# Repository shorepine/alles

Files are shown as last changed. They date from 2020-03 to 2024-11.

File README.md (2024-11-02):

# Alles - the mesh synthesizer

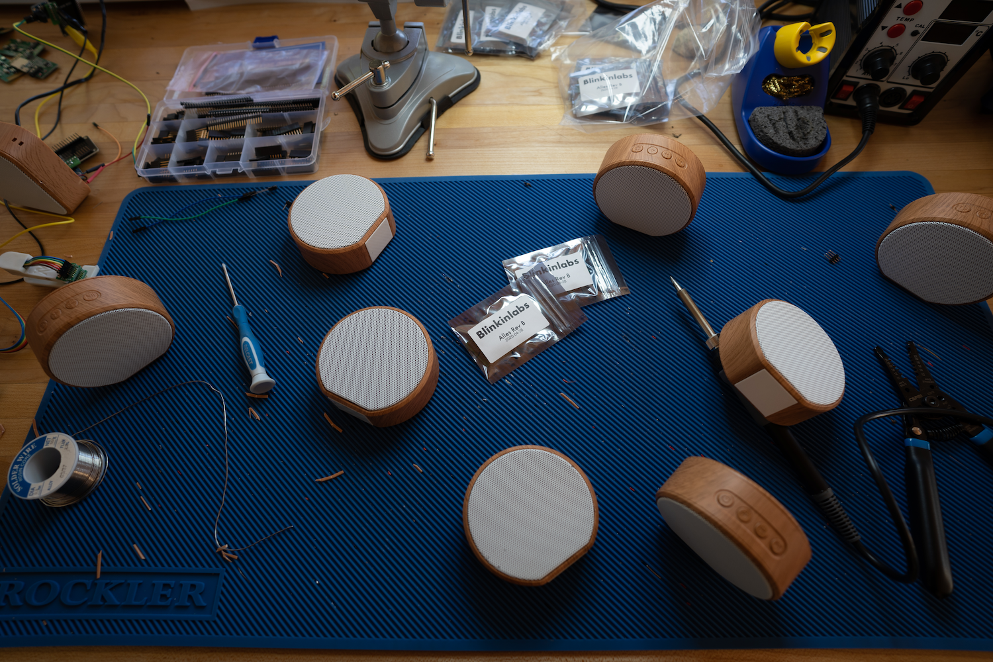
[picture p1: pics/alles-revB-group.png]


 [shore pine sound systems discord **Chat about Alles on our Discord!**](https://discord.gg/TzBFkUb8pG)

**Check out this video!**

The Alles mesh networking synthesizer - a field of sound at your control (https://www.youtube.com/watch?v=8CmcsQXHVEo "The Alles mesh networking synthesizer - a field of sound at your control")

**Alles** is a many-speaker distributed mesh synthesizer that responds over WiFi. Each synth -- there can be hundreds in a mesh -- supports up to 120 additive oscillators, with filters, modulation / LFOs and ADSRs per oscillator. The mesh of speakers can be composed of any combination of our custom hardware speakers or programs running on computers. The software and hardware are open source: you can build it yourself or buy a PCB from us. 

The synthesizers automatically form a mesh and listen to multicast WiFi messages. You can control the mesh from a host computer using any programming language or environments like Max or Pd. 

We intended their first use as distributed / spatial version of an [Alles Machine](https://en.wikipedia.org/wiki/Bell_Labs_Digital_Synthesizer) / [Atari AMY](https://www.atarimax.com/jindroush.atari.org/achamy.html) additive synthesizer where each speaker represents up to 64 partials, all controlled as a group or individually. But you can just treat them as dozens of individual synthesizers and do whatever you want with them. It's pretty fun!

Want to try it today? [Build your own Alles](#diy-alles), or [install the software version](#using-it----software-alles
), and then read our [getting started tutorial!](https://github.com/shorepine/alles/tree/main/getting-started.md)

## Synthesizer specs

Each individual synth is powered by the [AMY synthesizer library](https://github.com/shorepine/amy/blob/main/README.md), you can read more details there. 

## Using it -- hardware Alles

On first boot, each hardware speaker will create a captive wifi network called `alles-synth-X` where X is some ID of the synth. Join it (preferably on a mobile device), and you should get redirected to a captive wifi setup page. If not, go to `http://10.10.0.1` in your browser after joining the network. Once you tell each synth what the wifi SSID and password you want it to join are, it will reboot. You only need to do that once per synth.

## Using it -- software Alles

If you don't want to build or buy an Alles speaker, you can run Alles locally on your computer(s), as many as you want. As long as each copy of the software is running within the same network, they will automatically form in the mesh just like the hardware speakers. And the hardware and software speakers can be used interchangeably.

To build and run `alles` on a computer, simply clone this repository and

```bash
$ cd alles/main
$ make
$ ./alles
$ ./alles -h # shows all the useful commandline parameters, like changing which channel/sound card, or source IP address
```

## Controlling the mesh

**Check out our brand new [Getting Started](https://github.com/shorepine/alles/tree/main/getting-started.md) page for a tutorial!**

You can control every synth on the mesh from a single host, using UDP over WiFi. You can address any synth in the mesh or all of them at once with one message, or use groups. This method can be used in music environments like Max or Pd, or by musicians or developers using languages like Python, or for plug-in developers who want to bridge Alles's full features to DAWs.

Alles's wire protocol is a series of numbers delimited by ascii characters that define all possible parameters of an oscillator. This is a design decision intended to make using Alles from any sort of environment as easy as possible, with no data structure or parsing overhead on the client. It's also readable and compact, far more expressive than MIDI and can be sent over network links, UARTs, or as arguments to functions or commands. 

Alles accepts commands in ASCII, each command separated with a `Z` (you can group multiple messages in one, to avoid network overhead if that's your transport). Like so:

```
v0w4f440.0l0.9Z
```

See [AMY's readme](https://github.com/shorepine/amy/blob/main/README.md) for the full list of synth parameters.

## alles.py 

Alles comes with its own full-featured client, written in Python. Feel free to adapt it or use it in your own clients. It can be seen as documentation, an API as well as a testing suite. You simply `import alles` and can control the entire mesh.

```bash
$ python3
>>> import alles
>>> alles.drums() # plays a drum pattern on all synths
>>> alles.drums(client=2) # just on one 
```

To see more examples, check out our brand new [Getting Started](https://github.com/shorepine/alles/tree/main/getting-started.md) page.

## Addressing individual synthesizers

By default, a message is played by all booted synthesizers. But you can address them individually or in groups using the `client` parameter.

The synthesizers form a mesh that self-identify who is running. They get auto-addressed `client_id`s starting at 0 through 255. The first synth to be booted in the mesh gets `0`, then `1`, and so on. If a synth is shut off or otherwise no longer sends a heartbeat signal to the mesh, the `client_ids` will reform so that they are always contiguous. A synth may take 10-20 seconds to join the mesh and get assigned a `client_id` after booting, but it will immediately receive messages sent to all synths. 

The `client` parameter wraps around given the number of booted synthesizers to make it easy on the composer. If you have 6 booted synths, a `client` of 0 only reaches the first synth, `1` only reaches the 2nd synth, and a client of `7` reaches the 2nd synth (`7 % 6 = 1`). 

Setting `client` to a number greater than 255 allows you to address groups. For example, a `client` of 257 performs the following check on each booted synthesizer: `my_client_id % (client-255) == 0`. This would only address every other synthesizer. A `client` of 259 would address every fourth synthesizer, and so on.

You can read the heartbeat messages on your host if you want to enumerate the synthesizers locally, see `sync` below. 

## Timing & latency

Alles is not designed as a low latency real-time performance instrument, where your actions have an immediate effect on the sound. Changes you make on the host will take a fixed latency -- currently set at 1000ms by default -- to get to every synth. This fixed latency ensures that messages arrive to every synth -- both ESP32 based and those running on computers -- in the mesh in time to play in perfect sync, even though Wi-Fi's transmission latency varies widely. This allows you to have millisecond-accurate timing in your performance across dozens of speakers in a large space.

Your host should send along the `time` parameter of the relative time when you expect the sound to play. I'd suggest using the number of milliseconds since your host started, e.g. in Python:

```python
def millis():
    d = datetime.datetime.now()
    return int((datetime.datetime.utcnow() - datetime.datetime(d.year, d.month, d.day)).total_seconds()*1000)
```

If you're using `alles.py`, we do this for you!

If using Max, use the `cpuclock` object as the `time` parameter.

The first time you send a message with `time` the synth mesh uses it to figure out the delta between its time and your expected time. (If you never send a time parameter, you're at the mercy of WiFi jitter.) Further messages will be millisecond accurate message-to-message, but with the fixed latency. You can adapt `time` per client if you want to account for speed-of-sound delay. 

The `time` parameter is not meant to schedule things far in the future on the clients. If you send a new `time` that is outside 20,000ms from its expected delta, the clock base will re-compute. Your host should be the main "sequencer" and keep track of performance state and future events. 

Latency is adjustable, if you are comfortable with your network you can set it lower, or if using a local (127.0.0.1) connection, or directly sending messages in code, you can set it to 0. 

## Enumerating synths

The `sync` command (see `alles.sync()`) triggers an immediate response back from each on-line synthesizer. The response looks like `_s65201i4c248y2`, where s is the time on the client, i is the index it is responding to, y has battery status (for versions that support that) and c is the client id. This lets you build a map of not only each booted synthesizer, but if you send many messages with different indexes, will also let you figure the round-trip latency for each one along with the reliability. 

## WiFi & reliability for performances

UDP multicast is naturally 'lossy' -- there is no guarantee that a message will be received by a synth. Depending on a lot of factors, but most especially your wireless router and the presence of other devices, that reliability can sometimes go as low as 70%. For performance purposes, I highly suggest using a dedicated wireless router instead of an existing WiFi network. You'll want to be able to turn off many "quality of service" features (these prioritize a randomly chosen synth and will make sync hard to work with), and you'll want to in the best case only have synthesizers as direct WiFi clients. An easy way to do this is to set up a dedicated wireless router but not wire any internet into it. Connect your laptop or host machine to the router over a wired connection (via a USB-ethernet adapter if you need one), but keep your laptop's wifi or other internet network active. In your controlling software, you simply set the source network address to send and receive multicast packets from. `alles_util.py` has setup code for this. This will keep your host machine on its normal network but allow you to control the synths from a second interface.

If you're in a place where you can't control your network, you can mitigate reliability by simply sending messages N times. Sending multiple duplicate messages (with the same `time` parameter) do not have any adverse effect on the synths.

## Clients

Minimal Python example:

```python
import socket
multicast_group = ('232.10.11.12', 9294)
sock = socket.socket(socket.AF_INET, socket.SOCK_DGRAM)

def send(oscillator=0, freq=0, vel=1):
    sock.sendto("v%df%fl%fZ" % (oscillator, freq, vel), multicast_group)

def c_major(octave=2):
    send(oscillator=0,freq=220.5*octave)
    send(oscillator=1,freq=138.5*octave)
    send(oscillator=2,freq=164.5*octave)

```

See [`alles.py`](https://github.com/shorepine/alles/blob/main/alles.py) for a better example. Any language that supports sockets and multicast can work, I encourage pull requests with new clients!

You can also easily use it in Max or Pd:

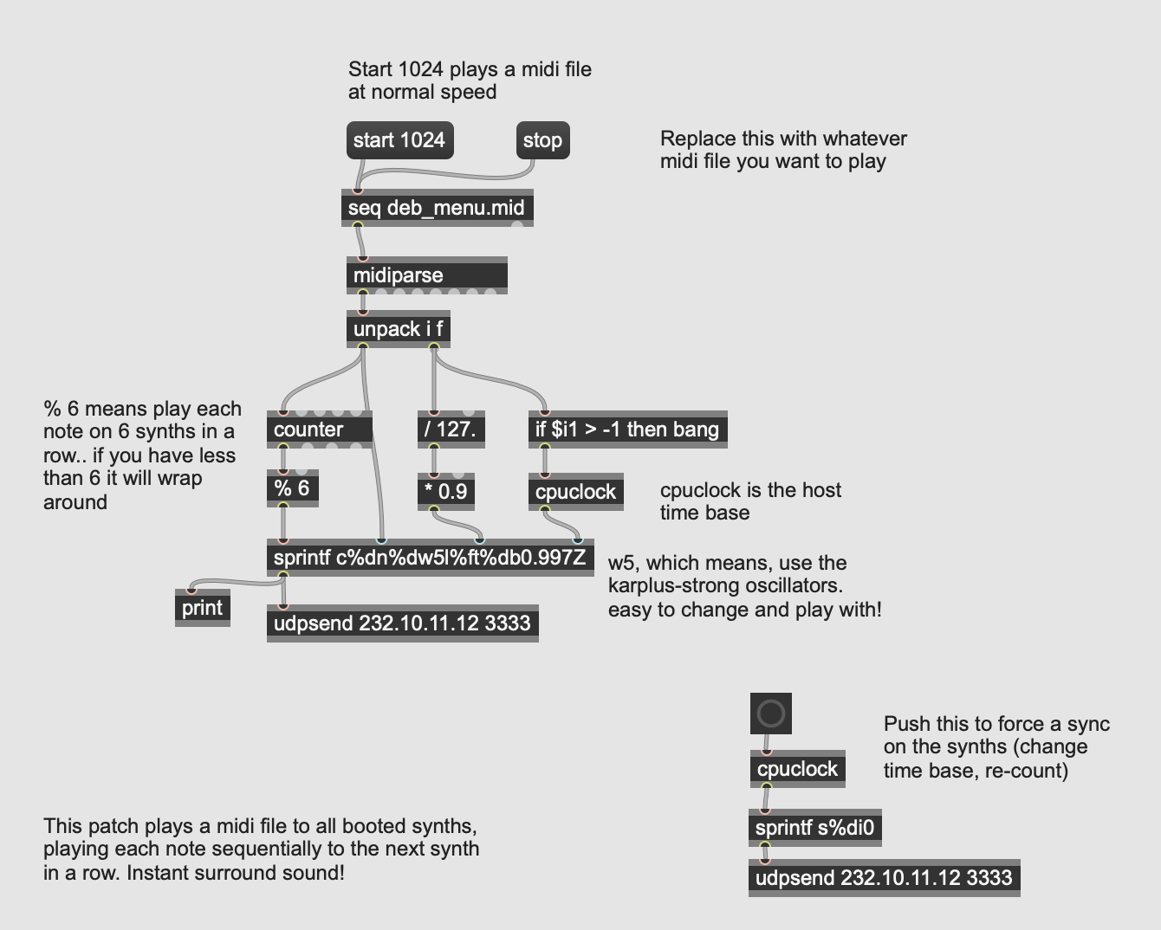
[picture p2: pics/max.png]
Max


# Synthesizer Details

See [AMY's readme](https://github.com/shorepine/amy/blob/main/README.md) for more details on the synthesizer itself.

# Get your own Alles!

**[Read here how to install a PCB into a speaker shell!](speaker-assembly.md)**

If you want the small circular speakers shown on this page and videos, they are easy to get. Here's a link to them on Alibaba: [the round A60s](https://www.alibaba.com/product-detail/A60-Wooden-Grain-Portable-Wireless-Bluetooth_1600291216741.html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) – the [square-shaped A70s](https://www.alibaba.com/product-detail/A70-Wood-Speaker-Grain-Portable-Wireless_1600291333969.html) also work! You then can buy an Alles PCB from us with no terminals for speaker and battery -- the connections for the shell solder directly to the board. It takes me about 3 minutes to assemble the Alles PCB inside the A60 or A70 speaker. To do it this way, you only need a wire stripper, a small screwdriver and a soldering iron. 
 
**IMPORTANT:** Alles is sold on a "best effort" community support basis. We will send you working PCBs with the latest Alles firmware loaded on them. Anything that happens after that is up to the community to help with. Alles requires a little bit of computer and networking know-how to get going. We've made it as easy as possible, we hope, but we know we have more work to do before this is ready for a very wide audience. Please use GitHub issues for anything you're having trouble with and we'll do our best to help you figure it out. 

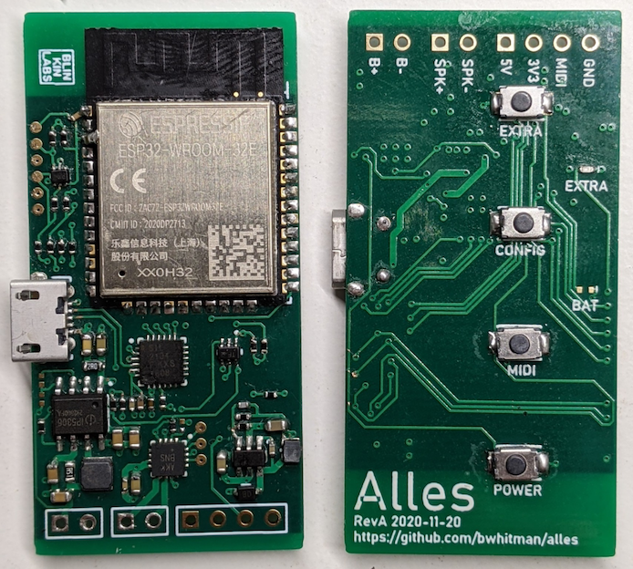
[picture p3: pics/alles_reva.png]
blinkinlabs PCB


## DIY Alles

It's very simple to make one yourself with parts you can get from electronics distributors like Sparkfun, Adafruit or Amazon. 

To make an Alles synth yourself, you need

* [ESP32 dev board (any one will do, but you want pins broken out)](https://www.amazon.com/gp/product/B07Q576VWZ/) (pack of 2, $7.45 each). Try to get a 8MB flash on yours if you want to have over-the-air updating.
* [The Adafruit I2S mono amplifier](https://www.adafruit.com/product/3006) ($5.95)
* [4 ohm speaker, this one is especially nice](https://www.parts-express.com/peerless-by-tymphany-tc6fd00-04-2-full-range-paper-cone-woofer-4-ohm--264-1126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) ($9.77, but you can save a lot of money here going lower-end if you're ok with the sound quality). I also like speakers with prebuilt cases, like [these bookshelf speakers](https://www.amazon.com/Pyle-PCB3BK-100-Watt-Bookshelf-Speakers/dp/B000MCGF1O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).
* A breadboard, custom PCB, or just some hookup wire!

A 5V input (USB battery, USB input, rechargeable batteries direct to power input) powers both boards and speaker at pretty good volumes. A 3.7V LiPo battery will also work, but note the I2S amp will not get as loud (without distorting) if you give it 3.7V. If you want your DIY Alles to be portable, I recommend using a USB battery pack that does not do [low current shutoff](https://www.element14.com/community/groups/test-and-measurement/blog/2018/10/15/on-using-a-usb-battery-for-a-portable-project-power-supply). The draw of the whole unit at loud volumes is around 90mA, and at idle 40mA. 

Wire up your DIY Alles like this (I2S -> ESP)

```
LRC -> GPIO25
BCLK -> GPIO26
DIN -> GPIO27
GAIN -> I2S Vin (i jumper this on the I2S board)
SD -> not connected
GND -> GND
Vin -> Vin / USB / 3.3 (or direct to your 5V power source)
Speaker connectors -> speaker
```

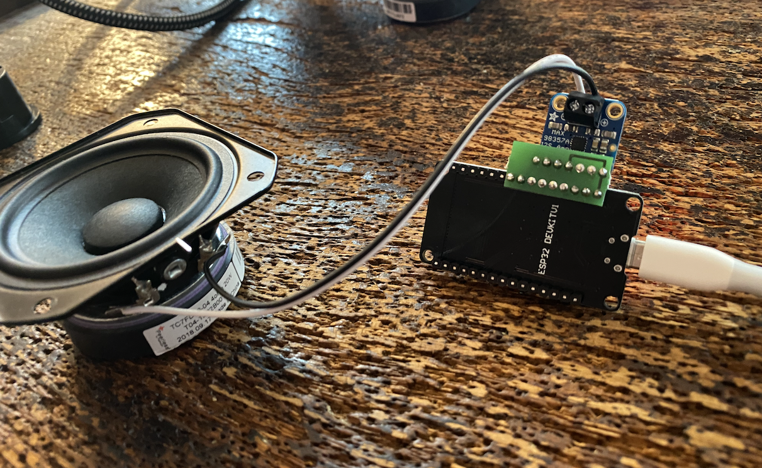
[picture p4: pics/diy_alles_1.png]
DIY Alles 1

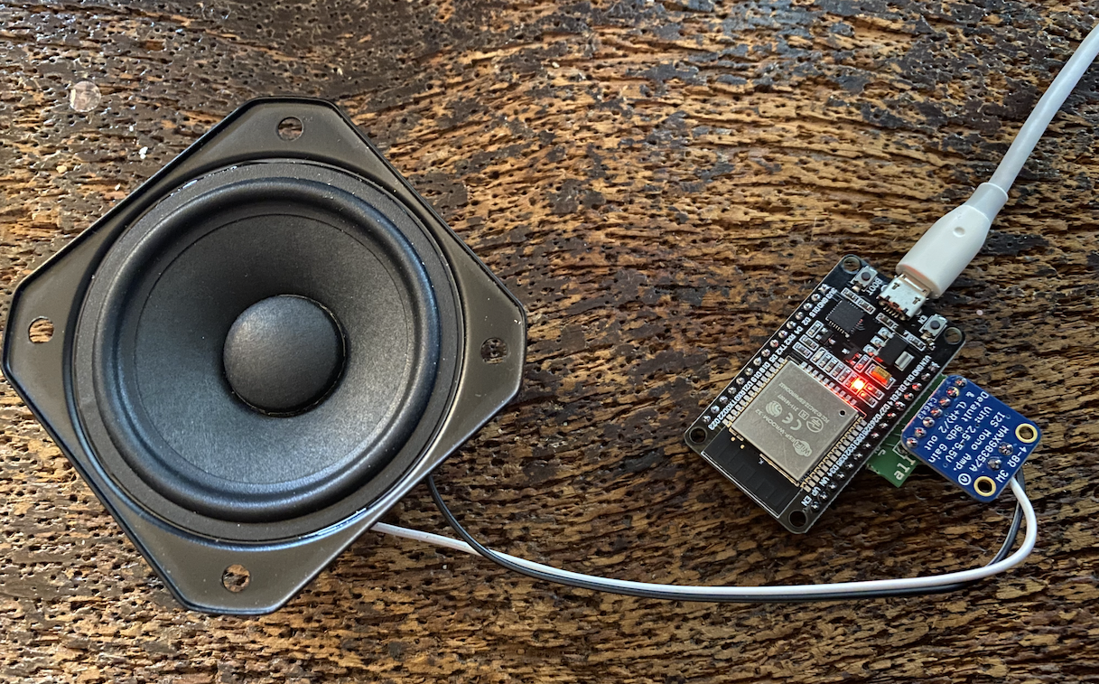
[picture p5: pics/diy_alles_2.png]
DIY Alles 2


### DIY bridge PCB

*You don't need this PCB made to build a DIY Alles!* -- it will work with just hookup wire. But if you're making a lot of DIY Alleses want more stability, I had a tiny little board made to join the boards together, like so:

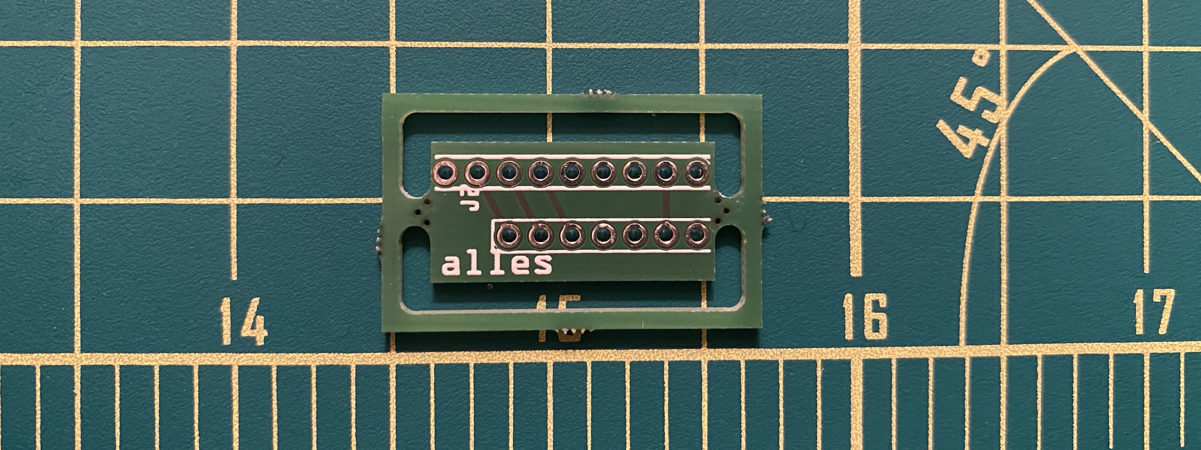
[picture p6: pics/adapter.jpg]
closeup


This assumes you're using the suggested ESP32 dev board with its pin layout. If you use another one, you can probably change the GPIO assignments in `alles.h`. Fritzing file in the `pcbs` folder of this repository, and [it's here on Aisler](https://aisler.net/p/TEBMDZWQ). This is a lot more stable and easier to wire up than snipping small bits of hookup wire, especially for the GAIN connection. 

## Disabling OTA for 4MB boards

If you are using your own dev board and it has less than 8MB of flash (4MB is common), first overwwrite `alles_partitions.csv` with the contents of`alles_4mb_partitions.csv` as well as run `idf.py menuconfig` and change the flash size from 8MB to 4MB (in Serial Flasher Config) -- this will disable the OTA firmware upgrading, but will otherwise work fine. The binary for Alles is almost 4MB total and OTA needs space for two copies to be stored on the flash.

## ESP32 Firmware

Alles is completely open source, and can be a fun platform to adapt beyond its current capabilities. 

You can upgrade the firmware or write your own using the USB connection. [See the guide on flashing a hardware Alles speaker](https://github.com/shorepine/alles/tree/main/alles-flashing.md) (either DIY or one of ours). 

## THANK YOU TO

* Alles would not be possible without the help of [DAn Ellis](https://research.google/people/DanEllis/), who helped me with most of the oscillator stack, a lot of deep dives into our algorithm synth, and many great ideas / fixes on the ESP32 code.
* Douglas Repetto
* [Raph Levien](https://www.levien.com) for his work on [MSFA](https://github.com/google/music-synthesizer-for-android) which gave us a lot of hints for our FM implementation
* mark fell
* [esp32 WiFi Manager](https://github.com/tonyp7/esp32-wifi-manager)
* kyle mcdonald 
* Matt Mets / [Blinkinlabs](https://blinkinlabs.com)

## TODO

* ~~power button~~
* ~~wifi setup should ask for default power saving / latency -- no for now~~
* ~~remove distortion at higher amplitudes for mixed sine waves~~
* ~~FM~~
* ~~should synths self-identify to each other? would make it easier to use in Max~~
* ~~see what you can do about wide swings of UDP latency on the netgear router~~
* ~~envelopes / note on/offs / LFOs~~
* ~~confirm UDP still works from Max/Pd~~
* ~~bandlimit the square/saw/triangle oscillators~~
* ~~karplus-strong~~ 
* ~~wifi hotspot mode for in-field setup~~
* ~~broadcast UDP for multiples~~
* ~~dropped packets~~
* ~~sync and enumerate across multiple devices~~
* ~~addresses / communicate to one or groups, like "play this on half / one-quarter / all"~~
* ~~do what i can about timing / jitter - sync time? timed messages?~~
* ~~case / battery setup~~
* ~~overloading the volume (I think only on FM) crashes~~
* ~~UDP message clicks~~
* desktop USB flasher
* BT / app based config instead of captive portal (later)

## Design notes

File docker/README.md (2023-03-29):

# Docker container for Alles production

These scripts build the Alles firmwware in a container, using a fully isloated
ESP-IDF toolchain.

To build it, you'll need a Linux computer with [Docker](https://docs.docker.com/engine/install/ubuntu/) installed. Any OS capable of running Docker can work to build the image, however a Linux-based system is required to flash devices through the container.

You will aslo need make and git; you can install them on Ubuntu like so:

    sudo apt update
    sudo apt install build-essential git

Once you have these prerequisites, clone the repository, then build the Docker image:

    git clone https://github.com/blinkinlabs/alles.git
    cd alles/docker
    make build-docker

This will take a little while. Once it is done, you can build the firmware in the container:

    make build

Once the firmware is built, flash an attached Alles device:

    make flash

Note: The above assumes that the USB-to-serial converter in the Alles was detected as /dev/ttyUSB0; if it was mounted somewhere else, you can specify the position:

    PORT=/dev/ttyXXXX make flash

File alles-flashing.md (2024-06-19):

# Alles Flashing HOWTO

This page will help you upgrade your own firmware on an Alles hardware speaker.

## Upgrading firmware wirelessly / OTA

**If you have a recent model (you received it after November 2021), or flashed your firmware after November 2021, you can upgrade your firmware over the internet wirelessly, called OTA, "over-the-air."**

After you first set up wifi (and make sure your speaker is on a wifi network that can connect to the internet,) if you turn off, then on the speaker, then press the + button while the "joining wifi" tones are playing (in the few seconds before it plays the turn-on bleep), the speaker will connect to the internet and download the [latest released Alles speaker firmware](https://github.com/shorepine/alles/blob/main/ota/alles.bin) right to the device, then reboot. It takes about a minute, and you'll hear a different (sometimes glitchy sounding -- that's ok --) repeating tone while it works. 

## Upgrading firmware over USB

If you want to write your own Alles firmware, or have a speaker before December 2021 and need to get it to support wireless upgrading, follow these directions:

The back of the hardware speaker has a micro-USB plug you use for charging. It also can be used to upgrade the firmware. Once you upgrade an Alles speaker to a recent version, you can use the wireless / OTA flashing method going forward. 

To do this, you need to set up the following things:

### Set up ESP-IDF

ESP-IDF is the set of open source tools and libraries that work on the CPU powering Alles, the ESP32. You should first install ESP-IDF on your system if you haven't already. 

Download the supported version of ESP-IDF. That is currently 5.2. [You can download it directly here.](https://dl.espressif.com/github_assets/espressif/esp-idf/releases/download/v5.2/esp-idf-v5.2.zip) Unpack it to a folder. I like to keep them in `~/esp/`, as you'll likely want to use different versions eventually. So we'll assume it's in `~/esp/esp-idf-v5.2`.

```
# install ESP-IDF that comes with our repository
~/esp/esp-idf-v5.2/install.sh esp32
source ~/esp/esp-idf-v5.2/export.sh
```

If you have trouble, for more info, or for other platforms, you should follow [the detailed instructions to download and set up `esp-idf`](http://esp-idf.readthedocs.io/en/latest/get-started/). 

### Get the UART drivers

If using macOS, you'll want to also install the [CP210X drivers](https://www.silabs.com/developers/usb-to-uart-bridge-vcp-drivers) if you haven't already. 

### Get the Alles repository

You likely already have this, but if not, [clone this repository](https://github.com/shorepine/alles).

### Get a real micro-USB cable 

The cable you may have received from us for the hardware speaker is charge only. Find a longer micro-USB cable that transmits data and connect it to the computer and speaker. 

### Flash

Then, in the `esp` folder you created during installing the ESP-IDF above (e.g. `cd ~/esp`), run `. ./esp-idf-v5.2/export.sh`. Now, in the same terminal window (export.sh sets some environment variables), cd back into the alles repository folder you downloaded and run `idf.py flash` to build and flash to the board. It will take a couple of minutes and show you progress. The board will reboot into the latest firmware. 

(If the flashing process doesn't work, it's likely not finding your UART location. Type `ls /dev/*usb*` to find something like `/dev/tty.usbserial.XXXXX` or `/dev/cu.usbserialXXXX`.  You'll want to find the tty that appears when you connect the speaker to computer. Copy this location and try flashing again with `idf.py -p /dev/YOUR_SERIAL_TTY flash`.)

### Monitor

If you want to see debugging messages, use `idf.py -p /dev/YOUR_SERIAL_TTY monitor` to reboot the board and see stdout/stderr. Use Ctrl-] to exit the monitor.

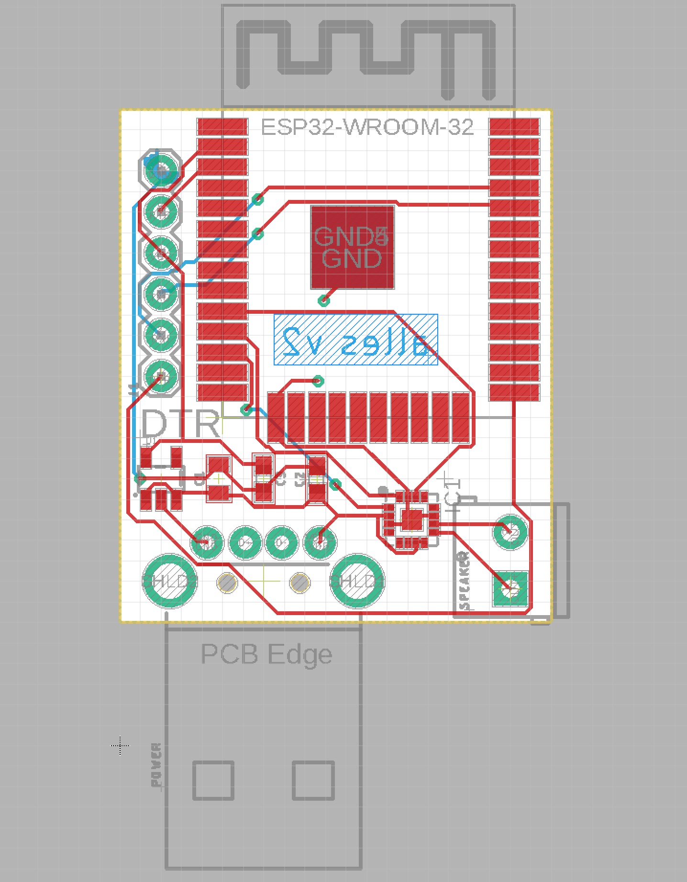
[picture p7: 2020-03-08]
pics/alles-board.jpg

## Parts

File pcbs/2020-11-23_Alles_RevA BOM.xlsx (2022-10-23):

Designator | Comment | Manufacturer | PartNumber | Digi-Key Part Number | LCSC PartNumber | Description | Pins | Quantity | Model:Footprint | Case/Package
C1, C4, C7 | 0.10uF | Murata Electronics North America | GRM152R61A104ME19D | 490-10009-1-ND |  | CAP CER 0.1UF 10V X5R 0402 | 2 | 3 |  | 0402
C2, C6, C8, C18 | 10uF | Murata Electronics North America | GRM188C81A106MA73D, GRM188R61A106KE69D | 490-7197-1-ND, 490-10474-1-ND |  | CAP CER 10UF 10V X6S 0603, CAP CER 10UF 10V X5R 0603 | 2 | 4 |  | 0603
C3 | 1uF | Murata Electronics North America | GRM155R61A105KE15D | 490-3890-1-ND |  | CAP CER 1UF 10V X5R 0402 | 2 | 1 |  | 0402
C5 | 4.7uF | Murata Electronics North America | GRM155R60J475ME47D | 490-5915-1-ND |  | CAP CER 4.7UF 6.3V X5R 0402 | 2 | 1 |  | 0402
C9, C10, C11, C12, C21 | 22uF | Murata Electronics North America | GRM187R61A226ME15D | 490-13243-1-ND |  | CAP CER 22UF 10V X5R 0603 | 2 | 5 |  | 0603
C22 | 33pF | Murata Electronics North America | GRM1555C1E330JA01D | 490-6177-1-ND |  | CAP CER 33PF 25V NP0 0402 | 2 | 1 |  | 0402
D1 | ZHCS400TA | DiodesIncorporated |  |  |  | Schottky Barrier Diode, 40 V, 0.4 A, -55 to 150 degC, 2-Pin SMD, RoHS, Tape and Reel | 2 | 1 | SOD-323, 2-Leads, Body 1.7x1.3mm, Lead Span 2.5mm
DS1 | BL-HUB37A-AV-TRB | BrtLed(佰鸿) | BL-HUB37A-AV-TRB |  | C165980 | LED, 0402, Super Red, 50mcd@20mA, 627~637nm | 2 | 1 | 0402 LED, generic
DS3 | BL-HB337A-AV-TRB | BrtLed(佰鸿) | BL-HB337A-AV-TRB |  | C165977 | LED, 0402, Blue, 20mcd@5mA, 465~470nm | 2 | 1 | 0402 LED, generic
J1 | A01SB741B1-267 | Unknown/Generic | Unknown/Generic |  |  | Micro USB B type 四脚全插牛角 | 11 | 1 | micro usb B type
L2 | 1uH | Sunlord | SWPA3010S1R0NT |  | C57625 | 1uH ±30% 1.4A 85mΩ SMD,3.0x3.0x1.0mm Power Inductors RoHS | 2 | 1 |  | SMD,3.0x3.0x1.0mm
L3 | 6.8uH | Changjiang Microelectronics Tech | FNR201610S6R8MT |  | C167675 | 6.8uH ±20% 520mA 816mΩ SMD,2.0x1.6x1.0mm Power Inductors RoHS | 2 | 1 |  | SMD,2.0x1.6x1.0mm
P1 | Header 2 |  |  |  |  | Header, 2-Pin | 2 | 1 | Connector; Header; 2 Position
P2 | Battery |  |  |  |  | Header, 2-Pin | 2 | 1 | Connector; Header; 2 Position
P3 | Header 4 |  |  |  |  | Header, 4-Pin | 4 | 1 | Connector; Header; 4 Position
Q1 | EMX1DXV6T1G | On Semiconductor | EMX1DXV6T1G |  |  | Dual NPN General Purpose Amplifier Transistors, 6-Pin SOT-563, Pb-Free, Tape and Reel | 6 | 1 | SOT23, 6-Leads, Body 1.6x1.2mm, Pitch 0.5mm
Q2 | NTJD5121NT1G | On Semiconductor |  |  |  | MOSFET 2N-CH 60V 0.295A SOT363 | 6 | 1
R1, R2, R4, R5, R6, R7, R21 | 0.0 | Panasonic Electronic Components | ERJ-2GE0R00X | P0.0JCT-ND |  | RES SMD 0.0OHM JUMPER 1/10W 0402 | 2 | 7 |  | 0402
R3, R11, R13, R15, R22, R23 | 10k | Panasonic Electronic Components | ERJ-2GEJ103X | P10KJCT-ND |  | RES SMD 10K OHM 5% 1/10W 0402 | 2 | 6 |  | 0402
R8 | 1.5k | Panasonic Electronic Components | ERJ-2GEJ152X | P1.5KJCT-ND |  | RES SMD 1.5K OHM 5% 1/10W 0402 | 2 | 1 |  | 0402
R9 | 0.51 | Panasonic Electronic Components | ERJ-3BQFR51V | P17401CT-ND |  | RES SMD 0.51 OHM 1% 1/4W 0603 | 2 | 1 |  | 0603
R10 | 2 | Panasonic Electronic Components | ERJ-3BQJ2R0V | P17414CT-ND |  | RES SMD 2 OHM 5% 1/4W 0603 | 2 | 1 |  | 0603
R12 | 1k | Panasonic Electronic Components | ERJ-2GEJ102X | P1.0KJCT-ND |  | RES SMD 1K OHM 5% 1/10W 0402 | 2 | 1 |  | 0402
R14, R16 | 100k | Panasonic Electronic Components | ERJ-2GEJ104X | P100KJCT-ND |  | RES SMD 100K OHM 5% 1/10W 0402 | 2 | 2 |  | 0402
R17 | 127k | Panasonic Electronic Components | ERJ-2RKF1273X | P127KLCT-ND |  | RES SMD 127K OHM 1% 1/10W 0402 | 2 | 1 |  | 0402
R18 | 23.7k | Panasonic Electronic Components | ERJ-2RKF2372X | P23.7KLCT-ND |  | RES SMD 23.7K OHM 1% 1/10W 0402 | 2 | 1 |  | 0402
R19, R20 | 2.1k | Panasonic Electronic Components | ERJ-2RKF2101X | P2.10KLCT-ND |  | RES SMD 2.1K OHM 1% 1/10W 0402 | 2 | 2 |  | 0402
SW1, SW2, SW3, SW4 | TS-1185 | XKB | TS-1185 |  |  | Tact Switch, 3x4mm, no alignment pin, turtle style | 2 | 4 | 3x4x2mm Tact Switch, no alignment pin
U1 | ESP32-WROOM-32E(4MB) | Espressif Systems | ESP32-WROOM-32E(4MB) |  | C701341 | 32-bit MCU & 2.4 GHz Wi-Fi & Bluetooth/Bluetooth LE | 39 | 1 | ESP32 module, with shorter solder pads
U2 | MAX98357AETE+ |  |  |  |  | IC AMP CLASS D MONO 3.2W 16TQFN | 17 | 1
U3 | BL9352A | Belling | BL9352A |  | C193985 | 45V, 1.6MHz, 600mA Step-Down Converter | 6 | 1 | SOT23, 6-Leads, Body 2.92x2.80mm, Pitch 0.95mm, IPC Medium Density
U4 | IP5306 | INJOINIC | IP5306 |  | C181692 | Fully-Integrated Power Bank System-On-Chip with 2.1A charger, 2.4A discharger | 9 | 1 | SOP, 8-Leads, Body 5.00x3.90mm, Pitch 1.27mm, Thermal Pad 3.10x2.21mm, IPC Medium Density
U15 | CP2104-F03-GM | Silicon Labs | CP2104-F03-GM |  |  | Single-Chip USB to UART Bridge, 4 Dig I/O Pins, Internal Oscillator, 1024 Bytes EEPROM, -40 to 85 degC, 24-pin QFN | 25 | 1 | QFN, 24-Leads, Body 4x4mm, Pitch 0.5mm, Thermal Pad 2.68x2.68mm, IPC Low Density

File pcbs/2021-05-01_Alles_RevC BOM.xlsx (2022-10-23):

Designator | Comment | Manufacturer | PartNumber | Digi-Key Part Number | LCSC PartNumber | Description | Pins | Quantity | Model:Footprint | Case/Package
C1, C10, C12, C14 | 4.7uF | Murata Electronics North America | GRM188R61A475KE15D | 490-10477-1-ND |  | CAP CER 4.7UF 10V X5R 0603 | 2 | 4 |  | 0603
C2, C6, C13 | 10uF | Murata Electronics North America | GRM188R61A106KE69D, GRM188R60J106ME84D | 490-10474-1-ND, 490-7316-1-ND |  | CAP CER 10UF 10V X5R 0603, CAP CER 10UF 6.3V X5R 0603 | 2 | 3 |  | 0603
C3 | 1uF | Murata Electronics North America | GRM155R61A105KE15D | 490-3890-1-ND |  | CAP CER 1UF 10V X5R 0402 | 2 | 1 |  | 0402
C4, C7, C9, C11, C15 | 0.10uF | Murata Electronics North America | GRM152R61A104ME19D, GRM155R61C104KA88J | 490-10009-1-ND, 490-6310-1-ND |  | CAP CER 0.1UF 10V X5R 0402, CAP CER 0.1UF 16V X5R 0402 | 2 | 5 |  | 0402
C5 | 4.7uF | Murata Electronics North America | GRM185R61A475KE11D | 490-11988-1-ND |  | CAP CER 4.7UF 10V X5R 0603 | 2 | 1 |  | 0603
C8, C16 | 22uF | Murata Electronics North America | GRM187R61A226ME15D | 490-13243-1-ND |  | CAP CER 22UF 10V X5R 0603 | 2 | 2 |  | 0603
D1 | MBR0520LT1G |  |  |  |  | DIODE SCHOTTKY 20V 500MA SOD123 | 2 | 1 |  | SOD-123-2
J1 | A01SB741B1-267 | Unknown/Generic | Unknown/Generic |  |  | Micro USB B type 四脚全插牛角 | 11 | 1 | micro usb B type
L2, L3 | 1uH | Changjiang Microelectronics Tech | FNR201610S1R0MT |  | C167670 | 1uH ±20% 1.45A 114mΩ SMD,2.0x1.6x1.0mm Power Inductors RoHS | 2 | 2 |  | SMD,2.0x1.6x1.0mm
P1 | Header 2 |  |  |  |  | Header, 2-Pin | 2 | 1 | Connector; Header; 2 Position
P2 | Battery |  |  |  |  | Header, 2-Pin | 2 | 1 | Connector; Header; 2 Position
P3 | Header 4 |  |  |  |  | Header, 4-Pin | 4 | 1 | Connector; Header; 4 Position
Q1 | EMX1DXV6T1G | On Semiconductor | EMX1DXV6T1G |  |  | Dual NPN General Purpose Amplifier Transistors, 6-Pin SOT-563, Pb-Free, Tape and Reel | 6 | 1 | SOT23, 6-Leads, Body 1.6x1.2mm, Pitch 0.5mm
Q2 | DMC3400SDW-7 | Diodes Inc. |  |  |  | MOSFET N/P-CH 30V SOT363 | 6 | 1
Q3 | DMP3099L-13 |  |  |  |  | MOSFET P-CH 30V 3.8A SOT23 | 3 | 1 |  | TO-236-3
R1, R4, R14, R16, R18, R19, R20, R25 | 100k | Panasonic Electronic Components | ERJ-2GEJ104X | P100KJCT-ND |  | RES SMD 100K OHM 5% 1/10W 0402 | 2 | 8 |  | 0402
R2 | 0.0 | Panasonic Electronic Components | ERJ-2GE0R00X | P0.0JCT-ND |  | RES SMD 0.0OHM JUMPER 1/10W 0402 | 2 | 1 |  | 0402
R3, R5, R11, R13, R15, R21, R22 | 10k | Panasonic Electronic Components | ERJ-2GEJ103X | P10KJCT-ND |  | RES SMD 10K OHM 5% 1/10W 0402 | 2 | 7 |  | 0402
R8 | 1M | Panasonic Electronic Components | ERJ-2GEJ105X | P1.0MJCT-ND |  | RES SMD 1M OHM 5% 1/10W 0402 | 2 | 1 |  | 0402
R26 | 2k | Panasonic Electronic Components | ERJ-2GEJ202X | P2.0KJCT-ND |  | RES SMD 2K OHM 5% 1/10W 0402 | 2 | 1 |  | 0402
R27 | 100 | Panasonic Electronic Components | ERJ-2RKF1000X | P100LCT-ND |  | RES SMD 100 OHM 1% 1/10W 0402 | 2 | 1 |  | 0402
SW1, SW2, SW3, SW4 | TS-1185 | XKB | TS-1185 |  |  | Tact Switch, 3x4mm, no alignment pin, turtle style | 2 | 4 | 3x4x2mm Tact Switch, no alignment pin
U1 | ESP32-WROOM-32E(4MB) | Espressif Systems | ESP32-WROOM-32E(4MB) |  | C701341 | 32-bit MCU & 2.4 GHz Wi-Fi & Bluetooth/Bluetooth LE | 39 | 1 | ESP32 module, with shorter solder pads
U2 | MAX98357AETE+ |  |  |  |  | IC AMP CLASS D MONO 3.2W 16TQFN | 17 | 1
U3 | ADP2108AUJZ-3.3-R7 |  | ADP2108AUJZ-3.3-R7 |  | C143875 | Compact, 600 mA, 3 MHz, Step-Down DC-to-DC Converter, 3.3V | 5 | 1 | SOT23, 5-Leads, Body 2.90x2.80mm, Pitch 0.95mm, IPC Medium Density
U4 | MIC2875-5.0YMT-T5 | Microchip | MIC2875-5.0YMT-T5 |  |  | 4.8A ISW, Synchronous Boost Regulator with Bi-Directional Load Disconnect | 9 | 1
U5 | MCP73832T-2ACI/OT |  |  |  |  | IC LI-ION/LI-POLY CTRLR SOT23-5 | 5 | 1 |  | SOT-23
U6 | XB5307H | XySemi | XB5307H |  | C154942 | Single-cell Li-ion/Li-polymer rechargeable battery pack protection chip w2.90V cutorff | 6 | 1 | SOT23, 6-Leads, Body 2.92x2.80mm, Pitch 0.95mm, IPC Medium Density
U15 | CP2104-F03-GM | Silicon Labs | CP2104-F03-GM |  |  | Single-Chip USB to UART Bridge, 4 Dig I/O Pins, Internal Oscillator, 1024 Bytes EEPROM, -40 to 85 degC, 24-pin QFN | 25 | 1 | QFN, 24-Leads, Body 4x4mm, Pitch 0.5mm, Thermal Pad 2.68x2.68mm, IPC Low Density

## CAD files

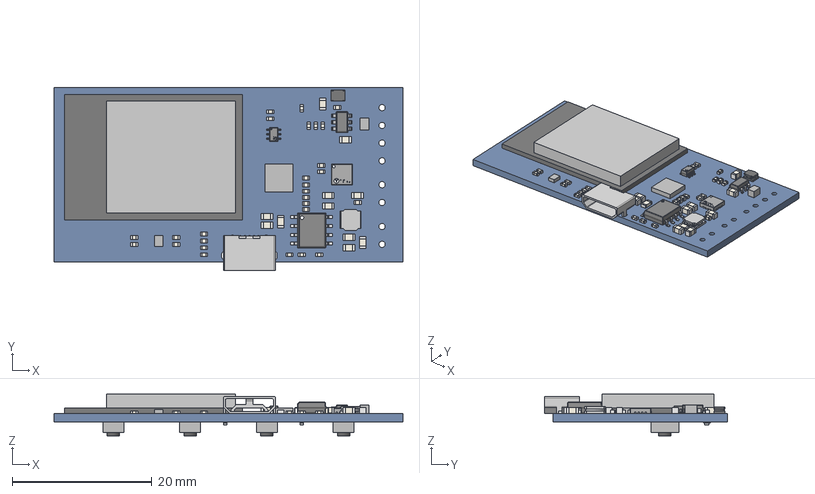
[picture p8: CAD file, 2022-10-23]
pcbs/2020-11-23_Alles_RevA.step
50.0 x 26.3 x 6.00 mm
Extruded x 131
pins
logo
Open_CASCADE_STEP_translator_6.8_3.1.1
Leader x 14
SWPA3010S
FNR201610S_(estimate)_v2
Open_CASCADE_STEP_translator_6.8_2.1
Open_CASCADE_STEP_translator_6.8_2.2.1
A01SB741B1-267_v1
circle
logo002

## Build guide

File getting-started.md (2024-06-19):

# Alles Speaker RevB getting started notes

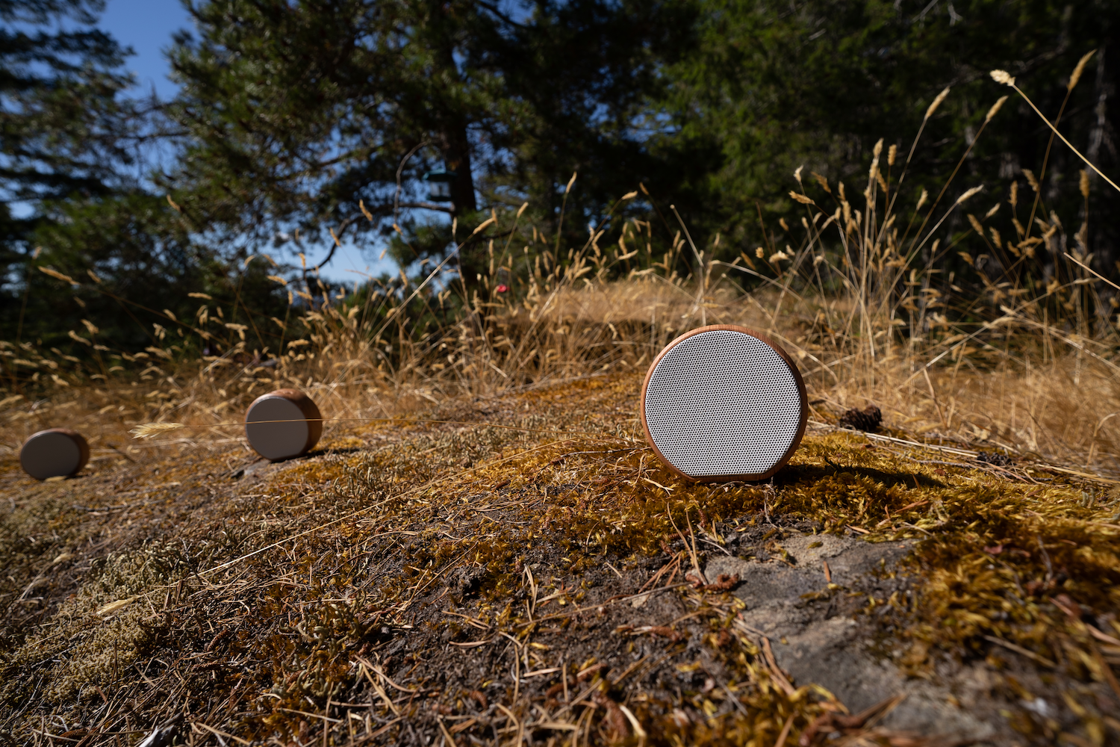
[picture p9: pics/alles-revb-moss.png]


Hello! You're the lucky owner of at least one Alles speaker. This guide will help you get started.

## The Speaker

### Wait, I don't have a speaker yet

That's ok! You can run a software speaker too. Skip down to the section [Setup](#setup) and then do [Alles on your computer](#alles-on-your-computer) to run a software version of the speaker. You can then keep following this guide no problem.

### Back to the hardware speaker 

[Read here on how to get your Alles PCB into a speaker shell!](speaker-assembly.md)

Each Alles speaker has four buttons up top and a USB micro receptacle on back. 

Before getting going, let's make sure the speaker is charged or charging. Simply plug the included USB cable between the speaker and any USB charge point, like a phone charger. (If you hook it into a computer, the speaker will show up as a USB device for debugging and upgrades, but you don't have to worry about that for now -- all control happens wirelessly.) The battery will last "a few hours" making constant music and longer with sparse or silence. It shouldn't take more than an hour or so to charge. If the power button does not make any noise, it's probably a dead battery.

The row of buttons up top, facing the speaker, are power, volume + and -, and WiFi setup (the play/pause). Volume can be set with those buttons or using `alles.volume()` from your compositions. Using `alles.volume()` will override whatever you set with the buttons.

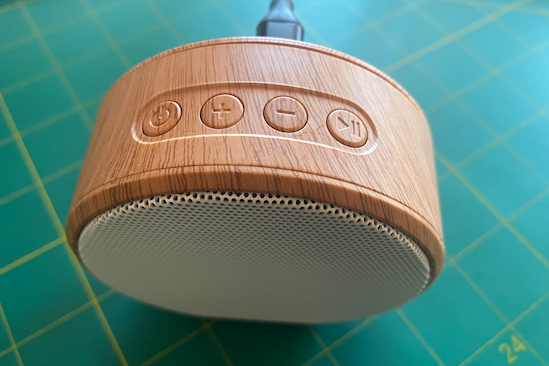
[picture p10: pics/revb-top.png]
Picture of speaker


The power button turns the speaker off and on. When you turn it on, it will re-join the network and mesh. 

The WiFi button will forget the WiFi details, if any were stored, and put the device into WiFi setup mode. This is the default if no WiFi has yet been set. 

## Join a WiFi network

If this is your first time using the speaker, you'll need to tell it which WiFi network to join. You can easily change this later, but once you set it, you don't need to set it again. 

Press the power button. You'll start to hear a "chime noise" repeating. This is the "searching for WiFi" sound, and will play until it finds a WiFi point, or the power button is hit again, or if two minutes goes by, at which point it'll shut off again. 

If you've already set a WiFi network, after about a few seconds the chime noise will end and you'll hear a "bleep" tone and then silence. That means the WiFi network has been joined and everything is ready to go.

If you haven't set WiFi yet, now open your nearest mobile phone or any WiFi device with a browser. Go to join a new WiFi network on your device and you'll see a network listed called `alles-synth-XXXXXX` where `XXXXXX` is a unique string per speaker (useful when you have many speakers!). Join that network. On most devices (iPhones, Androids especially) after a few seconds, a browser window will appear with a login page. This is like when you join a hotel's network or other captive portal. If the page never appears, try going to `http://10.10.0.1` in your browser after joiining the network.

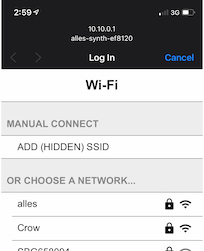
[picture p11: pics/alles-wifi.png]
Alles WiFi settings


Wait a few seconds for the login page to populate with all the nearby WiFi stations it finds. After you see the one you want the speaker to join, tap it and carefully enter its password. This should be the same network as the computer you're going to control Alles from. After a few moments, the speaker should stop chiming, indicating it has succesfully joined the network and saved the details to its internal storage. 

If this doesn't seem to work, try again by hitting the WiFi button (play/pause) and the process will repeat again. 

## Upgrade the firmware

It's helpful to make sure your Alles speaker has the latest firmware. If you have a recent speaker, you can do this wirelesly. If you have an older one, it's slightly more complicated but only takes a few minutes of setup (and you can do it wirelessly going forward.) [See the guide on upgrading a hardware Alles speaker](https://github.com/shorepine/alles/tree/main/alles-flashing.md)

## Control Alles

You send the mesh (group of speakers) explicit messages that define the state of oscillators. You can control anything you can imagine, with high precision and millisecond accuracy. You can control up to 64 oscillators on each of any number of speakers in a mesh. You do this from either a programming language like Python (what we use) or an environment like Max/MSP (or Max for Ableton Live). Python is built-in on Macs and pretty easy to use once you get the hang of it. And then you can write small programs to make interesting sounds! For this tutorial, we'll use Python. But there's also a Max patch you can download that shows you how to access all the same parameters as we're changing in Python. So it's up to you!

So let's start python. Open your terminal, on a Mac, that's Terminal.app, on Windows I suggest using WSL, and on Linux whatever you've installed. [Clone this repository](https://github.com/shorepine/alles/) if you haven't already. (`git clone https://github.com/shorepine/alles.git`) Also make sure to update the submodules, so `cd alles; git submodule update --init --recursive`. Make sure you are in the directory containing the repository. And type `python3`. If on Mac, if you've never done this sort of thing before, you may have to accept a small download of tools from Apple the first time you run Python. Let that finish. Then you'll see a prompt like `>>>`. 

Start by importing the Python module needed to control the mesh: `import alles`

### Simple examples

`alles.drums()` should play a test pattern out of all the currently turned-on speakers. They should all be in sync and playing the same thing.

Try to set the volume of the speaker with `alles.volume(2)` -- that can be up to 10 or so.  The default is 1. You can also use the + and - buttons on the speaker, but anything you set with `alles.volume()` will override the buttons. 

When you want the speakers to be quiet, or if things are acting funny, use `alles.reset()`. That resets all speakers to defaults. Sometimes lots of experiments will get your oscillators in a weird state and `alles.reset()` is your escape hatch. You can also do `alles.reset(osc=5)` to do just one oscillator for example.

Let's set a simple sine wave first

```python
alles.send(osc=0, wave=alles.SINE, freq=220, amp=1)
```

What we're doing here should be pretty straightforward. I'm telling oscillator 0 to be a sine wave at 220Hz and amplitude 1. You can also try `alles.PULSE`, or `alles.SAW_DOWN`, etc. 

**Why can't you hear anything yet?** It's because you haven't triggered the note on for this oscillator. We accept a parameter called `vel` (velocity) that can turn a note on or off (`vel=0`.) So now that we've set up the oscillator, we just turn it on by `alles.send(osc=0, vel=1)`. Note the oscillator remembers all its state and setup. To turn off the note, just do `alles.send(osc=0, vel=0)`. 

You can also make oscillators louder with `amp` or `vel` over 1. 

Make sure to try `alles.reset()` to stop everything too.

You can also always use `note`, (MIDI note value) instead of `freq`.

```python
alles.send(osc=0, wave=alles.SINE, note=57, vel=1)
```

Now let's make a lot of sine waves! 

```python
import time
alles.reset()
for i in range(16):
    alles.send(osc=i, wave=alles.SINE, freq=110+(i*80), vel=((16-i)/32.0))
    time.sleep(0.5) # Sleep for 0.5 seconds
```

Neat! You can see how simple / powerful it is to have control over lots of oscillators. You have up to 64. Let's make it more interesting. A classic analog tone is the filtered saw wave. Let's make one.

```python
alles.send(osc=0,wave=alles.SAW_DOWN,filter_freq=2500, resonance=5, filter_type=alles.FILTER_LPF)
alles.send(osc=0, vel=1, note=40)
```

Sounds nice. But we want that filter freq to go down over time, to make that classic filter sweep tone. Let's use a breakpoint! A breakpoint is a simple list of (time, value) - you can have up to 8 of those pairs, and up to 3 different sets to control different things. They're just like ADSRs, but more powerful. You can control amplitude, frequency, duty cycle, feedback, filter frequence, or resonance with a breakpoint. It gets triggered when the note does. So let's make a breakpoint that turns the filter frequency down from its start at 2500 to 1250 after 100 milliseconds. And when the note goes off, taper the frequency to 0 after 25 millseconds. 

```python
alles.send(osc=0,wave=alles.SAW_DOWN,filter_freq=2500, resonance=5, filter_type=alles.FILTER_LPF)
alles.send(osc=0, bp0="100,0.5,25,0", bp0_target=alles.TARGET_FILTER_FREQ)
alles.send(osc=0, vel=1, note=40)
```

Great. You can add multiple targets together, for example, if you want a breakpoint to control both filter frequency and resonance, use `bp0_target=alles.TARGET_FILTER_FREQ+alles.TARGET_RESONANCE`. Give it a go!

We also have LFOs, which are implemented as one oscillator modulating another. You set the lower-frequency oscillator up, then have it control a parameter of another audible oscillator. Let's make the classic 8-bit duty cycle pulse wave modulation, a favorite: 

```python
alles.send(osc=1, wave=alles.SAW_DOWN, freq=0.5, amp=0.75)
alles.send(osc=0, wave=alles.PULSE, duty=0.5, freq=220, mod_source=1, mod_target=alles.TARGET_DUTY)
alles.send(osc=0, vel=0.5)
```

You see we first set up the modulation oscillator (a saw wave at 0.5Hz, with amplitude 0.75-- this indicates the "depth" of the LFO). Then we set up the oscillator to be modulated, a pulse wave with mod source of oscillator 1 and mod target of duty cycle. The initial duty cycle will start at 0.5 and be multiplied by the state of oscillator 1 every tick, to make that classic thick saw line from the C64 et al. The modulation will re-trigger every note on. Just like breakpoints, you can modulate duty cycle, amplitude, frequency, filter frequency, resonance or feedback! And if you want to modulate more than one thing, like frequency and duty, just add them together:

```python
alles.send(osc=1, wave=alles.TRIANGLE, freq=5, amp=0.25)
alles.send(osc=0, wave=alles.PULSE, duty=0.5, freq=110, mod_source=1, mod_target=alles.TARGET_DUTY+alles.TARGET_FREQ)
alles.send(osc=0, vel=0.5)
```

There's a lot more parameters and things to play with. Check out the [Alles README](https://github.com/shorepine/alles/blob/main/README.md) for the full list, or look at alles.message in Python:

```python
# alles.message():
(osc=0, wave=-1, patch=-1, note=-1, vel=-1, amp=-1, freq=-1, duty=-1, feedback=-1, timestamp=None, reset=-1, phase=-1, \
        client=-1, retries=1, volume=-1, filter_freq = -1, resonance = -1, bp0="", bp1="", bp2="", bp0_target=-1, bp1_target=-1, bp2_target=-1, mod_target=-1, \
        debug=-1, mod_source=-1, eq_l = -1, eq_m = -1, eq_h = -1, filter_type= -1, algorithm=-1, ratio = -1, algo_source=None)
```

`alles.py` has some helpful presets, if you want to use them, or add to them. To make that filter bass, just do `alles.preset(1, osc=0)` and then `alles.send(osc=0, vel=1, note=40)` to hear it. Here's another one:

```python
alles.preset(0, osc=2) # will set a simple sine wave tone on oscillator 2
alles.send(osc=2, note=50, vel=1.5) # will play the note at velocity 1.5
alles.send(osc=2, vel=0) # will send a "note off" -- you'll hear the note release
alles.send(osc=2, freq=220.5, vel=1.5) # same but specifying the frequency
alles.reset()
```

### Multiple speakers

Do you have multiple Alleses? I hope so, that's where all the real fun is. Whether they are physical hardware speakers or the Alles desktop program running on your computer, all the speakers on the same network are able to be controlled in one big mesh. They learn about how many they are, know how to stay in sync, and get a number we call `client` associated with them after a few seconds of being on. Generally the first speaker you turn on will have a `client` of 0, and the next 1, and so on. If you turn off a speaker, the rest will eventually fill in that gap and re-order themselves. 

When you are sending messages to Alles, if you don't specify `client`, all speakers receive the same message and play them at the exact same time. But it's more interesting to have different speakers play different types of sounds in sync. That example above, where we played 16 sine waves, is a good example. Let's adapt that to play a different sine wave on each speaker.

A quick way to know how many speakers are currently live in the mesh is to run `alles.sync()`. After a few seconds, you'll see a list spit out like

```json
{0: {'reliability': 1.0, 'avg_rtt': 124.0, 'ipv4': 1, 'battery': ('charged', 4)},
 2: {'reliability': 1.0, 'avg_rtt': 67.3, 'ipv4': 5, 'battery': ('charged', 4)},
 1: {'reliability': 1.0, 'avg_rtt': 293.5, 'ipv4': 3, 'battery': ('charged', 4)}}
```

This shows you the battery status and other timing details of each one. You can use `len(alles.sync())` to get a quick count for your compositions. Like so:

```python
import time
alles.reset()
speakers = len(alles.sync())
for i in range(16):
    alles.send(osc=i, wave=alles.SINE, freq=110+(i*80), vel=((16-i)/32.0), client=i % speakers)
    time.sleep(0.5) # Sleep for 0.5 seconds
```

I've added the `client` parameter to the message, and asked it to play each sine wave on client ID `i` (0-16) mod (remainder / `%`) `speakers`, which for me is 3. That just means sine wave 0 is played on speaker 0, sine wave 1 on speaker 1, wave 2 on 2, wave 3 on 0 again, wave 4 on 1, and so on in a round robin. Try it out!

There's some other helpful tricks in `client`. If you give `client` a number greater than 255, you can address groups of speakers. This is helfpul if you have a lot, and you want to send a message to half of the speakers, or every third speaker. 257 will be every 2nd speaker, 258 every third speaker, and so on. 

### Additive synthesis 

Those deep into synth lore already know why Alles is called that: we initially built it to be a multi-channel version of the "[Alles Machine](https://en.wikipedia.org/wiki/Bell_Labs_Digital_Synthesizer)", a Bell Labs synth from the 70s/80s invented by Hal Alles. It was built as a bank of oscillators and envelopes with filters, just like ours. Except we can program oscillators to go anywhere in space and have a lot more of them. 

Additive synthesis is simply adding together oscillators to make more complex tones. You can modulate the breakpoints of these oscillators over time, for example, changing their pitch or time without artifacts, as the synthesis is simply playing sine waves back at certain amplitudes and frequencies (and phases.) It's well suited to certain types of instruments. 

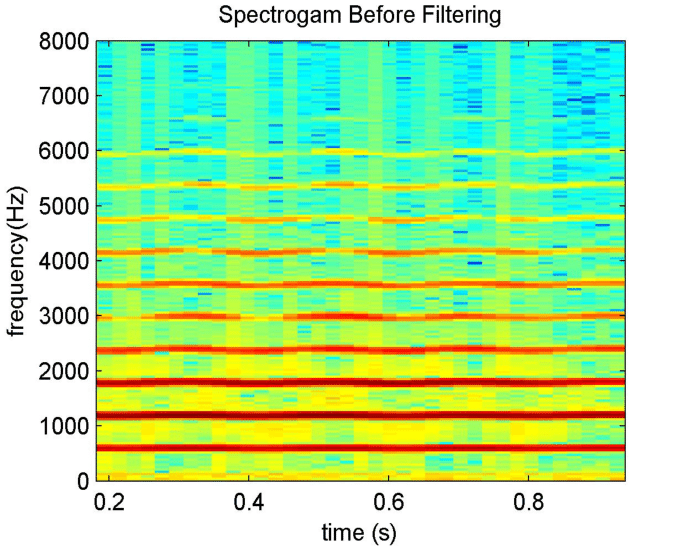
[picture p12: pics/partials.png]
Partials


We have analyzed the partials of a group of instruments and stored them as presets baked into the speaker. Each of these patches are comprised of multiple sine wave oscillators, changing over time. The `PARTIALS` type has the presets:

```python
alles.send(osc=0,vel=1,note=50,wave=alles.PARTIALS,patch=5) # a nice organ tone
alles.send(osc=0,vel=1,note=55,wave=alles.PARTIALS,patch=5) # change the frequency
alles.send(osc=0,vel=1,note=50,wave=alles.PARTIALS,patch=6,ratio=0.2) # ratio slows down the partial playback
```

There are 17 presets stored in each speaker, so `patch` can be between 0 and 16. 

Our partial breakpoint analyzer also emits "noise-excited bandwidth enhancement", which means it tries to emulate tones that are hard to generate with sine waves alone by modulating the amplitude of a sine wave with a filtered noise signal. You can try that out on the patches by adding `feedback`, like so:

```python
alles.send(osc=0,vel=1,note=50,wave=alles.PARTIALS,patch=6,feedback=0) # no bandwidth
alles.send(osc=0,vel=1,note=50,wave=alles.PARTIALS,patch=6,feedback=0.5) # more bandwidth
```

Below, in the advanced section, you'll learn how to analyze your own audio and play partials back from your host, to multiple speakers. Endless possibilities!

### Fun with frequency modulation

As well as doing partial additive synthesis, Alles is also great at doing frequency modulation of sine waves. We call it `ALGO`. This is a type of synthesis you've heard quite a bit of, and is fun to play with. You can experiment most easily by trying one of the 201 presets we've baked into Alles. Give it a go like

```python
alles.send(wave=alles.ALGO,osc=0,patch=0,note=50,vel=1)
alles.send(wave=alles.ALGO,osc=0,patch=1,note=50,vel=1)
```

The `patch` lets you set which preset. It can be from 0 to 200. Another fun parameter is `ratio`, which for ALGO patch types indicates how slow / fast to play the patch's envelopes. Really cool to slow them down!

```python
alles.send(wave=alles.ALGO,osc=0,note=40,vel=1,ratio=0.5,patch=8) # half speed
alles.send(wave=alles.ALGO,osc=0,note=40,vel=1,ratio=0.05,patch=8)  # reaaall sloooow
alles.send(wave=alles.ALGO,osc=0,note=30,vel=1,ratio=0.1,patch=19) # love this one
```

Let's make the classic FM bell tone ourselves, without a preset. We'll just be using two operators (two sine waves), one modulating the other. 

```python
alles.reset()
alles.send(wave=alles.SINE,ratio=0.2,amp=0.1,osc=0,bp0_target=alles.TARGET_AMP,bp0="1000,0,0,0")
alles.send(wave=alles.SINE,ratio=1,amp=1,osc=1)
alles.send(wave=alles.ALGO,algorithm=0,algo_source="-1,-1,-1,-1,1,0",osc=2)
```

Let's unpack that last line: we're setting up a ALGO "oscillator" that controls up to 6 other oscillators. We only need two, so we set the `algo_source` to mostly -1s (not used) and have oscillator 1 modulate oscillator 0. You can have the operators work with each other in all sorts of crazy ways. For this simple example, we just use the DX7 algorithm #1 (but we count from 0, so it's algorithm 0). And we'll use only operators 2 and 1. Therefore our `algo_source` lists the oscillators involved, counting backwards from 6. We're saying only have operators 2 and 1, and have oscillator 1 modulate oscillator 0. 

What's going on with `ratio`? And `amp`? Ratio, for FM synthesis operators, means the ratio of the frequency for that operator and the base note. So oscillator 0 will be played a 20% of the base note, and oscillator 1 will be the frequency of the base note. And for `amp`, that's something called "beta" in FM synthesis, which describes the strength of the modulation. Note we are having beta go down over 1,000 milliseconds using a breakpoint. That's key to the "bell ringing out" effect. 

Ok, we've set up the oscillators. Now, let's hear it!

```python
alles.send(osc=2, note=60, vel=3)
```

You should hear a bell-like tone. Nice. Another classic two operator tone is to instead modulate the higher tone with the lower one, to make a filter sweep. Let's do it over 5 seconds.

```python
alles.reset()
alles.send(osc=0,ratio=0.2,amp=0.5,bp0_target=alles.TARGET_AMP,bp0="0,0,5000,1,0,0")
alles.send(osc=1,ratio=1)
alles.send(osc=2,algorithm=0,wave=alles.ALGO,algo_source="-1,-1,-1,-1,0,1")
```

Just a refresher on breakpoints; here we are saying to set the beta parameter (amplitude of the modulating tone) to 0.5 but have it start at 0 at time 0, then be at 1.0x of 0.5 (so, 0.5) at time 5000ms. At the release of the note, set beta immediately to 0. We can play it with

```python
alles.send(osc=2,vel=2,note=50)
```

Nice. You can see there's limitless ways to make interesting evolving noises. 

### Karplus-Strong

Karplus-strong (KS) is a simple technique for synthesizing string instruments. You can play one at a time per speaker. You just need to remember to set the `feedback` parameter to something useful.

```python
alles.reset()
alles.send(osc=0,wave=alles.KS,note=60,vel=1,feedback=0.996)
```

### PCM Samples

Alles comes with a set of 67 drum-like and instrument PCM samples to use as well, as they are normally hard to render with additive or FM synthesis. You can use the type `PCM` and patch numbers 0-66 to explore them. Their native pitch is used if you don't give a frequency or note parameter, but you can change that.

```python
alles.send(osc=0, wave=alles.PCM, vel=1, patch=10) # cowbell
alles.send(osc=0, wave=alles.PCM, vel=1, patch=10, note=70) # higher cowbell! 
```

You can turn on sample looping, helpful for instruments, using `feedback`:

```python
alles.send(wave=alles.PCM,vel=1,patch=21,feedback=0) # clean guitar string, no looping
alles.send(wave=alles.PCM,vel=1,patch=21,feedback=1) # loops forever until note off
alles.send(vel=0) # note off
alles.send(wave=alles.PCM,vel=1,patch=35,feedback=1) # nice violin
```

### What's next

Make sure you read the main [Alles README](https://github.com/shorepine/alles/blob/main/README.md) for more details!!

## Advanced section

There's some real neat tricks Alles can do if you are adventurous. They require some computer setup, but it's not that complicated. We've tested this on recent Mac computers and Linux. Once you've completed the setup, you can build your own software Alles speaker and also generate your own partials from any audio and play them acros the mesh. Very fun!

### Setup

If you've never done this sort of thing before, I recommend first installing Homebrew on your computer. It's safe and quick to get some necessary dev tools set up. Check if you have it already by typing `brew` in the Terminal. If not, copy and paste this line:

```bash
/bin/bash -c "$(curl -fsSL https://raw.githubusercontent.com/Homebrew/install/HEAD/install.sh)"
```

After that, make sure you're in the root of the Alles repository (like `cd Downloads/alles-main/`) and install the things you need. (If you've done this stuff before, you need Python 3, swig and ffmpeg, and the Python modules pydub and numpy.)

```bash
brew install python3 swig ffmpeg
python3.9 -m pip install pydub numpy --user
tar xvf loris-1.8.tar
cd loris-1.8
CPPFLAGS=`python3-config --includes` PYTHON=`which python3.9` ./configure --with-python
make
sudo make install
cd ..
```

### Make your own partial playback synthesizer

As part of that setup you installed Loris, which is one of the better sine wave decomposition tools. (There's some others, if you get into this I recommend the great [`simpl`](https://github.com/johnglover/simpl) project to A/B test Loris against MQ or SMS.) Loris analyzes PCM audio into sets of partials (think of it as a sine wave over time in a spectrogram), each with a series of breakpoints, each specifying time, frequency, amplitude, bandwidth and phase. The PARTIALS presets you played with above are based on Loris analysis of instrument samples. But you can make your own analyses and control Alles using them. 

```python
import partials
(m,s) = partials.sequence("sleepwalk.mp3")
109 partials and 1029 breakpoints, max oscs used at once was 8

partials.play(s, amp_ratio=2, bw_ratio=0)
```

https://user-images.githubusercontent.com/76612/131150119-6fa69e3c-3244-476b-a209-1bd5760bc979.mp4

You can see, given any audio file, you can hear a sine wave decomposition version of it across Alles. This particular sound emitted 109 partials, with a total of 1029 breakpoints among them to play back to the mesh. Of those 109 partials, only 8 are active at once. `partials.sequence()` performs voice stealing to ensure we use as few oscillators as necessary to play back a set. 

There's a lot of parameters you can (and should!) play with in Loris. `partials.sequence`  and `partials.play`takes the following with their defaults:

```python
def sequence(filename, # any audio filename
                max_len_s = 10, # analyze first N seconds
                amp_floor=-30, # only accept partials at this amplitude in dB, lower #s == more partials
                hop_time=0.04, # time between analysis windows, impacts distance between breakpoints
                max_oscs=alles.OSCS, # max Alles oscs to take up, can be > 64 if using multiple speakers
                freq_res = 10, # freq resolution of analyzer, higher # -- less partials & breakpoints 
                freq_drift=20, # max difference in Hz within a single partial
                analysis_window = 100 # analysis window size 
                ) # returns (metadata, sequence)

def play(sequence, # from partials.sequence
                osc_offset=0, # start at this oscillator #
                sustain_ms = -1, # if the instrument should sustain, here's where (in ms)
                sustain_len_ms = 0, # how long to sustain for
                time_ratio = 1, # playback speed -- 0.5 , half speed
                pitch_ratio = 1, # frequency scale, 0.5 , half freq
                amp_ratio = 1, # amplitude scale,
                bw_ratio = 1, # bandwidth / noise scale
                round_robin=True # play back one partial per speaker in a round robin
                )
```

Hopefully you can experiment with this setup and make some great music. 

### Alles on your computer

The speakers are great for live performance and installing throughout a forest, but in your studio you may want something hooked into your setup to record or route to different effects. The way to do this is to boot up an Alles speaker (or many!) on your computer directly. If your computer is on the same network as your speakers, the programs will act just like all the other speakers in the mesh, and should stay in sync. 

All you have to do is compile the program called `alles` and run it locally. It's the same code as gets booted on the speaker, just running on your computer instead. If you've followed the setup instructions, just

```bash
cd main
make
./alles
Multicast IF is 192.168.1.85. Client tag (not ID) is 1. Listening on 232.10.11.12:9294
Using device ID 2, device Studio 1824c, channel -1  (all)
```

Now any message sent to the mesh will also play out your default audio output. 

Alles on the desktop has some optional startup parameters to help you run them on different networks and set the output to different sound cards. For example, I can have one Alles speaker running on each output of my 18-output USB audio interface! 

```bash
./alles -h
usage: alles
    [-i multicast interface ip address, default, autodetect]
    [-d sound device id, use -l to list, default, autodetect]
    [-c sound channel, default -1 for all channels on device]
    [-o offset for client ID, use for multiple copies of this program on the same host, default is 0]
    [-l list all sound devices and exit]
    [-h show this help and exit]
```

If you want to run multiple Alleses on one machine, you can set the IP address and "client offset" like so:

```bash
./alles -i 192.168.1.85 -o 100 -c 0
# in a new tab in Terminal.app
./alles -i 192.168.1.85 -o 101 -c 1
# ... and so on
```

You'll want to set client offset to a number that won't conflict with other devices on your network; here, my assumed client offset is 85 (the last # of the IP address), but I'm adding 100 to it for the first speaker, and 101 to it for the second, and so on. That ensures that another device on my network won't steal it. In practice you'll have a private network (use the -i parameter to set the source IP for it) so this is less of a concern, but something to keep in mind when composing at home.

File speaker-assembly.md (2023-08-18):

# Alles A60/A70 Speaker Assembly
The Alles PCB can be fitted into the enclosure of an off-the-shelf Bluetooth speaker - either the [round A60](https://www.alibaba.com/product-detail/A60-Wooden-Grain-Portable-Wireless-Bluetooth_1600291216741.html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) or the [square A70](https://www.alibaba.com/product-detail/A70-Wood-Speaker-Grain-Portable-Wireless_1600291333969.html). The Alles PCB replaces the original circuit board and keeps the speaker, battery, and buttons. Once installed, the USB port of the Alles PCB remains accessible and can be used to charge the battery. The speaker's buttons control the power, volume and WiFi mode (via the Play/Pause button). The result is a fully contained, battery-powered and rechargeable Alles speaker!  

## Suggested Tools

* A60/A70 Speaker (A60 used here)
* Alles PCB (Rev E used here)
* Soldering iron
* Flush cutters
* Fine flat-headed screwdriver, or a fine pointed tool that can fit in the speaker grill holes (0.8mm diameter screwdriver used here) 
* Small Phillips screwdriver (shaft no wider than 3.5mm diameter, and at least 22mm long)
* Wire strippers
* Helping hands
* Solder fume extractor

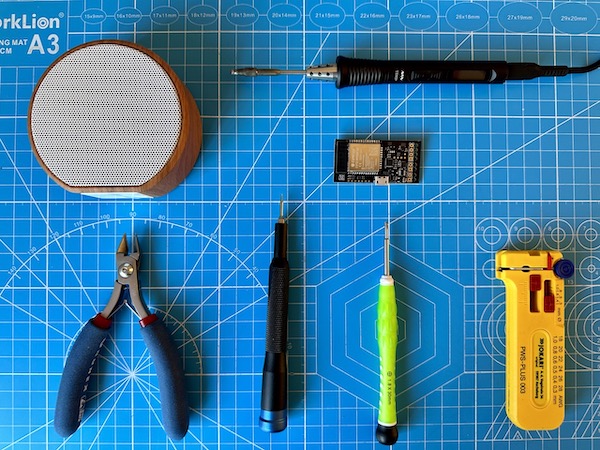
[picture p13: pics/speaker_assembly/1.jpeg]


## Remove speaker grill
The metal grill is held in place by friction only. Use the small pointed tool to gradually work the edges of the grill loose, away from the plastic enclosure. Work your way around the speaker lifting the perimeter gradually to avoid bending the mesh out of shape. Under the grille is a paper filter - set this aside too. 

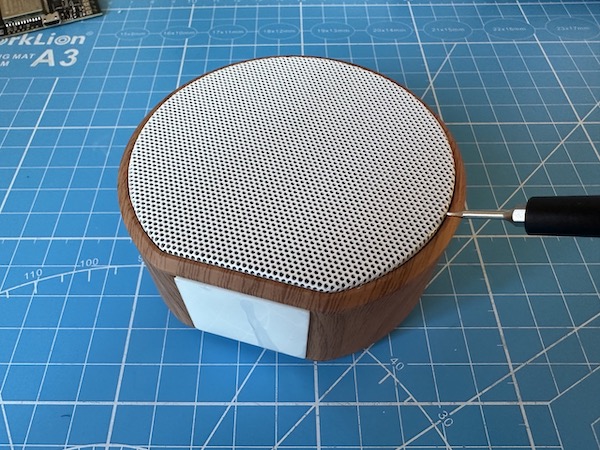
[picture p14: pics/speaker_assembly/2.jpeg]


## Unscrew enclosure
Use the small Phillips screwdriver to remove the 4 screws that hold the back and front of the enclosure together. The screws are set fairly deep inside narrow mounting holes, needing a thin (<3.5mm diameter) and long (>20mm) screwdriver. Screwdriver sets with interchangeable tips are unlikely to work.

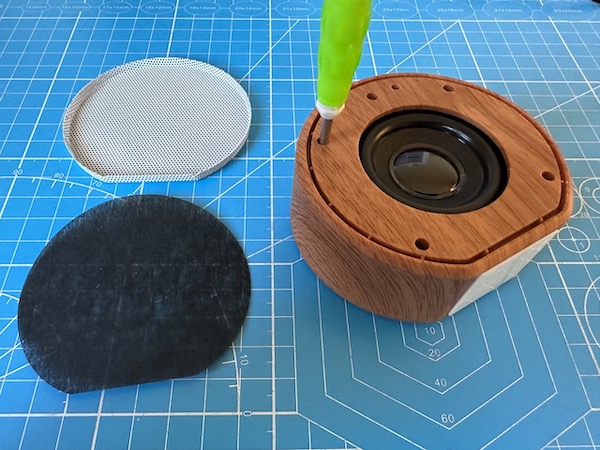
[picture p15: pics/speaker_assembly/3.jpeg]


## Remove circuit board

Lift out circuit board and cut it free of the speaker and battery cables. Cut the cables close to where they are soldered to the PCB.

#### CAUTION: LIPO BATTERIES ARE DANGEROUS

When cutting the battery cables, cut them one a time to avoid shorting them with the wire cutter. Always make sure that there is no chance that red and black terminals can short at any time as this could permanently damage the battery and could even result in the battery catching fire.  

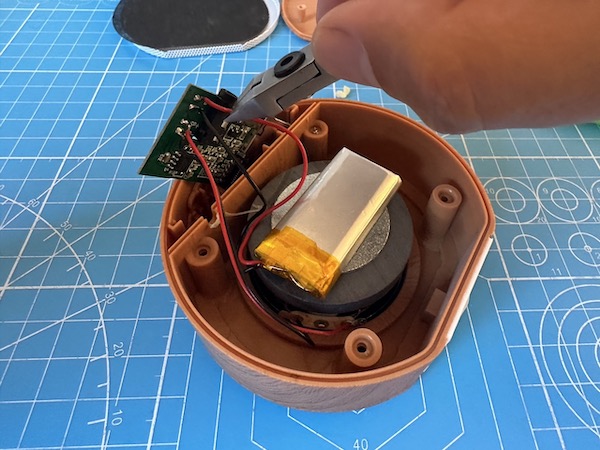
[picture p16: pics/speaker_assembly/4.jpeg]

 
## Cut plastic ribs 

Use the flush cutters to trim the two ribs that supported the original PCB, which would interfere with the location of the ESP32 module in the Alles PCB. 

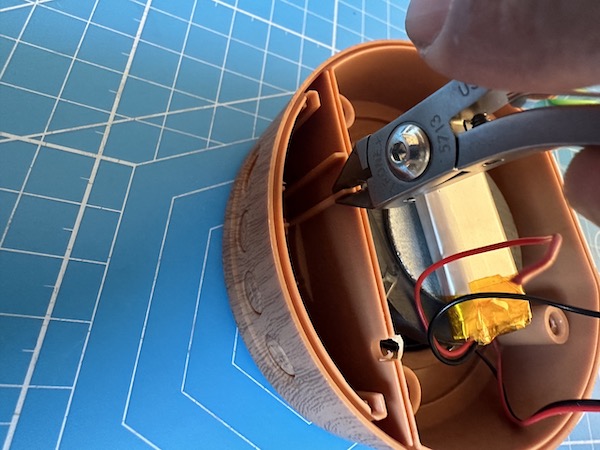
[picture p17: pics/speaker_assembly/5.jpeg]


## Trim and tin wires

Strip, trim and tin with solder the battery and speaker wires. Leave about 2mm of tinned conductor exposed. Again, use caution when working on the battery wires - do one at a time, and make sure the other is safely isolated during the process so that they never come into contact and short the battery terminals.

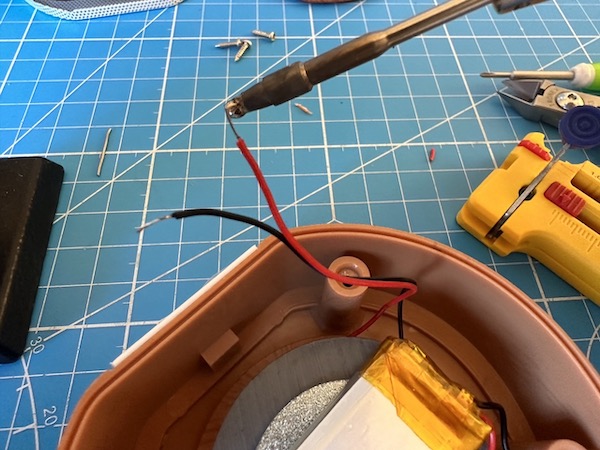
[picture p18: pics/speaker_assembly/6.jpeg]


## Solder wires onto Alles PCB

Solder all four wires from the component-side of the Alles PCB. Make sure that the wire insulator is flush against the PCB solder point so that wires can safefly twist without risk of shorting.

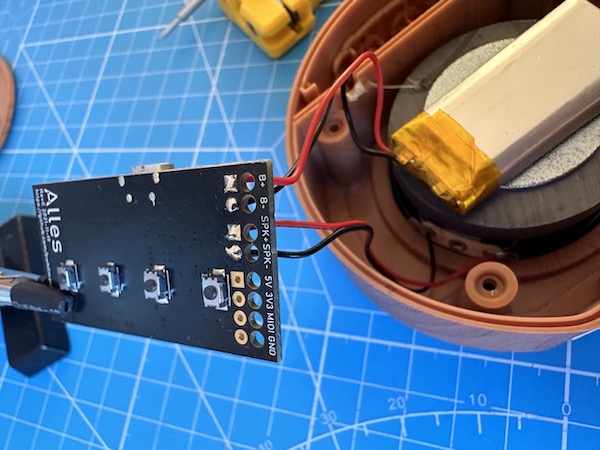
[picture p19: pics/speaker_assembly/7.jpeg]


## Fit the Alles PCB into the enclosure

The Alles PCB should slide between two rails that hold the circuit board in place. The ReV E PCB used here is 0.3mm thicker than the speaker's original circuit board so getting it into the rails can be a tight fit. 

First, make sure that the plastic buttons are correctly in place by pushing their plungers from inside the enclosure. When the PCB is in place these plungers will contact the tact switches on the circuit board.

Align the PCB edges with the channels and firmly and gradually press the PCB into the grooves. Try to press down both sides simultaneous and avoid putting pressure on the USB connector.

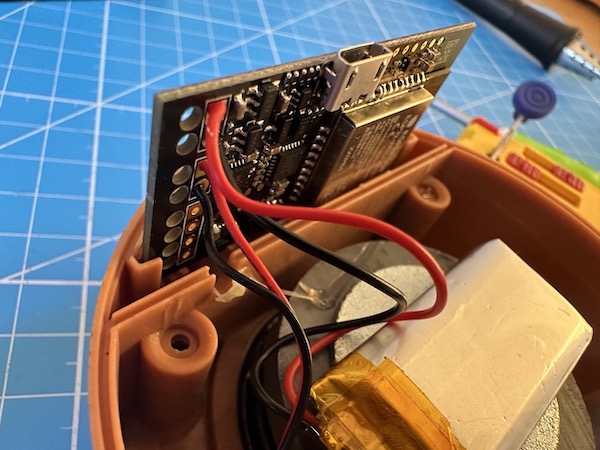
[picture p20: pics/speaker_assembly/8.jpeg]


The PCB is fully in place when it is flush with the edge of the enclosure and the cables sit inside the slot. 

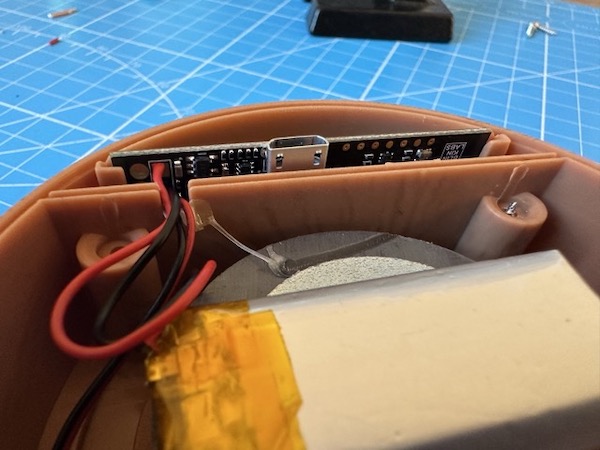
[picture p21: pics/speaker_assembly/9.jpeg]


## Test fit and aligment

Test the fit and aligment by putting the back cover in place. The edges should sit flush with the edge of the enclosure, and the USB connector should be aligned with the opening on the cover. 

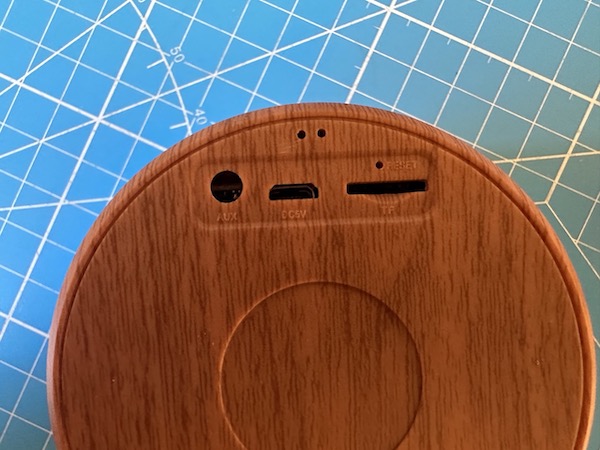
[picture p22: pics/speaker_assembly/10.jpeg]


## Reassemble the speaker

Screw the enclosure together, replace the paper filter, and press the metal grill back into place. 

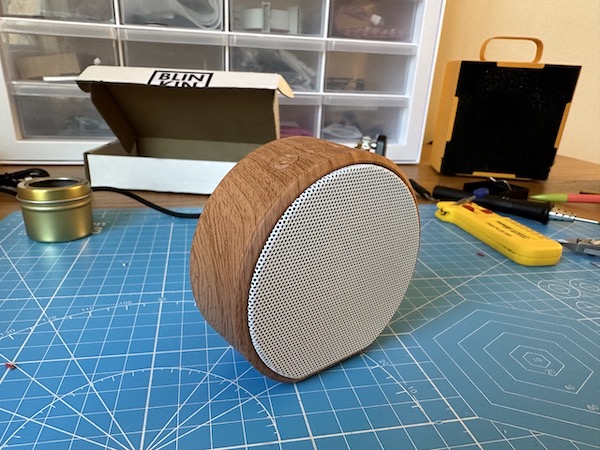
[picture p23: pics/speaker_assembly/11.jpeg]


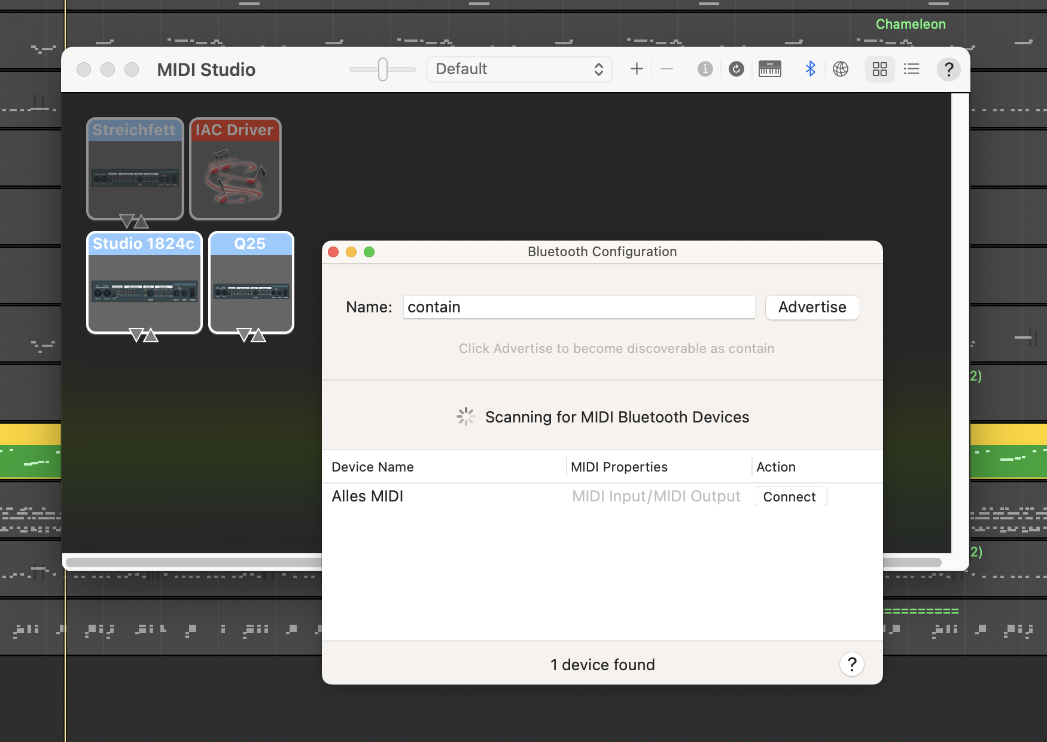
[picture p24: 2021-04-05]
pics/alles_midi_setup.png

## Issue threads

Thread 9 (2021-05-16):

Single synth wired setup

smutax, 2021-05-16:
Hi there. Great project! I wonder, would it not be possible for a single synth connected through wired midi to still produce sound? For testing purposes or just for a single synth setup. Or maybe even consider wired setup where few synths connected into a kind of cluster. Many thanks.

bwhitman, 2021-05-16:
A single synth 'immediate mode' over wired MIDI is certainly possible. If you don't need BTLE for MIDI, you can keep the oscillators on. and if you don't need the mesh, you could turn off wifi too and set latency to 0. Would require firmware changes and more work on the MIDI mode to expose more of the features.

As far as a wired cluster, that's a bit out of scope for us, but a lot of this code would be helpful to build something like that! You could also just use a multi-MIDI out hub and directly connect as many synths as you want.

smutax, 2021-05-16:
> A single synth 'immediate mode' over wired MIDI is certainly possible. If you don't need BTLE for MIDI, you can keep the oscillators on. and if you don't need the mesh, you could turn off wifi too and set latency to 0. Would require firmware changes and more work on the MIDI mode to expose more of the features.
>
Thank for the quick reply. I don't suppose you could consider the above a feature request? Another thing, there is an idea of generating new FM patches on-device so to speak. Would be interesting to hear what you think about such thing, https://github.com/Nintorac/NeuralDX7, see the mention of "live.py" in there. It basically takes 8 midi cc controls from your "midi controller to control the latent variables of the model and update the parameters of your FM Synthesizer in real time." All the very best

bwhitman, 2024-08-28:
Just in case you haven't seen https://github.com/shorepine/amy , this does that!

smutax, 2024-08-29:
> Just in case you haven't seen https://github.com/shorepine/amy , this does that!

Thanks Brian. I'll have a look. All the best.

Closed 2024-08-28.

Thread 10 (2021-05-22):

Clipping involves too many flops: Replace with lookup table

dpwe, 2021-05-22:
The "soft clipping" logic in alles.c includes a substantial number of floating-point ops per sample when the sample values are within 10% of the clip rail.

This could have nasty consequences if the clip logic causes the processing to underrun when it deploys.

A more efficient solution is to replace the x - (x^3)/3 calculation with a lookup table, and have the whole thing be done in the int16 domain.  We'd only need 1.5 * 0.1 * 32768 = ~5k 16 bit entries in the table, and the cost per sample would be one table lookup, rather than what looks like at least 5 floating-point ops.

something like:

#define INT16_MAX 32767
#define LIN_MAX 29491  // int(round(0.9 * 32768))
#define NONLIN_RANGE 4915  // size of nonlinearity lookup table = round(1.5 * (INT16_MAX - LINMAX))
#define NONLIN_MAX (LIN_MAX + NONLIN_RANGE)  // 34406, too big for signed int16

s = sgn(floatval);
uint16 uintval = (int)(s * floatval * INT16_MAX);  // s*floatval will be nonnegative; using a uint gives us factor-of-2 headroom
if (uintval > LIN_MAX) {
  if (uintval > NONLIN_MAX) {
    uintval = INT16_MAX;
  } else {
    uintval = clipping_lookup_table[uintval - LIN_MAX];
}
int16 final_sample = s * uintval;

and clipping_lookup_table is initialized to:

uint16 clipping_lookup_table[NONLIN_RANGE];  // largest value will be 32767, but call it uint because it's going into uintval
for (int x = 0; x < NONLIN_RANGE;++x) {
  float x_dash = ((float)x) / NONLIN_RANGE;
  clipping_lookup_table[x] = LIN_MAX + int(floor(NONLIN_RANGE * (x_dash - x_dash * x_dash * x_dash / 3.0)));
}

but of course you'd precalculate that into a const float[] header file.

Closed 2021-05-23.

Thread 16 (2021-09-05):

error when importing libamy

kasparsj, 2021-09-05:
Hi...
after running:
`sudo python3 setup.py  install`
and following the "Using amy.py's local mode" I'm getting this error:
```
>>> import amy, alles
Using 192.168.1.141 as local IP for multicast IF
>>> amy.live() # starts an audio callback thread to play audio in real time
Traceback (most recent call last):
  File "<stdin>", line 1, in <module>
  File "/home/kasparsj/Work/alles/amy.py", line 148, in live
    import libamy
ImportError: /usr/local/lib/python3.6/dist-packages/libamy.cpython-36m-x86_64-linux-gnu.so: undefined symbol: raw_file
```

bwhitman, 2021-09-05:
Ah, apologies. Alles/AMY is fast moving and we re-factored the "live" bit. Instead of rendering audio in Python interpreter, start a desktop alles instance instead, which will play the audio via multicast to Python. See `getting-started.md`. I'll fix up this documentation asap.

bwhitman, 2021-09-05:
Fixed up the READMEs and etc to reflect this new reality. Thanks for the report

kasparsj, 2021-09-06:
Thanks man :))

Closed 2021-09-05.

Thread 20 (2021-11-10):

eq no longer working

drepetto, 2021-11-10:
import alles
>>> alles.eq_test()
Traceback (most recent call last):
  File "<stdin>", line 1, in <module>
  File "/Users/douglas/Downloads/alles-main/alles.py", line 208, in eq_test
    eset()
NameError: name 'eset' is not defined

bwhitman, 2021-11-11:
fixed in 4dea5d3

drepetto, 2021-11-12:
Not sure what's happening, but now this runs, but just makes occasional clicking noises while printing:
>>> alles.reset()
>>> alles.eq_test()
eq_l = 0dB eq_m = 0dB eq_h = 0dB
eq_l = 15dB eq_m = 0dB eq_h = 0dB
eq_l = 0dB eq_m = 0dB eq_h = 15dB
eq_l = 0dB eq_m = 15dB eq_h = 0dB
eq_l = -15dB eq_m = -15dB eq_h = 15dB

bwhitman, 2021-11-12:
Yeah, we have a regression on eq . investigating...

bwhitman, 2021-11-12:
dang, dumb error. fixed in firmware, you'll have to update the speaker if you want it

Closed 2021-11-12.

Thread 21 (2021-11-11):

battery power not reporting properly

bwhitman, 2021-11-11:
discovered by @drepetto

swap `wall_voltage` with `battery_voltage` and test

bwhitman, 2021-12-04:
fixed this!

Closed 2021-12-04.

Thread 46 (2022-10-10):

powerdown bleep should schedule a reset first

bwhitman, 2022-10-10:
if you send a bass drum preset and then power down the power down debleep sounds funny (and great)

Closed 2024-11-02.

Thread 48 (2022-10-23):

Get working on 5.x ESP-IDF

bwhitman, 2022-10-23:
- [x] mdns is now a separate component
- [x] use new i2s component
- [x] multicast ip_info etc all different
- [x] esp32_wifi_manager needs an update
- [x] printf type
- [x] OTA failing

bwhitman, 2023-06-23:
- use new i2s component

bwhitman, 2023-06-23:
See PR #58

bwhitman, 2023-06-23:
```I (3894) main: I have a connection and my IP is 192.168.50.170!
E (5364) HTTP_CLIENT: Allocation failed
E (5364) esp_https_ota: Failed to initialise HTTP connection
Problem with upgrade -1 ESP_FAIL
```

bwhitman, 2023-06-26:
done!

Closed 2023-06-26.

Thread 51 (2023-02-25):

Boot loop

coreyker, 2023-02-25:
I just bought a couple esp32 dev boards off of amazon to try this out. I was able to build the software and flash the board. All seemed ok, but I don't see any new wifi networks. My board has 4mb of flash, so I overwrote `alles_partitions.csv` with `alles_4mb_partitions.csv`. The generated `alles.bin` file is 4mb.

I tried the serial monitor and it seems to be stuck in a boot loop. This is the output from the serial monitor (which seems to be complaining about the flash size):

ELF file SHA256: 61892cde1dad644f

Rebooting...
ets Jul 29 2019 12:21:46

rst:0xc (SW_CPU_RESET),boot:0x13 (SPI_FAST_FLASH_BOOT)
configsip: 0, SPIWP:0xee
clk_drv:0x00,q_drv:0x00,d_drv:0x00,cs0_drv:0x00,hd_drv:0x00,wp_drv:0x00
mode:DIO, clock div:2
load:0x3fff0030,len:6680
load:0x40078000,len:14944
load:0x40080400,len:3816
0x40080400: _init at ??:?

entry 0x40080698
I (27) boot: ESP-IDF v4.4.4-148-g4c2afac355 2nd stage bootloader
I (27) boot: compile time 11:53:35
I (27) boot: chip revision: v3.0
I (32) boot_comm: chip revision: 3, min. bootloader chip revision: 0
I (39) boot.esp32: SPI Speed      : 40MHz
I (43) boot.esp32: SPI Mode       : DIO
I (48) boot.esp32: SPI Flash Size : 8MB
I (52) boot: Enabling RNG early entropy source...
I (58) boot: Partition Table:
I (61) boot: ## Label            Usage          Type ST Offset   Length
I (69) boot:  0 nvs              WiFi data        01 02 00009000 00006000
I (76) boot:  1 phy_init         RF data          01 01 0000f000 00001000
I (84) boot:  2 factory          factory app      00 00 00010000 003ee000
I (91) boot: End of partition table
I (95) boot_comm: chip revision: 3, min. application chip revision: 0
I (102) esp_image: segment 0: paddr=00010020 vaddr=3f400020 size=316a5ch (3238492) map
I (1283) esp_image: segment 1: paddr=00326a84 vaddr=3ff80063 size=00008h (     8) load
I (1283) esp_image: segment 2: paddr=00326a94 vaddr=3ffb0000 size=03284h ( 12932) load
I (1294) esp_image: segment 3: paddr=00329d20 vaddr=40080000 size=062f8h ( 25336) load
I (1308) esp_image: segment 4: paddr=00330020 vaddr=400d0020 size=a1640h (661056) map
I (1547) esp_image: segment 5: paddr=003d1668 vaddr=400862f8 size=0f8a8h ( 63656) load
I (1574) esp_image: segment 6: paddr=003e0f18 vaddr=400c0000 size=00064h (   100) load
I (1584) boot: Loaded app from partition at offset 0x10000
I (1585) boot: Disabling RNG early entropy source...
I (1596) cpu_start: Pro cpu up.
I (1597) cpu_start: Starting app cpu, entry point is 0x4008134c
0x4008134c: call_start_cpu1 at /Users/corey/Development/esp/esp-idf/components/esp_system/port/cpu_start.c:148

I (1583) cpu_start: App cpu up.
I (1613) cpu_start: Pro cpu start user code
I (1613) cpu_start: cpu freq: 240000000
I (1613) cpu_start: Application information:
I (1618) cpu_start: Project name:     alles
I (1623) cpu_start: App version:      v0.2-alpha-18-g045edf3-dirty
I (1630) cpu_start: Compile time:     Feb 25 2023 11:53:33
I (1636) cpu_start: ELF file SHA256:  61892cde1dad644f...
I (1642) cpu_start: ESP-IDF:          v4.4.4-148-g4c2afac355
I (1649) heap_init: Initializing. RAM available for dynamic allocation:
I (1656) heap_init: At 3FFAE6E0 len 00001920 (6 KiB): DRAM
I (1662) heap_init: At 3FFBAA20 len 000255E0 (149 KiB): DRAM
I (1668) heap_init: At 3FFE0440 len 00003AE0 (14 KiB): D/IRAM
I (1675) heap_init: At 3FFE4350 len 0001BCB0 (111 KiB): D/IRAM
I (1681) heap_init: At 40095BA0 len 0000A460 (41 KiB): IRAM
I (1689) spi_flash: detected chip: winbond
I (1692) spi_flash: flash io: dio
E (1696) spi_flash: Detected size(4096k) smaller than the size in the binary image header(8192k). Probe failed.

assert failed: do_core_init startup.c:326 (flash_ret == ESP_OK)

Backtrace: 0x40081d22:0x3ffe3aa0 0x40089955:0x3ffe3ac0 0x4009064a:0x3ffe3ae0 0x400d322f:0x3ffe3c00 0x4008166d:0x3ffe3c40 0x40079494:0x3ffe3c80 |<-CORRUPTED
0x40081d22: panic_abort at /Users/corey/Development/esp/esp-idf/components/esp_system/panic.c:408

0x40089955: esp_system_abort at /Users/corey/Development/esp/esp-idf/components/esp_system/esp_system.c:137

0x4009064a: __assert_func at /Users/corey/Development/esp/esp-idf/components/newlib/assert.c:85

0x400d322f: do_core_init at /Users/corey/Development/esp/esp-idf/components/esp_system/startup.c:326
 (inlined by) start_cpu0_default at /Users/corey/Development/esp/esp-idf/components/esp_system/startup.c:433

0x4008166d: call_start_cpu0 at /Users/corey/Development/esp/esp-idf/components/esp_system/port/cpu_start.c:632

coreyker, 2023-02-25:
So, just to follow-up on this: I ran `idf.py menuconfig` and changed the default flash size from 8MB to 4MB, saved, built, and re-flashed. Seems to be working now (at least it boots and creates a wifi network).

bwhitman, 2023-02-25:
Ah that's great to hear! I will add the change to 4MB in menuconfig to the instructions.

Closed 2023-02-25.

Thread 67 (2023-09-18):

Later alles commits not loading RAM properly on revB+ boards

bwhitman, 2023-09-18:
Getting memory alloc errors for some reason. Need to investigate. The commit without AMY as a submodule works fine, so if you're seeing

```
Guru Meditation Error: Core  0 panic'ed (LoadStoreError). Exception was unhandled.

Core  0 register dump:
PC      : 0x400d958e  PS      : 0x00060e30  A0      : 0x800daed9  A1      : 0x3ffbce80
0x400d958e: oscs_init at /Users/bwhitman/outside/alles/amy/src/amy.c:406
```

Do this

```
gh repo clone bwhitman/alles
cd alles
git checkout e481edc
```

bwhitman, 2023-09-18:
fun, `MALLOC_CAP_INTERNAL` is not the same as `MALLOC_CAP_DEFAULT`. All fixed

Closed 2023-09-18.

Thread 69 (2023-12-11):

Volume difference on FXP Alles

bwhitman, 2023-12-11:
The new fixed point AMY doesn't seem to be as loud on the Alles esp32 speakers as it used to. And setting volume to usually ok amounts (3-5) now clips during alles.drums()

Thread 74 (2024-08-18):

Help, please!

phesterman, 2024-08-18:
I've made my own DIY Alles (with ESP-32 wired to the I2S amp according to the instructions given here), got the esp-idf installed, successfully built and uploaded the alles software to the ESP-32, the speaker chimes (bloops an octave), and the ESP-32 is connecting to my home network (at least when I 'import alles' in Python it shows that it's connected).  But that's it...the speaker keeps blooping, 'alles.drums()' doesn't do anything, and 'alles.sync()' gives an error ("'millis' is not defined").  I've started over, substituting for the various components, but end up in the same place.  I'd appreciate any help or troubleshooting advice.

Thanks,

Peter

bwhitman, 2024-08-18:
The speaker keeping blooping means it must be resetting itself often. Can you connect to the serial terminal and show us the output ?  `alles.sync()` not working is a bug on our end, we can fix it!

phesterman, 2024-08-19:
Thanks for your quick reply!

I'm afraid I don't really know what I'm doing with the ESP-32 serial terminal.  It's generating way more output than I can manage.  Is there a way to redirect the output to a text file (I'm using Terminal in macOS)?  Otherwise, I've managed to take a few screenshots, if that would be of any help.

bwhitman, 2024-08-19:
Screenshots are fine! Or if you can copy all the text and paste it in here that’s fine too.

phesterman, 2024-08-19:
OK, I hope you can make sense of these....there's some overlap.
[Screenshots.pdf](https://github.com/user-attachments/files/16654495/Screenshots.pdf)

bwhitman, 2024-08-19:
That helps a lot! Are you pushing the PWR button a lot? Your logs show something is rebooting the Alles many times by the PWR button being toggled. On the Alles boards you can buy that's a GPIO - 34 -- that sets that. If you don't have that pin wired up maybe something else is constantly toggling that pin?  You may want to comment out all the button handling code if your Alles doesn't have those. That would mean commenting out lines 34 through 64 in `buttons.c`.

bwhitman, 2024-08-19:
I see the reboots but unfortunately there's not a clear indication of why it's not working for you. I'll take a look asap on my esp32 dev board to ensure it still works there. Can you let me know which dev board you are using ?

phesterman, 2024-08-19:
I'm using the one you linked to in the instructions.
<https://www.amazon.com/dp/B07Q576VWZ?ref=ppx_yo2ov_dt_b_fed_asin_title&th=1>
I also followed the instructions you gave because it's a 4mB rather than an 8mB version of the ESP32 dev board.

phesterman, 2024-08-19:
I also wanted to ask you about one of the I2S connections.  In the written instructions I2S gain is connected to ESP32 VIN (this is how I currently have it wired), but I noticed in one of your close-up photos, I2S gain was connected to GND instead.  I looked at another ESP32->I2S project I did in the past, and it was also gain->GND.  So, I thought I should double-check that.

bwhitman, 2024-08-19:
If you're using the recommended MAX98357A board, the GAIN pin can be connected to either VIN or GND, it's an overall volume control. It'll be up to you what sounds better for you and your speaker. It may sound distorted for higher volumes. See more here: https://learn.adafruit.com/adafruit-max98357-i2s-class-d-mono-amp/pinouts#gain-2693327

bwhitman, 2024-08-19:
I found my old MELIFE esp32 board (the one we recommend) and wired it up to the I2S adapter like we describe, and did the `idf.py menuconfig` to set the firmware size to 4MB and copied over the `alles_4mb_partitions.csv` and did `idf.py flash` from the latest `main` branch here, and everything works great for me. No reboots.

I think there's either an issue with your dev board, or the wiring you have to your i2s board. Please double check that, maybe with a multimeter, and maybe try another dev board? I've heard stories of these cheaper devboards not being soldered properly and this may be causing your issue.

For reference, here is the boot log from my MELIFE board and current `main` alles code:

```
(base) bwhitman@curious alles % idf.py monitor
Executing action: monitor
Serial port /dev/cu.usbserial-0001
Connecting....
Detecting chip type... Unsupported detection protocol, switching and trying again...
Connecting....
Detecting chip type... ESP32
Running idf_monitor in directory /Users/bwhitman/outside/alles
Executing "/Users/bwhitman/.espressif/python_env/idf5.2_py3.11_env/bin/python /Users/bwhitman/esp/esp-idf-v5.2/tools/idf_monitor.py -p /dev/cu.usbserial-0001 -b 115200 --toolchain-prefix xtensa-esp32-elf- --target esp32 --revision 0 /Users/bwhitman/outside/alles/build/alles.elf -m '/Users/bwhitman/.espressif/python_env/idf5.2_py3.11_env/bin/python' '/Users/bwhitman/esp/esp-idf-v5.2/tools/idf.py'"...
--- esp-idf-monitor 1.4.0 on /dev/cu.usbserial-0001 115200 ---
--- Quit: Ctrl+] | Menu: Ctrl+T | Help: Ctrl+T followed by Ctrl+H ---
ets Jun  8 2016 00:22:57

rst:0x1 (POWERON_RESET),boot:0x13 (SPI_FAST_FLASH_BOOT)
configsip: 0, SPIWP:0xee
clk_drv:0x00,q_drv:0x00,d_drv:0x00,cs0_drv:0x00,hd_drv:0x00,wp_drv:0x00
mode:DIO, clock div:3
load:0x3fff0030,len:7172
load:0x40078000,len:15532
load:0x40080400,len:4
0x40080400: _init at ??:?
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
bwhitman, 2024-08-20:
Nice! That does look a lot better. I'm still very nervous why the `buttons.c` stuff crashes for you.

UDP broadcast not working could be related, or its own thing. Try going through your router's settings to ensure UDP multicast is not disabled somewhere. Try also using `netcat` to write an AMY message directly to the IP address your Alles has booted with: `nc -u 192.168.1.215 9294` and typing `v0f440l1Z` and enter

phesterman, 2024-08-20:
I went all through my AT&T router's settings and AT&T's broadband faq/help site and couldn't find any reference to UDP or multicast, so who knows?  However, using netcat as you indicated above I was able to get a tone!  BTW I'm happy to try adding buttons if that could help and you'll give me some guidance.  Also, I have a Tulip, if that would be of any help in debugging.  And, finally, thanks for spending so much time on this!

phesterman, 2024-08-20:
I wanted to try the AMY example code at the link you gave.  Is the Melife ESP32 a p4, or do I have to specify it in some other way?  I just used esp32 without the p4 and the build failed.

On Aug 19, 2024, at 8:51 PM, Brian Whitman ***@***.***> wrote:

I'm seeing the backtrace in buttons.c. I have no idea why, but given that you're not using any buttons, try commenting out the line that starts the buttons management? In alles_esp32.c comment out line 420: check_init(&buttons_init, "buttons");?

Other than that I am out of ideas. It's a weird error and I can't replicate it here. Maybe try re-installing ESP-IDF, and test that simpler programs work fine on your board. Also try the AMY example code (without the WiFi) https://github.com/shorepine/amy_dual_core_esp32

—
Reply to this email directly, view it on GitHub<https://github.com/shorepine/alles/issues/74#issuecomment-2297812135>, or unsubscribe<https://github.com/notifications/unsubscribe-auth/ABQ7QLHI2C5FFXCP33KM2XLZSKOJXAVCNFSM6AAAAABMWWDA7SVHI2DSMVQWIX3LMV43OSLTON2WKQ3PNVWWK3TUHMZDEOJXHAYTEMJTGU>.
You are receiving this because you authored the thread.Message ID: ***@***.***>

phesterman, 2024-08-22:
So, does the fact that the netcat test worked suggest a solution?  I've read that multicast is related to Bonjour, and Bonjour works on my wireless network.

phesterman, 2024-08-28:
OK, I set up a wireless network on an old Apple Airport Express, and finally got things working!  Thanks again for the help.

alles.sync() still doesn't work, by the way.

bwhitman, 2024-08-28:
That's great. I'll make an issue about alles.sync().

Closed 2024-08-28.

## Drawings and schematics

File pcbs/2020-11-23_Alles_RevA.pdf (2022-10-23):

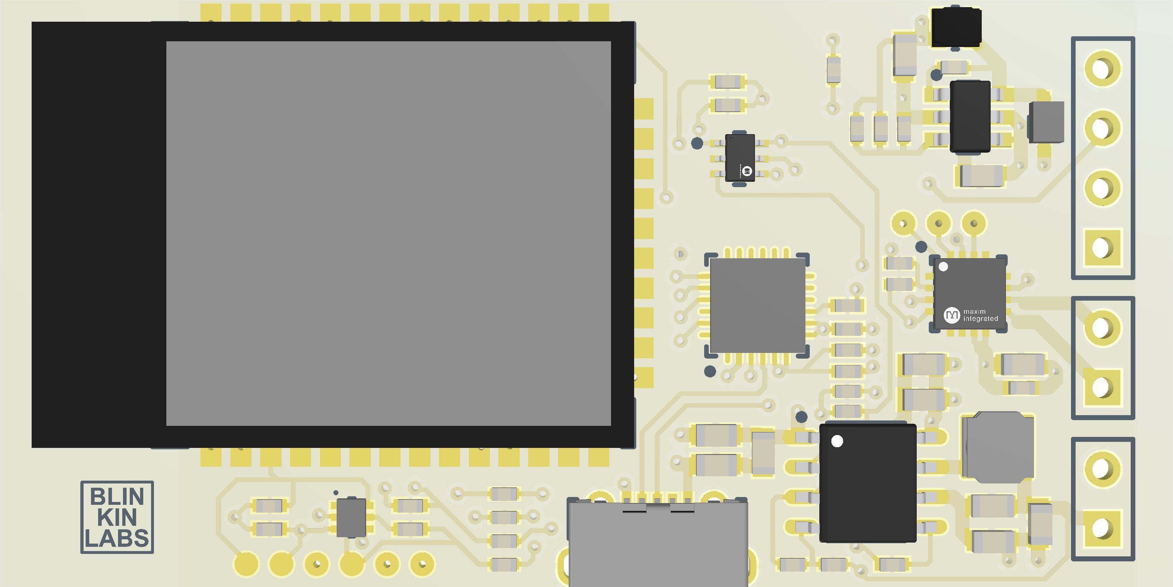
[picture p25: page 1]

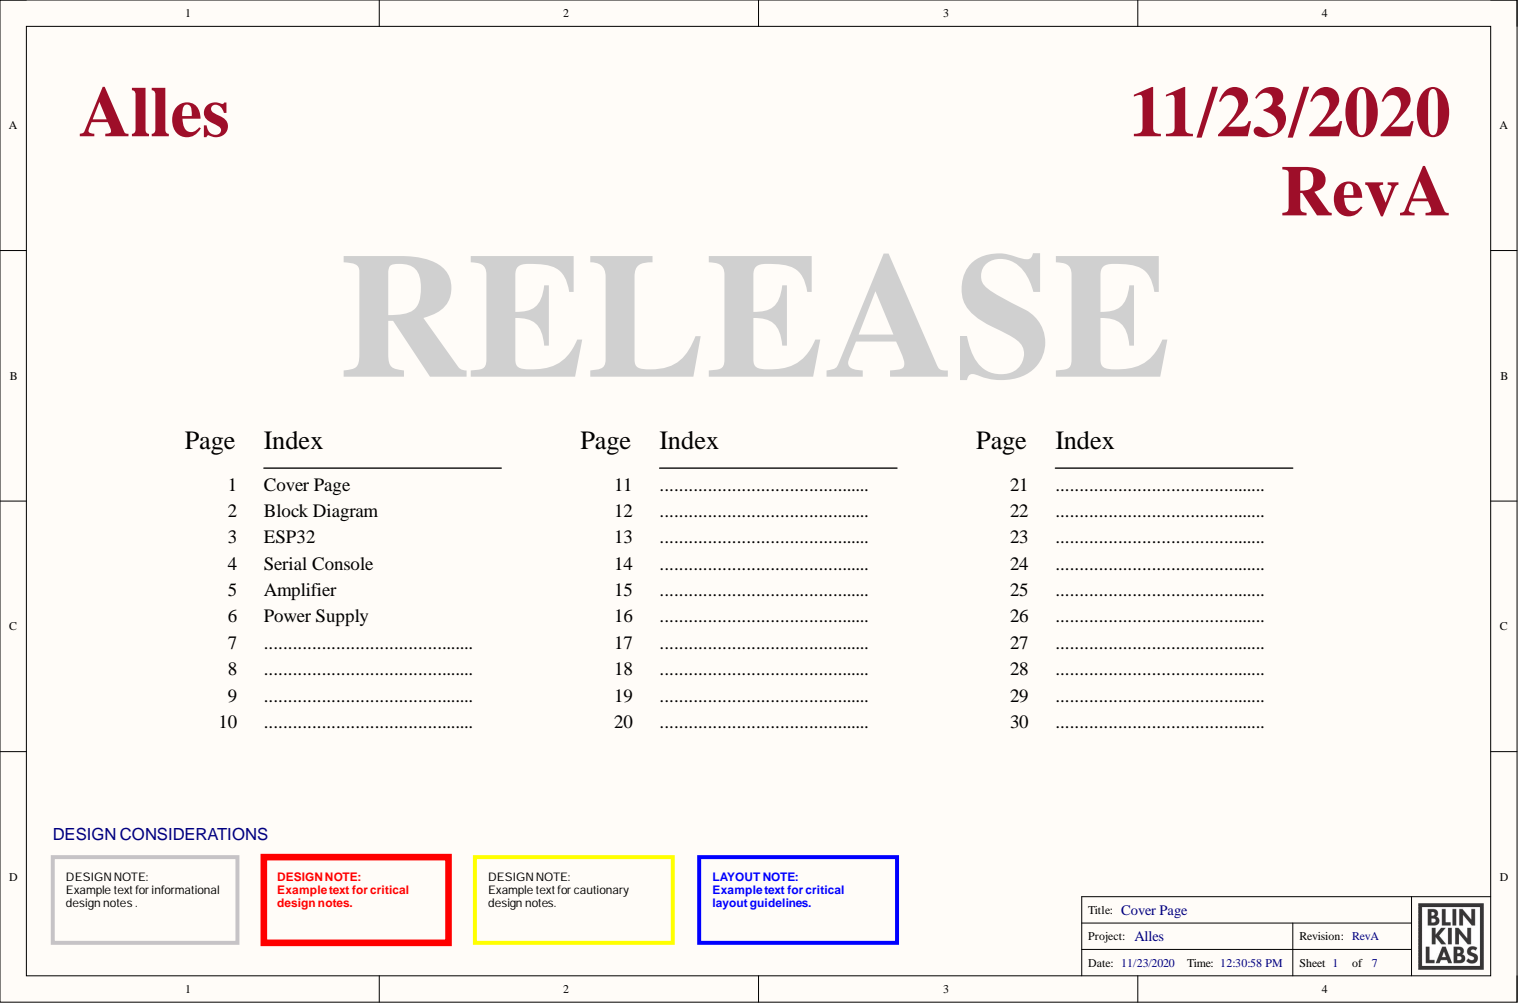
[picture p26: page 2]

DESIGN NOTE:
Example text for informational
design notes .

Example text for critical
design notes.

Example text for cautionary

LAYOUT NOTE:
layout guidelines.

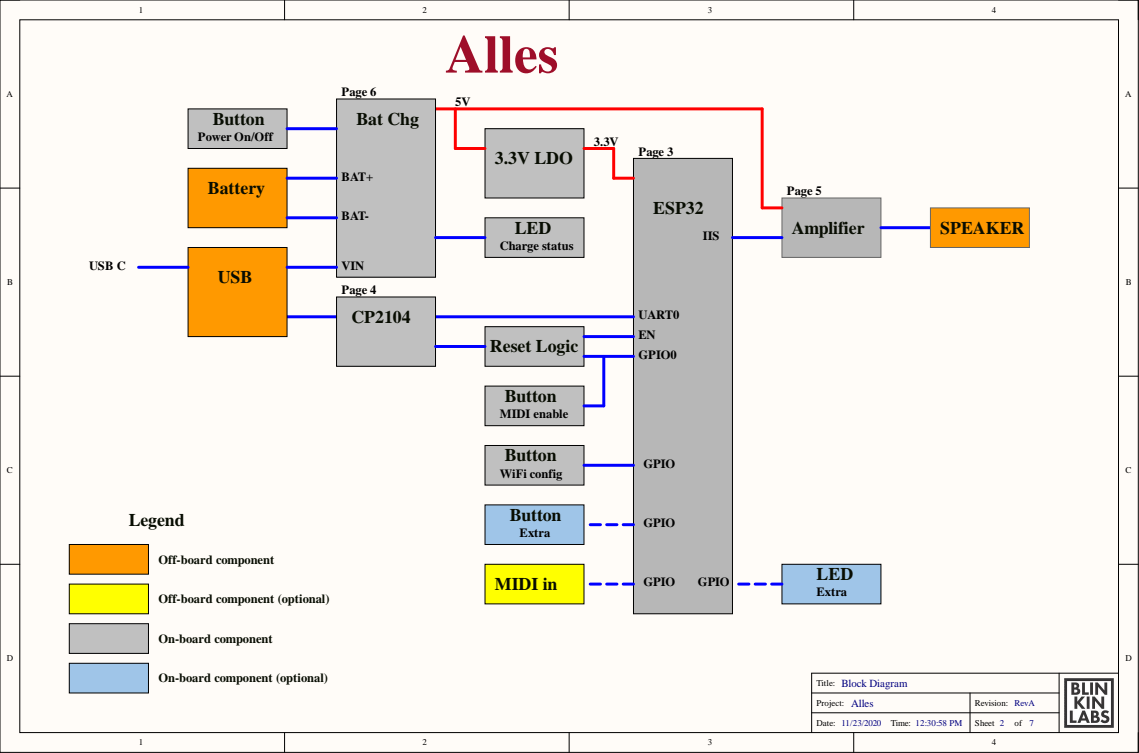
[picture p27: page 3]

Off-board component (optional)

On-board component (optional)

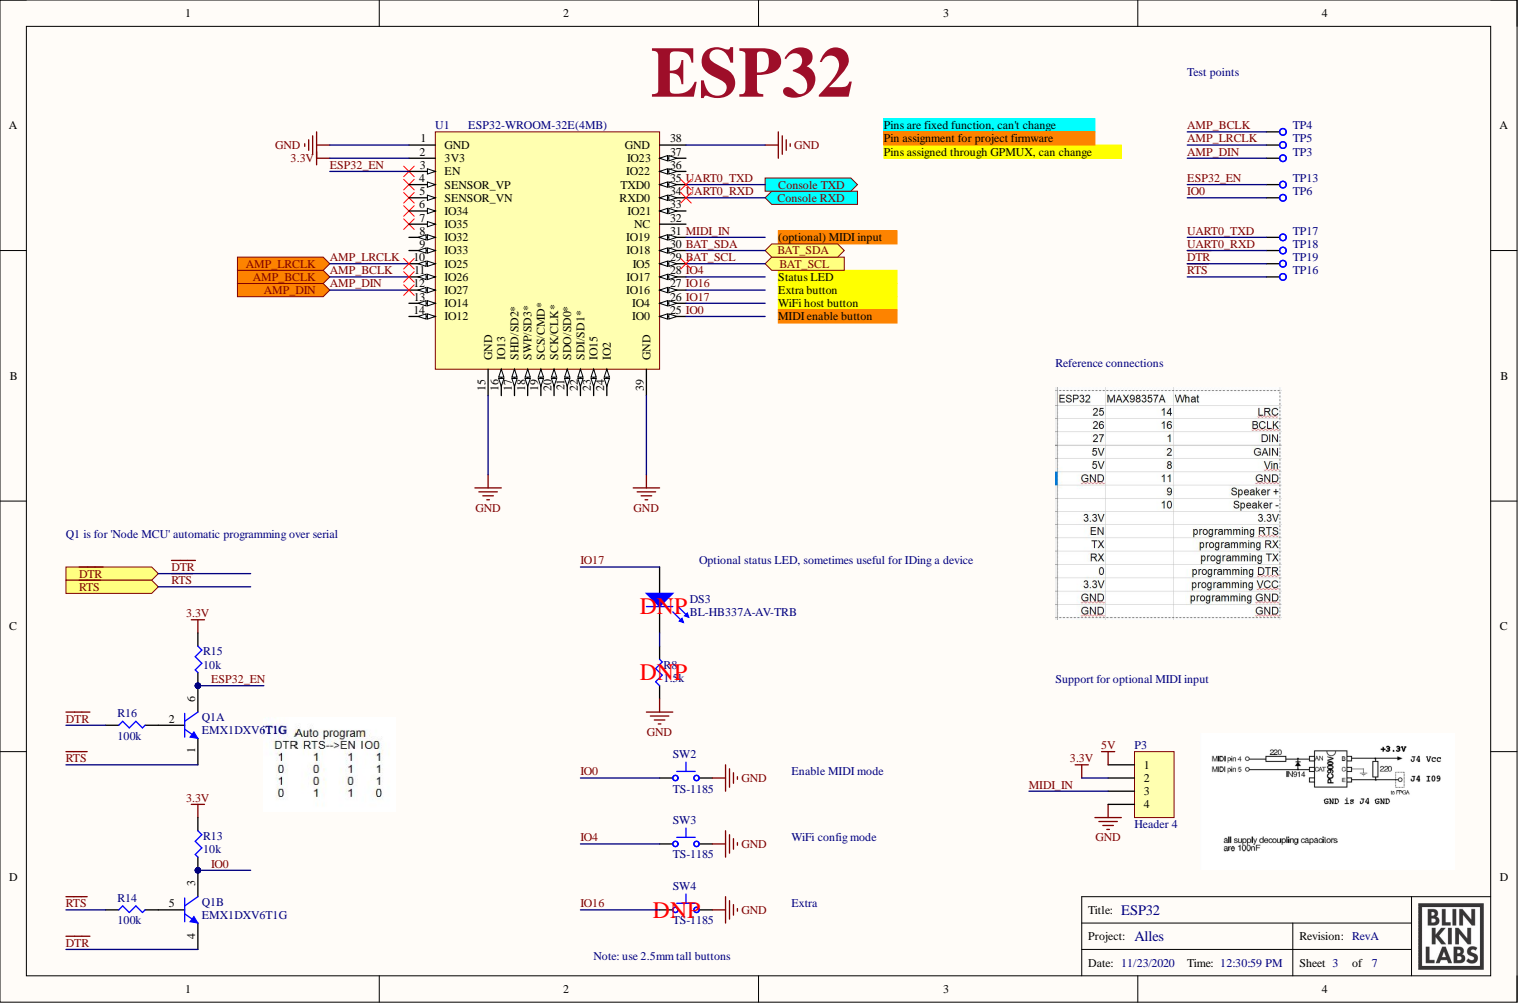
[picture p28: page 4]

Pins are fixed function, can't change
Pin assignment for project firmware
Pins assigned through GPMUX, can change

Q1 is for 'Node MCU' automatic programming over serial

Optional status LED, sometimes useful for IDing a device

DS3 DNP BL-HB337A-AV-TRB

Support for optional MIDI input

Note: use 2.5mm tall buttons

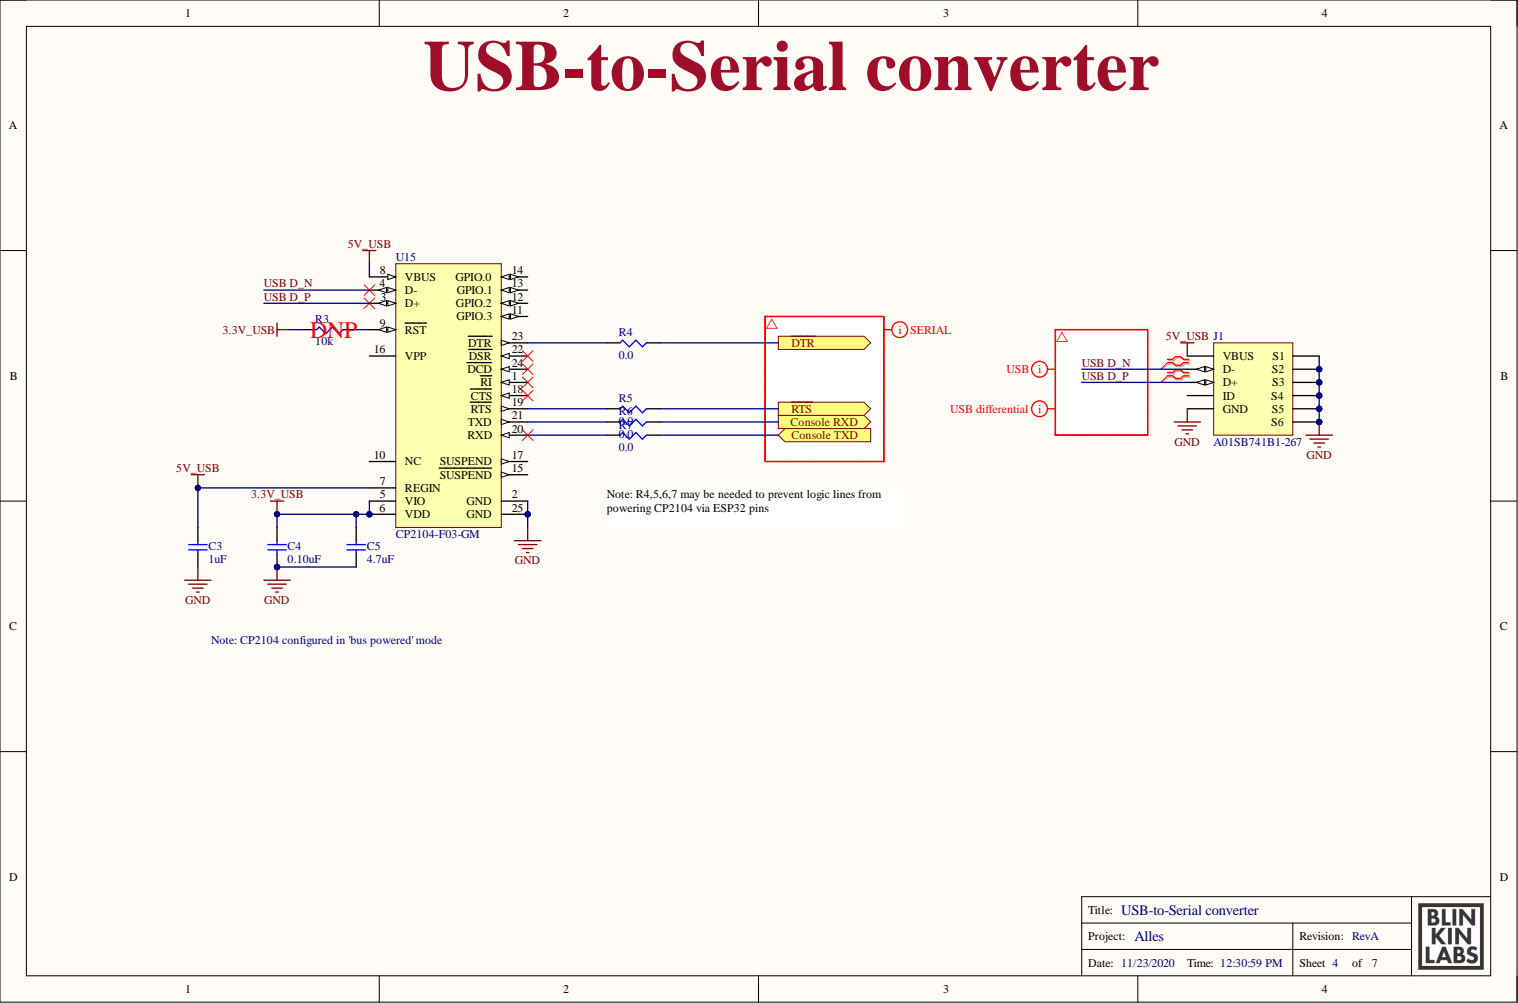
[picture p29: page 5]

USB-to-Serial converter

te: R4,5,6,7 may be needed t
weri

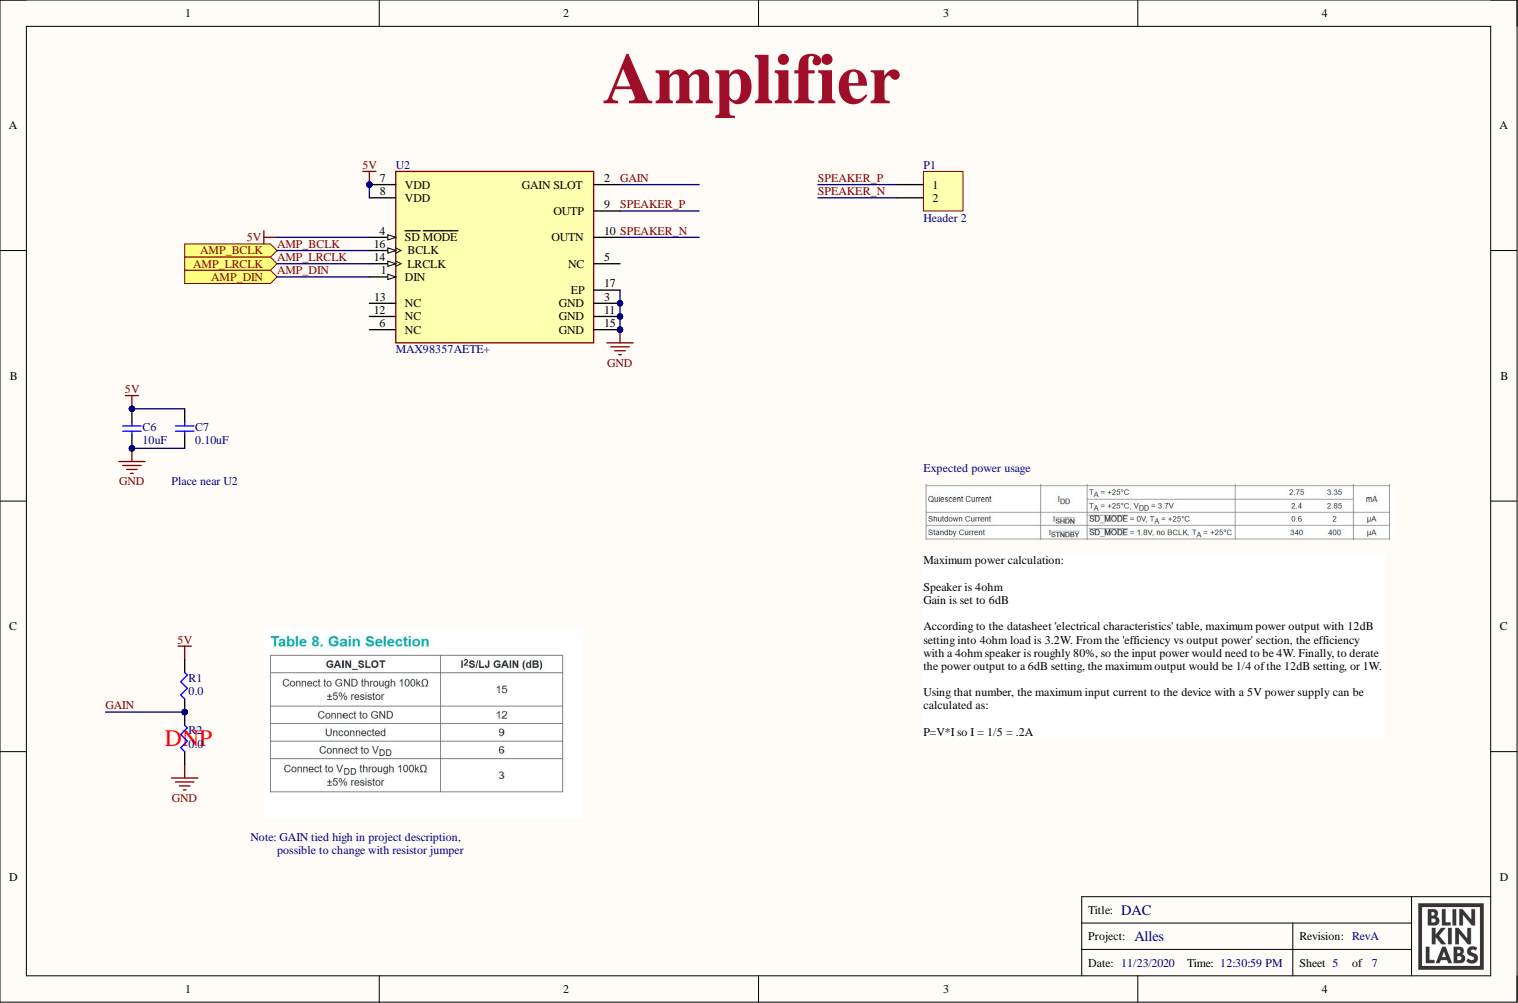
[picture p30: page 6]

Speaker is 4ohm
Gain is set to 6dB

According to the datasheet 'electrical characteristics' table, maximum power output with 12dB
setting into 4ohm load is 3.2W. From the 'efficiency vs output power' section, the efficiency
with a 4ohm speaker is roughly 80%, so the input power would need to be 4W. Finally, to derate
the power output to a 6dB setting, the maximum output would be 1/4 of the 12dB setting, or 1W.

Using that number, the maximum input current to the device with a 5V power supply can be
calculated as:

Note: GAIN tied high in project description,
possible to change with resistor jumper

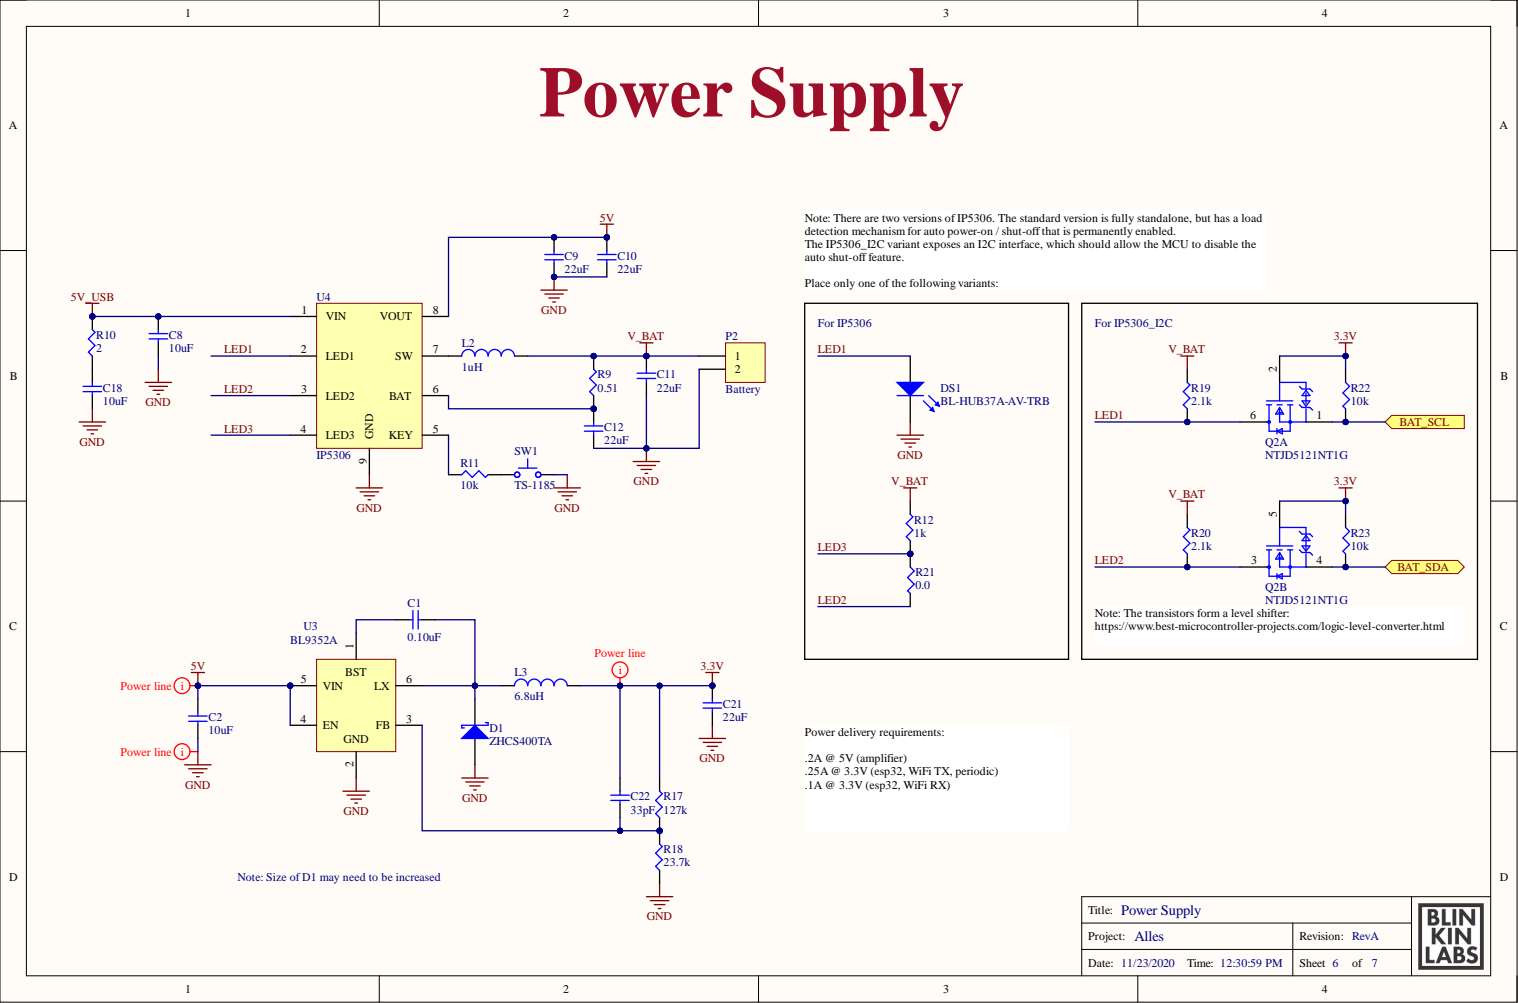
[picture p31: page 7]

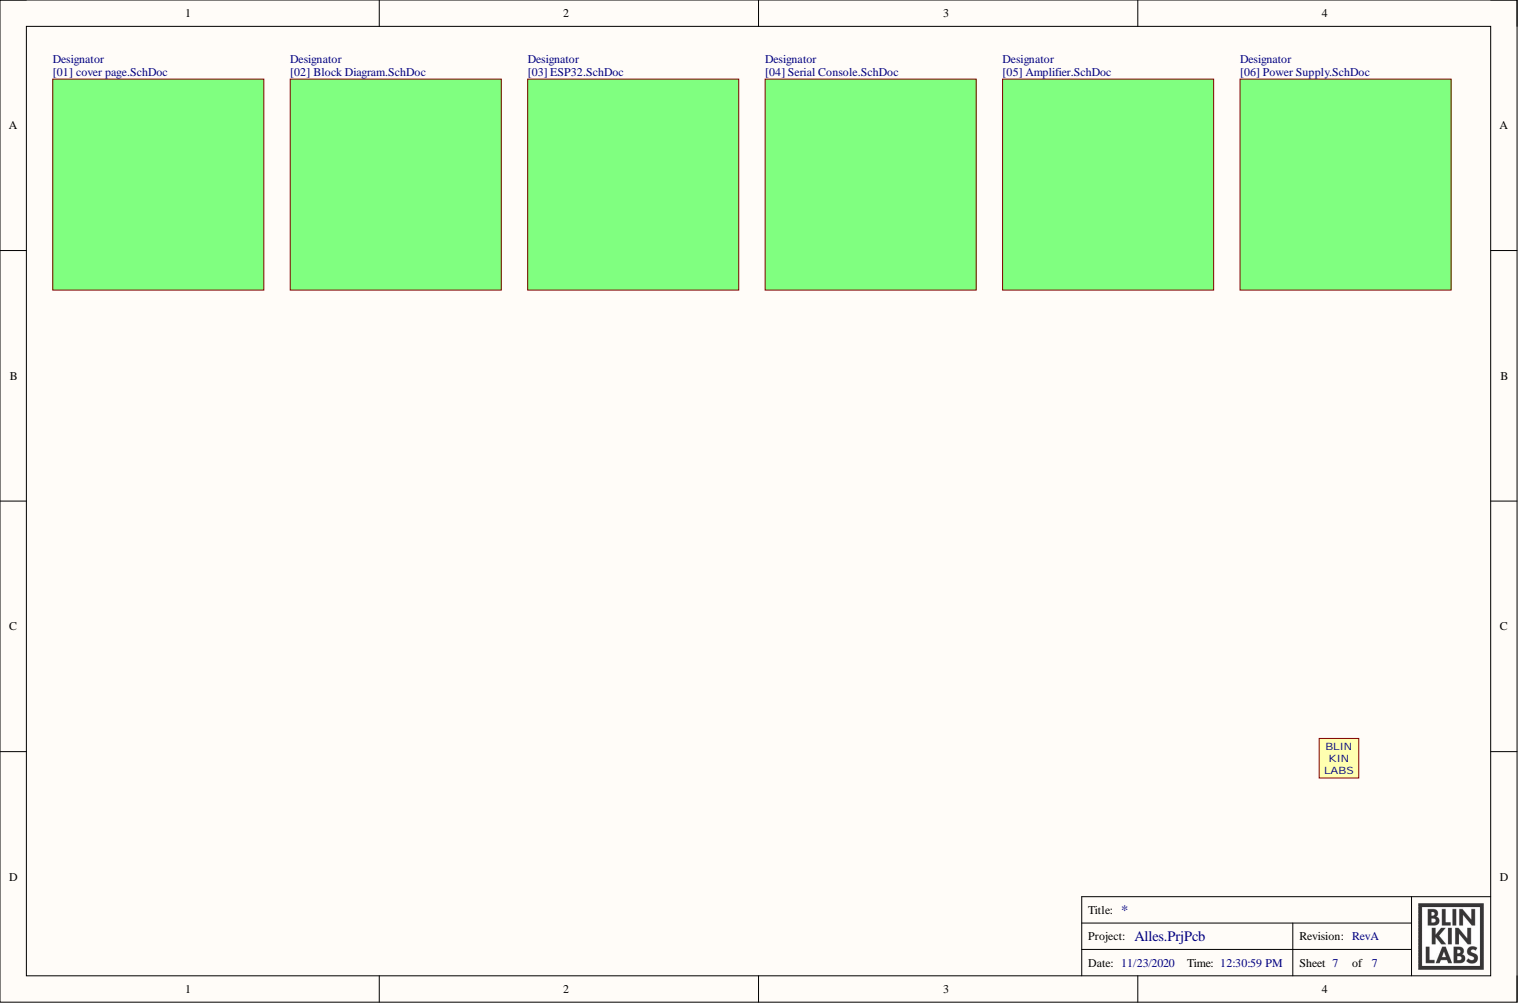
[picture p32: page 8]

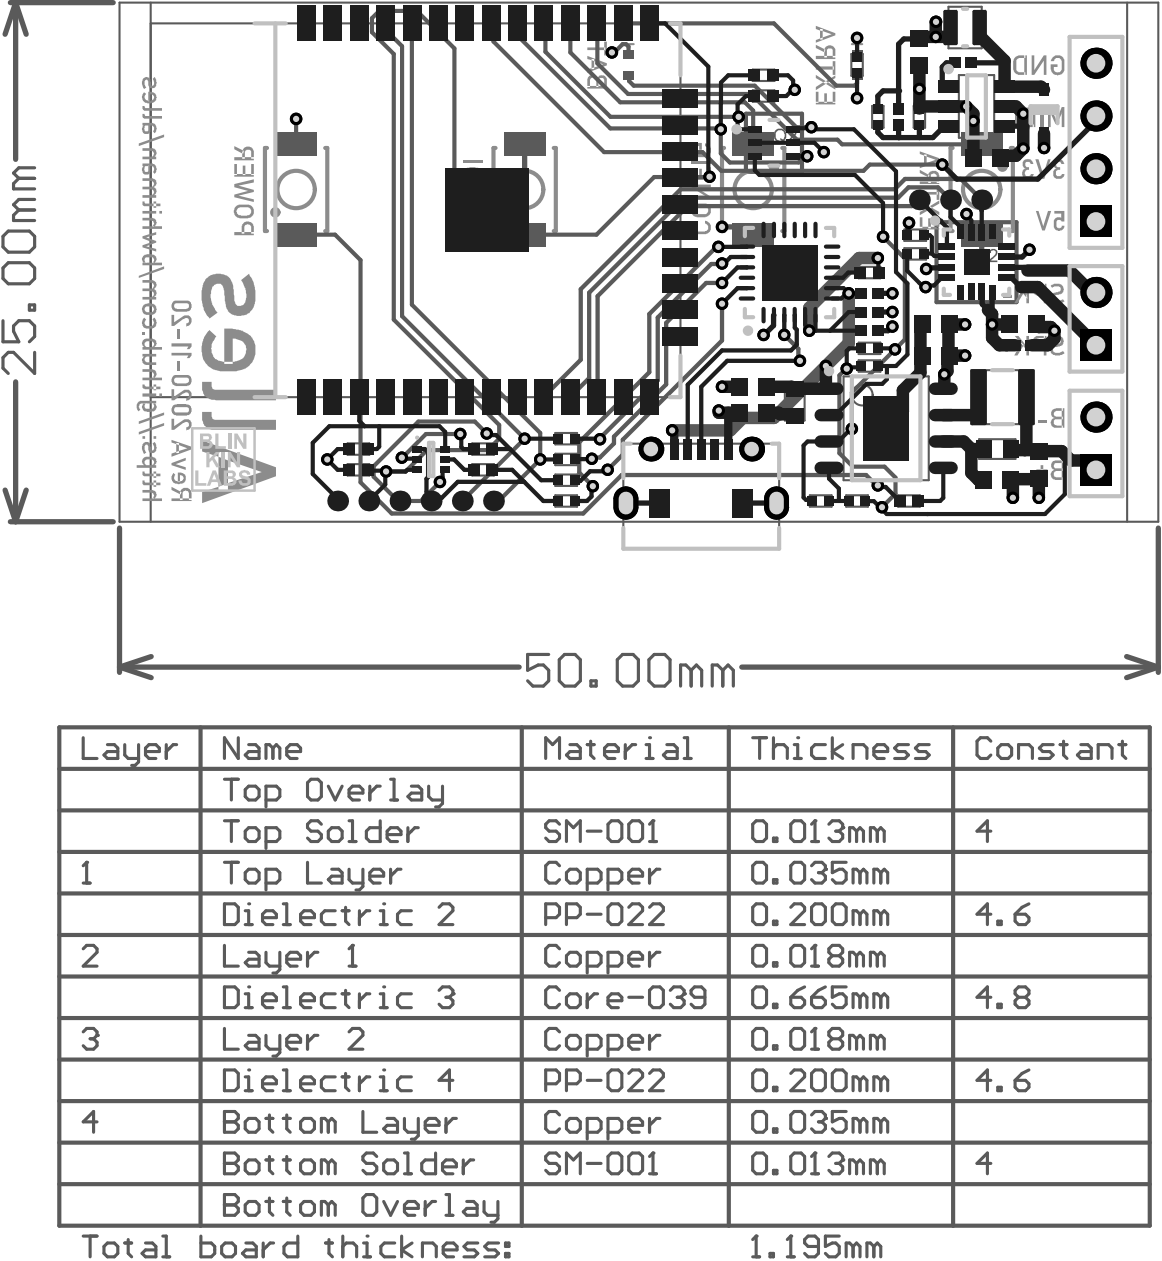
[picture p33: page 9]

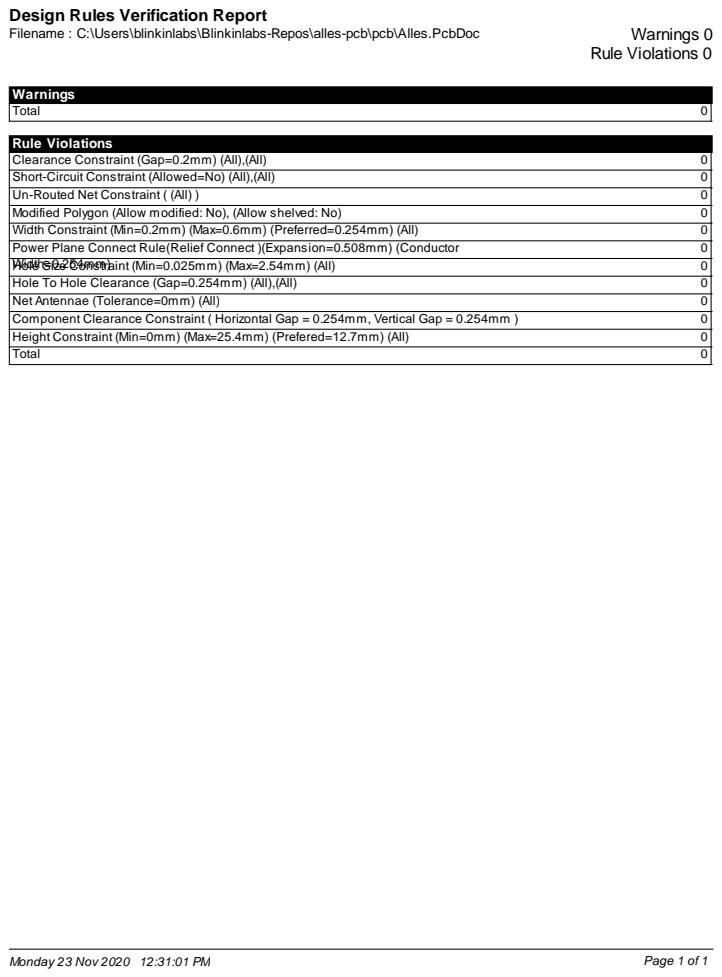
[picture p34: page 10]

Design Rules Verification Report

Rule Violations
Power Plane Connect Rule(Relief Connect )(Expansion=0.508mm) (Conductor
Width=0.254mm)

# Electrical Rules Check Report

Class | Document | Message Successful Compile for Alles.PrjPcb
Monday 23 Nov 2020 12:31:02 PM | Page 1 of 1

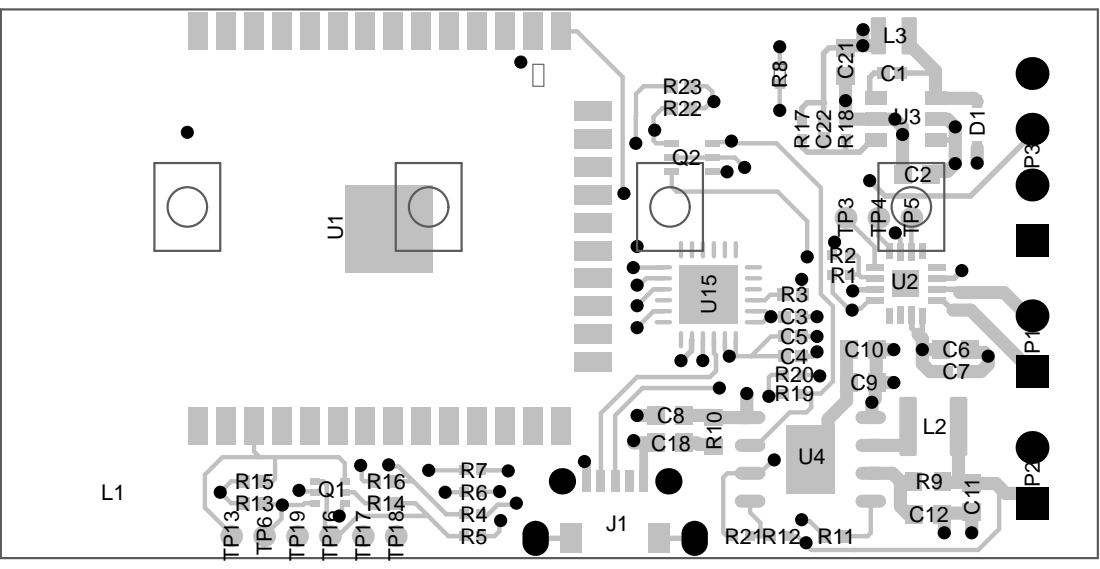
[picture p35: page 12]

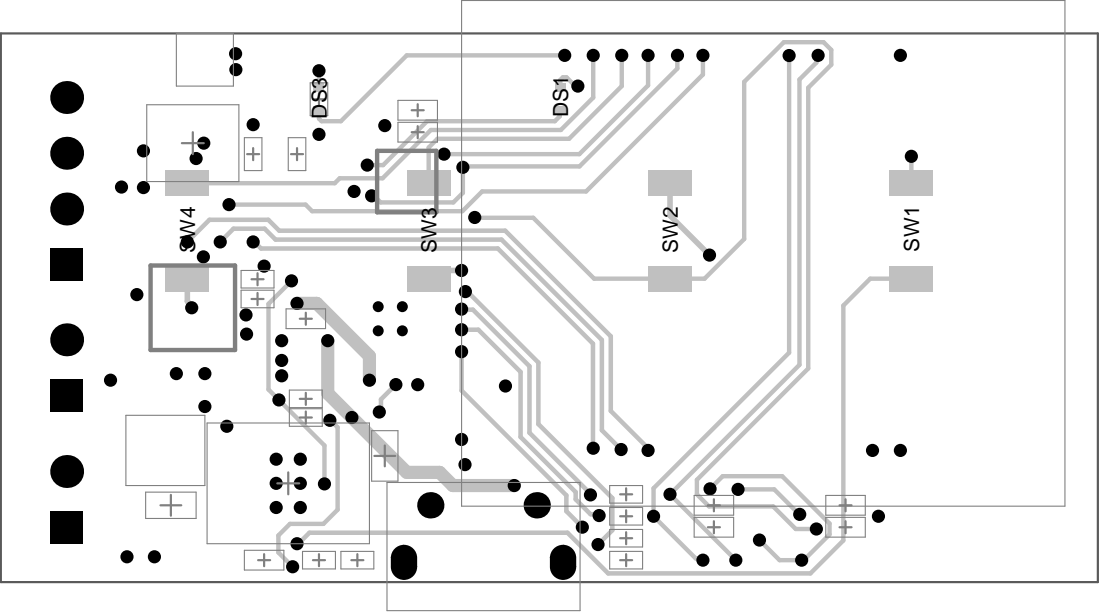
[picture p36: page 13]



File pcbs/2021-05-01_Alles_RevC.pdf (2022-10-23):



DESIGN NOTE:
Example text for informational
design notes .

Example text for critical
design notes.

Example text for cautionary

LAYOUT NOTE:
layout guidelines.


Off-board component (optional)



USB-to-Serial converter


Speaker is 4ohm
Gain is set to 6dB

According to the datasheet 'electrical characteristics' table, maximum power output with 12dB
setting into 4ohm load is 3.2W. From the 'efficiency vs output power' section, the efficiency
with a 4ohm speaker is roughly 80%, so the input power would need to be 4W. Finally, to derate
the power output to a 6dB setting, the maximum output would be 1/4 of the 12dB setting, or 1W.

Using that number, the maximum input current to the device with a 5V power supply can be
calculated as:

Note: GAIN tied high in project description,
possible to change with resistor jumper


Battery sense (enable only when measuring battery)

* Vcharge: 4.2V
* max charge current: 500mA @2K reference
* STAT is active pull down

Power draw in hibernation mode:
* ADP2108 has 18uA quiecenct current
* low load efficiency = 88%, esp takes 10uA in deep sleep/hibernate
* Total <50uA @battery (verified in RevB)

See Microchip App note AN1149

5V boost (enable when speaker active)




Design Rules Verification Report

Rule Violations
Power Plane Connect Rule(Relief Connect )(Expansion=0.508mm) (Conductor
Width=0.254mm)

# Electrical Rules Check Report

Class | | Document | Message
Warning | | [03] ESP32.SchDoc | 5V_EN contains IO Pin and Output Port objects (Pin U1-33, Port 5V_EN).
Warning | | [03] ESP32.SchDoc | BAT_SENSE_EN contains IO Pin and Output Port objects (Pin U1-8, Port
BAT_SENSE_EN). Warning | [03] ESP32.SchDoc | CHARGE_STAT contains IO Pin and Input Port objects (Pin U1-9, Port
| | | CHARGE_STAT).
Warning | | [04] Serial Console.SchDoc | Component U15 CP2104-F03-GM at 2400mil,5600mil: Component
| | | revision
Wa | is Out of Date. rning | [06] Power Supply.SchDoc | Floating Power Object 3.3Vat (8600mil,2200mil)
Warning | | [06] Power Supply.SchDoc | Floating Power Object 5Vat (8600mil,2400mil)
Warning | | [06] Power Supply.SchDoc | Floating Power Object 5V_USB at (8600mil,2800mil)
Warning | | [06] Power Supply.SchDoc | Floating Power Object GND at (8600mil,1800mil)
Warning | | [06] Power Supply.SchDoc | Floating Power Object V_BAT at (8600mil,2000mil)
Warning | | [06] Power Supply.SchDoc | Floating Power Object V_SWITCH at (8600mil,2600mil)
Saturday 1 May 2021 8:49:26 PM | Page 1 of 1


Layer | Name | Material | Thickness | Constant

Top Overlay
Top Solder | SM-001 | 0.013mm | 4

1 | Top Layer | Copper | 0.035mm

Dielectric 2 | PP-022 | 0.200mm | 4.6

2 | Layer 1 | Copper | 0.018mm

Dielectric 3 | Core-039 | 0.665mm | 4.8

3 | Layer 2 | Copper | 0.018mm

Dielectric 4 | PP-022 | 0.200mm | 4.6

4 | Bottom Layer | Copper | 0.035mm

Bottom Solder | SM-001 | 0.013mm
Bottom Overlay




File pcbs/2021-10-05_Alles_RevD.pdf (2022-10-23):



DESIGN NOTE:
Example text for informational
design notes .

Example text for critical
design notes.

Example text for cautionary

LAYOUT NOTE:
layout guidelines.


Off-board component (optional)


Pins are fixed function, can't change
Pin assignment for project firmware
Pins assigned through GPMUX, can change

Set high to enable 5V power supply

Set high to eable battery voltage measurement
(requires internal pullup) high when battery charged

Support for optional MIDI input

(must be on RTC GPIO pin)

Note: use 2.5mm tall buttons


USB-to-Serial converter

Note: CP2102 needs resistor divider on USB_VBUS
Note: CP2102 recommends 1k pullup on reset

Note: CP2102 configured in 'bus powered' mode

Title:


Speaker is 4ohm
Gain is set to 6dB

According to the datasheet 'electrical characteristics' table, maximum power output with 12dB
setting into 4ohm load is 3.2W. From the 'efficiency vs output power' section, the efficiency
with a 4ohm speaker is roughly 80%, so the input power would need to be 4W. Finally, to derate
the power output to a 6dB setting, the maximum output would be 1/4 of the 12dB setting, or 1W.

Using that number, the maximum input current to the device with a 5V power supply can be
calculated as:

Note: GAIN tied high in project description,
possible to change with resistor jumper


Battery sense (enable only when measuring battery)

* Vcharge: 4.2V
* max charge current: 500mA @2K reference
* STAT is active pull down

Power draw in hibernation mode:
* ADP2108 has 18uA quiecenct current
* low load efficiency = 88%, esp takes 10uA in deep sleep/hibernate
* Total <50uA @battery (verified in RevB)

See Microchip App note AN1149

5V boost (enable when speaker active)




Design Rules Verification Report

Rule Violations
Power Plane Connect Rule(Relief Connect )(Expansion=0.508mm) (Conductor
Width=0.254mm)

# Electrical Rules Check Report

Class | Document | Message
Warning | [03] ESP32.SchDoc | 5V_EN contains IO Pin and Output Port objects (Pin U1-33, Port 5V_EN).
Warning | [03] ESP32.SchDoc | BAT_SENSE_EN contains IO Pin and Output Port objects (Pin U1-8, Port
BAT_SENSE_EN). Warning | [03] ESP32.SchDoc | CHARGE_STAT contains IO Pin and Input Port objects (Pin U1-9, Port
| | CHARGE_STAT).
Warning | [06] Power Supply.SchDoc | Floating Power Object 3.3Vat (8600mil,2200mil)
Warning | [06] Power Supply.SchDoc | Floating Power Object 5Vat (8600mil,2400mil)
Warning | [06] Power Supply.SchDoc | Floating Power Object 5V_USB at (8600mil,2800mil)
Warning | [06] Power Supply.SchDoc | Floating Power Object GND at (8600mil,1800mil)
Warning | [06] Power Supply.SchDoc | Floating Power Object V_BAT at (8600mil,2000mil)
Warning | [06] Power Supply.SchDoc | Floating Power Object V_SWITCH at (8600mil,2600mil)
Warning | [04] Serial Console.SchDoc | Net USB_RESET has no driving source (Pin R3-1, Pin U15-9)
Tuesday 5 Oct 2021 12:25:21 AM | Page 1 of 1





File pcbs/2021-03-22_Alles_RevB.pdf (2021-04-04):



DESIGN NOTE:
Example text for informational
design notes .

Example text for critical
design notes.

Example text for cautionary

LAYOUT NOTE:
layout guidelines.


Off-board component (optional)



USB-to-Serial converter


Speaker is 4ohm
Gain is set to 6dB

According to the datasheet 'electrical characteristics' table, maximum power output with 12dB
setting into 4ohm load is 3.2W. From the 'efficiency vs output power' section, the efficiency
with a 4ohm speaker is roughly 80%, so the input power would need to be 4W. Finally, to derate
the power output to a 6dB setting, the maximum output would be 1/4 of the 12dB setting, or 1W.

Using that number, the maximum input current to the device with a 5V power supply can be
calculated as:

Note: GAIN tied high in project description,
possible to change with resistor jumper


Battery sense (enable only when measuring battery)

Vcharge: 4.2V
max charge current: 500mA @2K reference

Power draw in hibernation mode:
* ADP2108 has 18uA quiecenct current
* low load efficiency = 88%, esp takes 10uA in deep sleep/hibernate
* Total <50uA @battery

See Microchip App note AN1149

5V boost (enable when speaker active)




Design Rules Verification Report

Rule Violations
Power Plane Connect Rule(Relief Connect )(Expansion=0.508mm) (Conductor
Width=0.254mm)

Clearance Constraint (Gap=0.2mm) (All),(All)
Clearance Constraint: (0.193mm < 0.2mm) Between Track (27.447mm,3.597mm)(27.447mm,4.075mm) on Top Layer And
Clearance Constraint: (0.127mm < 0.2mm) Between Track (27.447mm,4.075mm)(27.509mm,4.137mm) on Top Layer And
Clearance Constraint: (0.193mm < 0.2mm) Between Track (27.447mm,4.075mm)(27.509mm,4.137mm) on Top Layer And
Clearance Constraint: (0.127mm < 0.2mm) Between Track (27.509mm,4.137mm)(27.509mm,6.138mm) on Top Layer And
Clearance Constraint: (0.193mm < 0.2mm) Between Track (27.509mm,4.137mm)(27.509mm,6.138mm) on Top Layer And
Clearance Constraint: (0.127mm < 0.2mm) Between Track (27.509mm,6.138mm)(29.719mm,8.347mm) on Top Layer And
Clearance Constraint: (0.127mm < 0.2mm) Between Track (27.841mm,6mm)(29.856mm,8.015mm) on Top Layer And Track
Clearance Constraint: (0.127mm < 0.2mm) Between Track (29.719mm,8.347mm)(32.25mm,8.347mm) on Top Layer And

# Electrical Rules Check Report

Class | | Document | Message
Warning | | [03] ESP32.SchDoc | 5V_EN contains IO Pin and Output Port objects (Pin U1-33, Port 5V_EN).
Warning | | [03] ESP32.SchDoc | BAT_SENSE_EN contains IO Pin and Output Port objects (Pin U1-8, Port
BAT_SENSE_EN). Warning | [03] ESP32.SchDoc | CHARGE_STAT contains IO Pin and Input Port objects (Pin U1-9, Port
| | | CHARGE_STAT).
Warning | | [04] Serial Console.SchDoc | Component U15 CP2104-F03-GM at 2400mil,5600mil: Component
| | | revision
Wa | is Out of Date. rning | [03] ESP32.SchDoc | EXT_SENSE contains IO Pin and Input Port objects (Pin U1-14, Port
EXT_SENSE). Warning | [06] Power Supply.SchDoc | Floating Power Object 3.3Vat (8600mil,2200mil)
Warning | | [06] Power Supply.SchDoc | Floating Power Object 5Vat (8600mil,2400mil)
Warning | | [06] Power Supply.SchDoc | Floating Power Object 5V_USB at (8600mil,2800mil)
Warning | | [06] Power Supply.SchDoc | Floating Power Object GND at (8600mil,1800mil)
Warning | | [06] Power Supply.SchDoc | Floating Power Object V_BAT at (8600mil,2000mil)
Warning | | [06] Power Supply.SchDoc | Floating Power Object V_SWITCH at (8600mil,2600mil)
Monday 22 Mar 2021 10:54:48 AM | Page 1 of 1


Layer | Name | Material | Thickness | Constant

Top Overlay
Top Solder | SM-001 | 0.013mm | 4

1 | Top Layer | Copper | 0.035mm

Dielectric 2 | PP-022 | 0.200mm | 4.6

2 | Layer 1 | Copper | 0.018mm

Dielectric 3 | Core-039 | 0.665mm | 4.8

3 | Layer 2 | Copper | 0.018mm

Dielectric 4 | PP-022 | 0.200mm | 4.6

4 | Bottom Layer | Copper | 0.035mm

Bottom Solder | SM-001 | 0.013mm
Bottom Overlay




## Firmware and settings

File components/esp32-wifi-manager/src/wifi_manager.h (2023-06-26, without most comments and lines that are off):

#define WIFI_MANAGER_H_INCLUDED
#include <stdbool.h>
#include <esp_wifi.h>
#ifdef __cplusplus
extern "C" {
#endif
#define MAX_SSID_SIZE						32
#define MAX_PASSWORD_SIZE					64
#define MAX_AP_NUM 							15
#define WIFI_MANAGER_MAX_RETRY_START_AP		CONFIG_WIFI_MANAGER_MAX_RETRY_START_AP
#define WIFI_MANAGER_RETRY_TIMER			CONFIG_WIFI_MANAGER_RETRY_TIMER
#define WIFI_MANAGER_SHUTDOWN_AP_TIMER		CONFIG_WIFI_MANAGER_SHUTDOWN_AP_TIMER
#define WIFI_MANAGER_TASK_PRIORITY			CONFIG_WIFI_MANAGER_TASK_PRIORITY
#define AP_AUTHMODE 						WIFI_AUTH_WPA2_PSK
#define DEFAULT_AP_SSID_HIDDEN 				0
#define DEFAULT_AP_SSID 					CONFIG_DEFAULT_AP_SSID
#define DEFAULT_AP_PASSWORD 				CONFIG_DEFAULT_AP_PASSWORD
#define DEFAULT_HOSTNAME					"alles"
#define DEFAULT_AP_BANDWIDTH 					WIFI_BW_HT20
#define DEFAULT_AP_CHANNEL 					CONFIG_DEFAULT_AP_CHANNEL
#define DEFAULT_AP_IP						CONFIG_DEFAULT_AP_IP
#define DEFAULT_AP_GATEWAY					CONFIG_DEFAULT_AP_GATEWAY
#define DEFAULT_AP_NETMASK					CONFIG_DEFAULT_AP_NETMASK
#define DEFAULT_AP_MAX_CONNECTIONS		 	CONFIG_DEFAULT_AP_MAX_CONNECTIONS
#define DEFAULT_AP_BEACON_INTERVAL 			CONFIG_DEFAULT_AP_BEACON_INTERVAL
#define DEFAULT_STA_ONLY 					1
#define DEFAULT_STA_POWER_SAVE 				WIFI_PS_NONE
#define JSON_ONE_APP_SIZE					99
#define JSON_IP_INFO_SIZE 					159
#define WPA2_MINIMUM_PASSWORD_LENGTH		8
typedef enum message_code_t {
	NONE = 0,
	WM_ORDER_START_HTTP_SERVER = 1,
	WM_ORDER_STOP_HTTP_SERVER = 2,
	WM_ORDER_START_DNS_SERVICE = 3,
	WM_ORDER_STOP_DNS_SERVICE = 4,
	WM_ORDER_START_WIFI_SCAN = 5,
	WM_ORDER_LOAD_AND_RESTORE_STA = 6,
	WM_ORDER_CONNECT_STA = 7,
	WM_ORDER_DISCONNECT_STA = 8,
	WM_ORDER_START_AP = 9,
	WM_EVENT_STA_DISCONNECTED = 10,
	WM_EVENT_SCAN_DONE = 11,
	WM_EVENT_STA_GOT_IP = 12,
	WM_ORDER_STOP_AP = 13,
	WM_MESSAGE_CODE_COUNT = 14
}message_code_t;
typedef enum update_reason_code_t {
	UPDATE_CONNECTION_OK = 0,
	UPDATE_FAILED_ATTEMPT = 1,
	UPDATE_USER_DISCONNECT = 2,
	UPDATE_LOST_CONNECTION = 3
}update_reason_code_t;
typedef enum connection_request_made_by_code_t{
	CONNECTION_REQUEST_NONE = 0,
	CONNECTION_REQUEST_USER = 1,
	CONNECTION_REQUEST_AUTO_RECONNECT = 2,
	CONNECTION_REQUEST_RESTORE_CONNECTION = 3,
	CONNECTION_REQUEST_MAX = 0x7fffffff
}connection_request_made_by_code_t;
struct wifi_settings_t{
	uint8_t ap_ssid[MAX_SSID_SIZE];
	uint8_t ap_pwd[MAX_PASSWORD_SIZE];
	uint8_t ap_channel;
	uint8_t ap_ssid_hidden;
	wifi_bandwidth_t ap_bandwidth;
	bool sta_only;
	wifi_ps_type_t sta_power_save;
	bool sta_static_ip;
	esp_netif_ip_info_t sta_static_ip_config;
};
extern struct wifi_settings_t wifi_settings;
typedef struct{
	message_code_t code;
	void *param;
} queue_message;
esp_netif_t* wifi_manager_get_esp_netif_sta();
esp_netif_t* wifi_manager_get_esp_netif_ap();
void wifi_manager_start();
void wifi_manager_destroy();
void filter_unique( wifi_ap_record_t * aplist, uint16_t * ap_num);
void wifi_manager( void * pvParameters );
char* wifi_manager_get_ap_list_json();
char* wifi_manager_get_ip_info_json();
void wifi_manager_scan_async();
esp_err_t wifi_manager_save_sta_config();
bool wifi_manager_fetch_wifi_sta_config();
wifi_config_t* wifi_manager_get_wifi_sta_config();
void wifi_manager_connect_async();
void wifi_manager_scan_awifi_manager_send_messagesync();
void wifi_manager_disconnect_async();
bool wifi_manager_lock_json_buffer(TickType_t xTicksToWait);
void wifi_manager_unlock_json_buffer();
void wifi_manager_generate_ip_info_json(update_reason_code_t update_reason_code);
void wifi_manager_clear_ip_info_json();
void wifi_manager_generate_acess_points_json();
void wifi_manager_clear_access_points_json();
void wifi_manager_initialise_mdns();
bool wifi_manager_lock_sta_ip_string(TickType_t xTicksToWait);
void wifi_manager_unlock_sta_ip_string();
char* wifi_manager_get_sta_ip_string();
void wifi_manager_safe_update_sta_ip_string(uint32_t ip);
void wifi_manager_set_callback(message_code_t message_code, void (*func_ptr)(void*) );
BaseType_t wifi_manager_send_message(message_code_t code, void *param);
BaseType_t wifi_manager_send_message_to_front(message_code_t code, void *param);
#ifdef __cplusplus
}
#endif

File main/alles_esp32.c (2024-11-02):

// alles_esp32.c
// Alles multicast synthesizer
// Brian Whitman
// brian@variogr.am

#include "alles.h"
#define configUSE_TASK_NOTIFICATIONS 1
//#define configTASK_NOTIFICATION_ARRAY_ENTRIES 2
#define MAX_WIFI_WAIT_S 120

#include "freertos/FreeRTOS.h"
#include "freertos/task.h"
#include "freertos/queue.h"
#include "freertos/event_groups.h"
#include "esp_wifi.h"
#include "esp_system.h"
#include "esp_https_ota.h"
#include "esp_ota_ops.h"
#include "esp_intr_alloc.h"
#include "esp_attr.h"
#include "esp_event.h"
#include "esp_log.h"
#include "esp_err.h"
#include "esp_sleep.h"
#include "driver/uart.h"
#include "nvs_flash.h"
#include "lwip/netdb.h"
#include "wifi_manager.h"
#include "http_app.h"
#include "power.h"

#include "driver/i2s_std.h"
#include "driver/gpio.h"
i2s_chan_handle_t tx_handle;


// This can be 32 bit, int32_t -- helpful for digital output to a i2s->USB teensy3 board
#define I2S_SAMPLE_TYPE I2S_BITS_PER_SAMPLE_16BIT
typedef int16_t i2s_sample_type;


// Button handlers
void wifi_reconfigure();
extern esp_err_t buttons_init();
void esp_show_debug(uint8_t type);

// wifi and multicast
extern wifi_config_t* wifi_manager_config_sta ;
extern void mcast_listen_task(void *pvParameters);

uint8_t board_level;
uint8_t status;
uint8_t debug_on = 0;

// For CPU usage
unsigned long last_task_counters[MAX_TASKS];

// mutex that locks writes to the delta queue
SemaphoreHandle_t xQueueSemaphore;

void delay_ms(uint32_t ms) {
    vTaskDelay(ms / portTICK_PERIOD_MS);
}

uint8_t board_level = ALLES_BOARD_V2;
uint8_t status = RUNNING;

char githash[8];

// Button event
extern xQueueHandle gpio_evt_queue;

// Task handles for the renderers, multicast listener and main
TaskHandle_t mcastTask = NULL;
TaskHandle_t parseTask = NULL;
TaskHandle_t upgradeTask = NULL;

TaskHandle_t alles_handle;
TaskHandle_t alles_parse_handle;
TaskHandle_t alles_receive_handle;
TaskHandle_t amy_render_handle;
TaskHandle_t alles_fill_buffer_handle;
TaskHandle_t idle_0_handle;
TaskHandle_t idle_1_handle;


#define ALLES_TASK_COREID (1)
#define ALLES_PARSE_TASK_COREID (0)
#define ALLES_RECEIVE_TASK_COREID (1)
#define ALLES_RENDER_TASK_COREID (0)
#define ALLES_FILL_BUFFER_TASK_COREID (1)
#define ALLES_PARSE_TASK_PRIORITY (ESP_TASK_PRIO_MIN +2)
#define ALLES_RECEIVE_TASK_PRIORITY (ESP_TASK_PRIO_MIN + 3)
#define ALLES_RENDER_TASK_PRIORITY (ESP_TASK_PRIO_MAX-1 )
#define ALLES_FILL_BUFFER_TASK_PRIORITY (ESP_TASK_PRIO_MAX-1)
#define ALLES_TASK_NAME             "alles_task"
#define ALLES_PARSE_TASK_NAME       "alles_par_task"
#define ALLES_RECEIVE_TASK_NAME     "alles_rec_task"
#define ALLES_RENDER_TASK_NAME      "alles_r_task"
#define ALLES_FILL_BUFFER_TASK_NAME "alles_fb_task"
#define ALLES_TASK_STACK_SIZE    (4 * 1024) 
#define ALLES_PARSE_TASK_STACK_SIZE (8 * 1024)
#define ALLES_RECEIVE_TASK_STACK_SIZE (4 * 1024)
#define ALLES_RENDER_TASK_STACK_SIZE (8 * 1024)
#define ALLES_FILL_BUFFER_TASK_STACK_SIZE (8 * 1024)


// Battery status for V2 board. If no v2 board, will stay at 0
uint8_t battery_mask = 0;

// AMY synth states
extern struct state amy_global;
extern uint32_t event_counter;
extern uint32_t message_counter;


// Render the second core
void esp_render_task( void * pvParameters) {
    while(1) {
        ulTaskNotifyTake(pdTRUE, portMAX_DELAY);
        amy_render(0, AMY_OSCS/2, 1);
        xTaskNotifyGive(alles_fill_buffer_handle);
    }
}

// Make AMY's FABT run forever , as a FreeRTOS task 
void esp_fill_audio_buffer_task() {
    while(1) {
        AMY_PROFILE_START(AMY_ESP_FILL_BUFFER)

        // Get ready to render
        amy_prepare_buffer();
        // Tell the other core to start rendering
        xTaskNotifyGive(amy_render_handle);
        // Render me
        amy_render(AMY_OSCS/2, AMY_OSCS, 0);
        // Wait for the other core to finish
        ulTaskNotifyTake(pdTRUE, portMAX_DELAY);

        // Write to i2s
        int16_t *block = amy_fill_buffer();
        AMY_PROFILE_STOP(AMY_ESP_FILL_BUFFER)

        // We turn off writing to i2s on r10 when doing on chip debugging because of pins
        #ifndef TULIP_R10_DEBUG
        size_t written = 0;
        i2s_channel_write(tx_handle, block, AMY_BLOCK_SIZE * AMY_BYTES_PER_SAMPLE * AMY_NCHANS, &written, portMAX_DELAY);
        if(written != AMY_BLOCK_SIZE * AMY_BYTES_PER_SAMPLE * AMY_NCHANS) {
            fprintf(stderr,"i2s underrun: %d vs %d\n", written, AMY_BLOCK_SIZE * AMY_BYTES_PER_SAMPLE * AMY_NCHANS);
        }
        #endif


    }
}

// Make AMY's parse task run forever, as a FreeRTOS task (with notifications)
void esp_parse_task() {
    while(1) {
        ulTaskNotifyTake(pdTRUE, portMAX_DELAY);
        alles_parse_message(message_start_pointer, message_length);
        xTaskNotifyGive(mcastTask);
    }
}


// init AMY from the esp. wraps some amy funcs in a task to do multicore rendering on the ESP32 
amy_err_t esp_amy_init() {
    amy_start(2, 0, 1, 0);
    amy_global.latency_ms = ALLES_LATENCY_MS;
    // We create a mutex for changing the event queue and pointers as two tasks do it at once
    xQueueSemaphore = xSemaphoreCreateMutex();

    // Create the second core rendering task
    xTaskCreatePinnedToCore(&esp_render_task, ALLES_RENDER_TASK_NAME, ALLES_RENDER_TASK_STACK_SIZE, NULL, ALLES_RENDER_TASK_PRIORITY, &amy_render_handle, ALLES_RENDER_TASK_COREID);

    // Wait for the render tasks to get going before starting the i2s task
    delay_ms(100);

    // And the fill audio buffer thread, combines, does volume & filters
    xTaskCreatePinnedToCore(&esp_fill_audio_buffer_task, ALLES_FILL_BUFFER_TASK_NAME, ALLES_FILL_BUFFER_TASK_STACK_SIZE, NULL, ALLES_FILL_BUFFER_TASK_PRIORITY, &alles_fill_buffer_handle, ALLES_FILL_BUFFER_TASK_COREID);

    // Grab the idle handles while we're here, we use them for CPU usage reporting
    idle_0_handle = xTaskGetIdleTaskHandleForCPU(0);
    idle_1_handle = xTaskGetIdleTaskHandleForCPU(1);
    return AMY_OK;
}


// Show a CPU usage counter. This shows the delta in use since the last time you called it
void esp_show_debug(uint8_t type) { 
    TaskStatus_t *pxTaskStatusArray;
    volatile UBaseType_t uxArraySize, x, i;
    const char* const tasks[] = { ALLES_PARSE_TASK_NAME, ALLES_RECEIVE_TASK_NAME, ALLES_RENDER_TASK_NAME, ALLES_FILL_BUFFER_TASK_NAME, "main", "wifi", "IDLE0", "IDLE1", 0 }; 
    const uint8_t cores[] = {ALLES_PARSE_TASK_COREID, ALLES_RECEIVE_TASK_COREID, ALLES_RENDER_TASK_COREID, ALLES_FILL_BUFFER_TASK_COREID, 0, 0, 0, 1, 0};

    uxArraySize = uxTaskGetNumberOfTasks();
    pxTaskStatusArray = pvPortMalloc( uxArraySize * sizeof( TaskStatus_t ) );
    uxArraySize = uxTaskGetSystemState( pxTaskStatusArray, uxArraySize, NULL );
    unsigned long counter_since_last[MAX_TASKS];
    //unsigned long ulTotalRunTime = 0;
    unsigned long ulTotalRunTime_per_core[2];
    ulTotalRunTime_per_core[0] = 0;
    ulTotalRunTime_per_core[1] = 0;

    //TaskStatus_t xTaskDetails;

    // We have to check for the names we want to track
    for(i=0;i<MAX_TASKS;i++) { // for each name
        counter_since_last[i] = 0;
        for(x=0; x<uxArraySize; x++) { // for each task
            if(strcmp(pxTaskStatusArray[x].pcTaskName, tasks[i])==0) {
                counter_since_last[i] = pxTaskStatusArray[x].ulRunTimeCounter - last_task_counters[i];
                last_task_counters[i] = pxTaskStatusArray[x].ulRunTimeCounter;
                //ulTotalRunTime = ulTotalRunTime + counter_since_last[i];
                ulTotalRunTime_per_core[cores[i]] += counter_since_last[i];
            }
        }
    }
    printf("------ CPU usage since last call to debug()\n");
    for(i=0;i<MAX_TASKS;i++) {
        printf("%d %-15s\t%-15ld\t\t%2.2f%%\n", cores[i], tasks[i], counter_since_last[i], (float)counter_since_last[i]/ulTotalRunTime_per_core[cores[i]] * 100.0);
    }   
    printf("------\nEvent queue size %d / %d. Received %" PRIu32 " events and %" PRIu32 " messages\n", amy_global.event_qsize, AMY_EVENT_FIFO_LEN, event_counter, message_counter);
    event_counter = 0;
    message_counter = 0;
    vPortFree(pxTaskStatusArray);

}

   

// Setup I2S
amy_err_t setup_i2s(void) {
    i2s_chan_config_t chan_cfg = I2S_CHANNEL_DEFAULT_CONFIG(I2S_NUM_AUTO, I2S_ROLE_MASTER);
    i2s_new_channel(&chan_cfg, &tx_handle, NULL);
    i2s_std_config_t std_cfg = {
        .clk_cfg = I2S_STD_CLK_DEFAULT_CONFIG(AMY_SAMPLE_RATE),
        .slot_cfg = I2S_STD_MSB_SLOT_DEFAULT_CONFIG(I2S_DATA_BIT_WIDTH_16BIT, I2S_SLOT_MODE_MONO),
        .gpio_cfg = {
            .mclk = I2S_GPIO_UNUSED,
            .bclk = CONFIG_I2S_BCLK,
            .ws = CONFIG_I2S_LRCLK,
            .dout = CONFIG_I2S_DIN,
            .din = I2S_GPIO_UNUSED,
            .invert_flags = {
                .mclk_inv = false,
                .bclk_inv = false,
                .ws_inv = false,
            },
        },
    };
    /* Initialize the channel */
    i2s_channel_init_std_mode(tx_handle, &std_cfg);

    /* Before writing data, start the TX channel first */
    i2s_channel_enable(tx_handle);
    return AMY_OK;
}




// callback to let us know when we have wifi set up ok.
void wifi_connected(void *pvParameter){
    ip_event_got_ip_t* param = (ip_event_got_ip_t*)pvParameter;

    char str_ip[16];
    esp_ip4addr_ntoa(&param->ip_info.ip, str_ip, IP4ADDR_STRLEN_MAX);

    ESP_LOGI("main", "I have a connection and my IP is %s!", str_ip);
    status |= WIFI_MANAGER_OK;
}


// Called when the WIFI button is hit. Deletes the saved SSID/pass and restarts into the captive portal
void wifi_reconfigure() {
     printf("reconfigure wifi\n");

    if(wifi_manager_config_sta){
        memset(wifi_manager_config_sta, 0x00, sizeof(wifi_config_t));
    }

    if(wifi_manager_lock_json_buffer( portMAX_DELAY )){
        wifi_manager_generate_ip_info_json( UPDATE_USER_DISCONNECT );
        wifi_manager_unlock_json_buffer();
    }

    wifi_manager_save_sta_config();
    delay_ms(100);
    esp_restart();
}

void firmware_upgrade( void * pvParameters) {
    esp_http_client_config_t config = {
        .url = "https://github.com/shorepine/alles/raw/main/ota/alles.bin",
        .cert_pem = NULL,
        .transport_type = HTTP_TRANSPORT_OVER_SSL,
        .skip_cert_common_name_check = true,
    };
    esp_https_ota_config_t ota_config = {
        .http_config = &config,
    };
    esp_err_t ret = esp_https_ota(&ota_config);
    if (ret == ESP_OK) {
        esp_restart();
    } else {
        printf("Problem with upgrade %i %s\n", ret, esp_err_to_name(ret));
    }
    esp_restart();
}

void power_monitor() {
    power_status_t power_status;

    const amy_err_t ret = power_read_status(&power_status);
    if(ret != AMY_OK)
        return;

    // print a debugging power status every few seconds to the monitor 
    /*
    char buf[100];
    snprintf(buf, sizeof(buf),
        "powerStatus: power_source=\"%s\",charge_status=\"%s\",wall_v=%0.3f,battery_v=%0.3f\n",
        (power_status.power_source == POWER_SOURCE_WALL ? "wall" : "battery"),
        (power_status.charge_status == POWER_CHARGE_STATUS_CHARGING ? "charging" :
            (power_status.charge_status == POWER_CHARGE_STATUS_CHARGED ? "charged" : " discharging")),
        power_status.wall_voltage/1000.0,
        power_status.battery_voltage/1000.0
        );

    printf(buf);
    */

    battery_mask = 0;

    switch(power_status.charge_status) {
        case POWER_CHARGE_STATUS_CHARGED:
            battery_mask = battery_mask | BATTERY_STATE_CHARGED;
            break;
        case POWER_CHARGE_STATUS_CHARGING:
            battery_mask = battery_mask | BATTERY_STATE_CHARGING;
            break;
        case POWER_CHARGE_STATUS_DISCHARGING:
            battery_mask = battery_mask | BATTERY_STATE_DISCHARGING;
            break;        
    }

    float voltage = power_status.battery_voltage/1000.0;
    if(voltage > 3.95) battery_mask = battery_mask | BATTERY_VOLTAGE_4; else 
    if(voltage > 3.80) battery_mask = battery_mask | BATTERY_VOLTAGE_3; else 
    if(voltage > 3.60) battery_mask = battery_mask | BATTERY_VOLTAGE_2; else 
    if(voltage > 3.30) battery_mask = battery_mask | BATTERY_VOLTAGE_1;
}

void turn_off() {
    debleep();
    delay_ms(500);
    // TODO: Where did these come from? JTAG?
    gpio_pullup_dis(14);
    gpio_pullup_dis(15);
    esp_sleep_enable_ext1_wakeup((1ULL<<BUTTON_WAKEUP),ESP_EXT1_WAKEUP_ALL_LOW);
    esp_deep_sleep_start();
}
void app_main() {
    const esp_app_desc_t * app_desc = esp_app_get_description(); // esp_ota_get_app_description();
    // version comes back as version "v0.1-alpha-259-g371d500-dirty"
    // the v0.1-alpha seems hardcoded, setting cmake PROJECT_VER replaces the more useful git describe line
    // so we'll have to parse the commit ID out
    // or maybe just get date time as YYYYMMDDHHMMSS? 

    if(strlen(app_desc->version) > 20) {
        if(app_desc->version[strlen(app_desc->version)-1] == 'y') {
            strncpy(githash, app_desc->version + strlen(app_desc->version)-13, 7);
        } else {
            strncpy(githash, app_desc->version + strlen(app_desc->version)-7, 7);            
        }
        githash[7] = 0;
    }
    printf("Welcome to %s -- date %s time %s version %s [%s]\n", app_desc->project_name, app_desc->date, app_desc->time, app_desc->version, githash);

    for(uint8_t i=0;i<MAX_TASKS;i++) last_task_counters[i] = 0;
    check_init(&esp_event_loop_create_default, "Event");
    // TODO -- this does not properly detect DEVBOARD anymore, not a big deal for now, doesn't impact anything
    // if power init fails, we don't have blinkinlabs board, set board level to 0
    if(check_init(&power_init, "power")) {
        printf("No power IC, assuming DIY Alles\n");
        board_level = DEVBOARD; 
    }
    if(board_level == ALLES_BOARD_V2) {
        printf("Detected revB+ Alles\n");
        TimerHandle_t power_monitor_timer = xTimerCreate(
            "power_monitor",
            pdMS_TO_TICKS(5000),
            pdTRUE,
            NULL,
            power_monitor);
        xTimerStart(power_monitor_timer, 0);

    }

    // TODO: one of these interferes with the power monitor, not a big deal, we don't use both at once
    // Setup GPIO outputs for watching CPU usage on an oscilloscope 
    /*
    const gpio_config_t out_conf = {
         .mode = GPIO_MODE_OUTPUT,            
         .pin_bit_mask = (1ULL<<CPU_MONITOR_0) | (1ULL<<CPU_MONITOR_1) | (1ULL<<CPU_MONITOR_2),
    };
    gpio_config(&out_conf); 

    // Set them all to low
    gpio_set_level(CPU_MONITOR_0, 0); // use 0 as ground for the scope 
    gpio_set_level(CPU_MONITOR_1, 0); // use 1 for the rendering loop 
    gpio_set_level(CPU_MONITOR_2, 0); // use 2 for whatever you want 
    */

    check_init(&sync_init, "sync"); 
    check_init(&setup_i2s, "i2s");
    esp_amy_init();
    check_init(&buttons_init, "buttons"); // only one button for the protoboard, 4 for the blinkinlabs

    wifi_manager_start();
    wifi_manager_set_callback(WM_EVENT_STA_GOT_IP, &wifi_connected);


    // A funny story: in the early development of Alles, I had four prototype speakers with me as I flew a little
    // prop plane from YBL to YVR. The bag with the speakers went into the cargo hold of the prop plane and when we
    // landed everyone could hear this weird chiming noise -- it turns out all four speakers got turned on during the 
    // flight and at the time there was a bug where if it couldn't connect to the stored wifi, the power button
    // wouldn't be active either and all four speakers were stuck making the wifi chime. Quite a fun noise to hear in an
    // airplane! I didn't have any programming cables or a screwdriver with me so I had to put them all in a hotel 
    // safe covered with a pillow to get their batteries to die. 

    //So now they shut off after MAX_WIFI_WAIT_S if they can't connect.
    int64_t start_time = amy_sysclock();
    delay_ms(250);
    //heap_caps_print_heap_info(MALLOC_CAP_INTERNAL);

    while((!(status & WIFI_MANAGER_OK) && (status & RUNNING) )) {
        wifi_tone();
        for(uint8_t i=0;i<250;i++) { 
            if(!(status & RUNNING)) turn_off();
            delay_ms(10);
        }
        if(amy_sysclock() - start_time > (MAX_WIFI_WAIT_S*1000)) turn_off();
    }

    // We check for RUNNING as someone could have pressed power already
    if(!(status & RUNNING)) turn_off();

    // was + held down right now? if so check for updates
    if(status & UPDATE) {
        xTaskCreatePinnedToCore(&firmware_upgrade, "upgrade", 8192, NULL, 0, &upgradeTask, 0);
        while(1) {
            upgrade_tone();
            delay_ms(2000);
        }
    }


    delay_ms(500);
    amy_reset_oscs();

    // Setup the socket
    create_multicast_ipv4_socket();

    // Create the task that listens fro new incoming UDP messages (core 2)
    xTaskCreatePinnedToCore(&mcast_listen_task, ALLES_RECEIVE_TASK_NAME, ALLES_RECEIVE_TASK_STACK_SIZE, NULL, ALLES_RECEIVE_TASK_PRIORITY, &mcastTask, ALLES_RECEIVE_TASK_COREID);
    delay_ms(100);

    // Create the task that waits for UDP messages, parses them and puts them on the sequencer queue (core 1)
    xTaskCreatePinnedToCore(&esp_parse_task, ALLES_PARSE_TASK_NAME, ALLES_PARSE_TASK_STACK_SIZE, NULL, ALLES_PARSE_TASK_PRIORITY, &parseTask, ALLES_PARSE_TASK_COREID);

    // Schedule a "turning on" sound
    bleep(amy_sysclock());

    // Print free RAm
    //heap_caps_print_heap_info(MALLOC_CAP_INTERNAL);

    // Spin this core until the power off button is pressed, parsing events and making sounds
    while(status & RUNNING) {
        delay_ms(10);
    }

    // If we got here, the power off button was pressed 
    turn_off();
}

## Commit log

2018-06-12 preparing for multiple waveforms, also moving a pin because it is easier to solder
2018-08-19 Making this send mono again now that I've knocked down the noise issue. Less bytes over i2c, save some CPU. Could move it back with a different chip and do panning
2020-02-16 FM better integrated (but still noise)
    [alles.c]
2020-02-17 starting to think about sync, not working yet
    [alles.c]
2020-02-19 Lots of time fixes, sync pretty solid on 1 synth
    [alles.c]
2020-02-23 adding a song by kyle, bytebeat stubs, a fix for the clip crashing maybe
    [alles.c]
2020-02-26 new pin number for the PCB -- but it's noisy, so let's see
2020-03-01 kyle's song should work on any number of booted devices
2020-03-08 adding PCBs and pics
    [alles-pro.brd, alles-pro.sch, alles.fzz]
2020-03-11 Far less crackles when I >> 4 the PCM coming off of the dx7
    [alles.c]
2020-03-13 removing printf debugging in alles.py
2020-03-19 slight refactor to make new oscillators easier to manage
    [alles.c, alles.h, oscillators.cc]
2020-03-25 moving to 240MHz to get 10 voices, and trimming down the sawtooth slices to stop the wifi stack from rebooting
    [alles.c]
2020-03-25 fixing dumb bug in FM synth that prevented multiple voices to play
    [alles.c, alles.h]
2020-03-25 fix lowest KS note in a different place
    [oscillators.cc]
2020-03-25 working around a (i think) blipbuffer bug to set the buffer size to just the size of the i2s buffer
    [alles.c, oscillators.cc]
2020-03-27 Every 10s ping on the UDP thread, auto-healing list of clients
2020-04-21 refactoring the oscillators a bit to make new ones easier
    [alles.c, alles.h, oscillators.cc]
2020-06-01 Sleep on MIDI task, Tick rate now 500hz
2020-06-01 cleaning up, issues with multiple master clocks but rare condition
    [alles.c]
2021-03-05 Adding the ip5306 driver from Blinkinlabs
2021-03-06 ifdef for blinkinlabs board, battery status returned in sync command
2021-03-07 Merging in blinkinlabs drivers for LEDs, buttons & battery/power
2021-03-08 Return battery status & charge in a mask to decode it on the other end
2021-03-09 reduce power: use wifi ps, increase latency to 1000ms, turn off LEDs
2021-03-10 fix parsing bug int64/int32 for time rollover
    [alles.c]
2021-03-11 Adding esp32 wifi manager directly, as we had to make changes. captive wifi portal
2021-03-11 cleaned up buttons for protoboard vs blinkinlabs board
2021-03-12 adding buttons
2021-03-12 power button
2021-03-13 ensuring working on non-v1 board
2021-03-14 detect alles_v1 board and disable power features
2021-03-14 sync bug when giving a new timebase. starting midi debugging for bank/program changes
    [alles.c, alles.h]
2021-03-20 filter implementation
2021-03-20 adding filters & esp-dsp
2021-03-20 Nicer filter song
2021-03-22 fixing filter (thanks dan)
    [alles.c, alles.h]
2021-03-23 LFOs working, needs some help resetting / some quality of life changes
    [alles.c, alles.h]
2021-03-23 LFOs work, velocity now required to trigger notes
2021-03-24 global state now a mask; don't send TS to global events, deserialize velocity properly
2021-03-26 fix example in README to use velocity
2021-03-29 fixing python bug in velocity, readme cleanup, no more amp (vel does that now)
    [alles.c]
2021-03-30 reset() resets filter on all voices
2021-03-30 Larger partition, & splitting up alles.py
    [alles_partitions.csv]
2021-03-31 first version of PCM samples, using an 808 pack
2021-04-01 new partition map
    [alles_partitions.csv]
2021-04-02 adding blinkinlabs v2 pcbs
    [2021-03-22_Alles_RevB BOM.xlsx, 2021-03-22_Alles_RevB Pick Place.csv, Alles.PcbDoc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]
2021-04-20 Add make_lut.py; replace pulse with bandlimited impulse
    [oscillators.cc]
2021-04-20 Miller's cubic interp optimization; Real pulse wave with PWM
2021-04-25 Add soft clip; remove blip_buffer; fix ESP32 LEFT_ONLY word shuffle.
    [alles.c, oscillators.cc]
2021-04-25 Cubic interpolation of LUT; shorter sine LUT; added impulse LUT; pulse PWM as integrated difference of impulses.
    [oscillators.cc]
2021-05-06 revB power & buttons
2021-05-06 adding power.
2021-05-07 battery state
2021-05-07 midi mode works again. better sounds. buttons work on revB.
2021-05-08 reset osc after startup
    [alles.c]
2021-05-08 oscillator rendering one per osc, better CPU usage handler
    [alles.c]
2021-05-09 dumb bug on split renderer
    [alles.c]
2021-05-09 more testing, but can do 28 linear oscillators on one chip now
    [alles.c, alles.h]
2021-05-10 64 oscillators, removing floor, one FM patch for mem for now
    [alles.h]
2021-05-13 fixing delta bug, better usage reporting
    [alles.c, alles.h]
2021-05-17 filters work per oscillator now
    [alles.c, alles.h, wifi_manager.h]
2021-05-19 eq, (thanks dan!) 3 filter types, renaming LFO->mod
2021-05-23 Pitch-adaptive lookup tables; Triangle has its own tables.
2021-05-25 No more cumulative mixing, fixed filters, sine LUT starts in the right place
    [alles.c, alles.h]
2021-05-25 Higher priority i2s, ADSR is now a sample clock
2021-05-28 quad buffering to avoid clicks
    [alles.c, alles.h]
2021-05-28 sample type
2021-07-18 partial/partials cleanup. release special case for partial type
2021-07-24 fitting partials into esp32, some other similar changes
2021-07-25 cleaning up on esp32
2021-07-25 Ratio for ALGO includes LFOs, fixing CPU hit for partial patches
    [alles.c]
2021-07-25 chasing down a crackle on the i2s but getting there
    [alles.c]
2021-07-26 sync fixes; power monitor works on revB boards again
    [alles.c]
2021-08-06 newer IDF on the linux box, fixing up some compiler issues there too
    [alles.c, alles.h]
2021-08-10 fixed up a lot of soundio badness, and allowed to set channels & device ID at the CL for local Alles
2021-08-11 more sounds in the PCM bucket, need to add loops and choose these better
2021-08-14 stable PCM looping
    [alles_partitions.csv]
2021-10-08 removing BLE. fixing benL's issue
    [alles.h]
2021-10-10 More fully removing on-device MIDI; this will be moved to software alles as a relay
2021-11-11 douglas's error, some new idf stuff
    [alles.c]
2021-11-24 Moving PCM to a partition on chip to save room. Removing partials presets.
    [alles_partitions.csv]
2021-11-26 OTA working
    [alles_partitions.csv]
2021-11-26 partition change
    [alles_partitions.csv]
2021-11-27 putting partials back, OTA has LUTs baked in
    [alles_partitions.csv]
2021-11-30 fixing volume and multicast TTL
    [alles.c, alles.h]
2021-12-04 adding 4mb
    [alles_4mb_partitions.csv]
2022-06-21 fixing bp envelope to start at level4
    [alles.c]
2022-06-21 also do pitch BP
2022-06-22 schedling note off using alles timer, not python
2022-06-25 back to clamp at 20
2022-07-04 Cleanup alles build for esp32
2022-07-04 Added LFO for pitch and amp to dx7_simulator.
2022-07-05 fixing nan in envelope, no more pitch BPs per op
2022-07-05 Pitch envelope calculation fixed to match tx802, both fm.py and dx7_simulator.
2022-09-15 stage 2
2022-10-23 adding revD pcbs from blinklabs
    [2020-11-23_Alles_RevA BOM.xlsx, 2020-11-23_Alles_RevA Pick Place.csv, 2020-11-23_Alles_RevA.step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]
2023-02-24 merging in new AMY + fixing extern
    [alles.h]
2023-06-22 dweb2023 materials
2023-07-01 fixing up amy module
    [alles.h]
2023-07-23 Adding A60 speaker assembly guide
2023-12-09 alles esp32 fixes
2023-12-10 alles esp32 works on fxp
2024-06-13 removing millis(), amy now has this
2024-11-04 new style of insert_time

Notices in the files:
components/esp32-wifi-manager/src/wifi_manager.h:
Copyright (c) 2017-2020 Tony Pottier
